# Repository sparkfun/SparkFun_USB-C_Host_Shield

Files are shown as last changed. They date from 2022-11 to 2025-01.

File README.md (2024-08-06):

SparkFun USB-C Host Shield
========================================

<p align="center">
	<a href="https://github.com/sparkfun/SparkFun_USB-C_Host_Shield/issues" alt="Issues">
		</a>
	<a href="https://github.com/sparkfun/SparkFun_USB-C_Host_Shield/actions" alt="Actions">
		</a>
	<a href="https://github.com/sparkfun/SparkFun_USB-C_Host_Shield/blob/master/LICENSE.md" alt="License">
		</a>
	<a href="https://twitter.com/intent/follow?screen_name=sparkfun">
		</a>
</p>

SparkFun USB-C Host Shield (https://www.sparkfun.com/products/21247)

*[SparkFun USB-C Host Shield (DEV-21247)](https://www.sparkfun.com/products/21247)*

This new version of the [USB Host Shield](https://github.com/sparkfun/USB_Host_Shield) updates the USB Type-A connector to a USB-C connector and provides users with the option to power the shield from the `5V` or `VIN` pins. The USB-C female connector also supplies 5V as any normal USB *(downward facing)* port would.

The SparkFun USB Host Shield contains all of the digital logic and analog circuitry necessary to implement a USB peripheral/host controller with your Arduino. This means you could use your Arduino to interface with and control any USB 2.0 compatible device - thumbdrives, digital cameras, Bluetooth dongles, and much more!

A four-wire serial interface is used to communicate with the host controller chip, so the shield connects the Arduino's hardware SPI pins (D10-13) to the MAX3421E. All SPI signals are sent through a hex converter to step them down to 3.3V.

Repository Contents
-------------------

* **[/docs](/docs/)** - Online documentation files
	* [overrides](/docs/overrides/) - Customization files for the GitHub page's product documentation
	* [assets](/docs/assets/) - Folder containing all the file assets used for the product documentation
		* [board_files](/docs/assets/board_files/) - Files for the product design
			* [Eagle design files](/docs/assets/board_files/eagle_files.zip) (.zip)
			* [Schematic](/docs/assets/board_files/schematic.pdf) (.pdf)
			* [Dimensions](/docs/assets/board_files/dimensions.pdf) (.pdf)
		* [component_documentation](/docs/assets/component_documentation/) - Datasheets and manuals for hardware components
		* [img](/docs/assets/img/) - Images for the product documentation
	* [github](/docs/github/) - Files with instructions for filing GitHub issues/pull-requests
* **[/Firmware](/Firmware/)** - Example sketches demonstrating extra peripherals
* **[/Hardware](/Hardware/)** - Eagle design files (.brd, .sch)

Documentation
--------------
* **[Hookup Guide (mkdocs)](http://docs.sparkfun.com/SparkFun_USB-C_Host_Shield/)** - Hookup guide for the USB-C Host Shield hosted by GitHub pages.
   

*Need to download or print our hookup guide?*

* [Print *(Print to PDF)* from Single-Page View](http://docs.sparkfun.com/SparkFun_USB-C_Host_Shield/print_view)

Product Variants
----------------
* USB-C Host Shield (USB-C variant)
	* [DEV-21247](https://www.sparkfun.com/products/21247)- v1.0, Initial Release
* USB Host Shield
	* [DEV-09947](https://www.sparkfun.com/products/retired/9947)- v2.0, Fixes `GPX` and `RESET` pin connections
	* [DEV-09628](https://www.sparkfun.com/products/retired/9628)- v1.0, Initial Release

Version History
---------------
* [v01](https://github.com/sparkfun/SparkFun_USB-C_Host_Shield/releases/tag/v10) - Initial Release

License Information
-------------------

This product is _**open source**_! 

Please review the LICENSE.md file for license information.

If you have any questions or concerns about licensing, please contact technical support on our [SparkFun forums](https://forum.sparkfun.com/viewforum.php?f=152).

Distributed as-is; no warranty is given.

- Your friends at SparkFun.

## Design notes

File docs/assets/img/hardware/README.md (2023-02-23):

img/hardware directory
====================
This folder should contain the images for the hardware overview and assembly pages

## Hardware Overview
* `dimensions.jpg` - Board Dimensions
* `power_connections.jpg` - An annotated image of the potential power connections
* `LED_pwr.jpg` - An annotated image of the power LED
* `switches.jpg` - An annotated image of the power switches on the shield
* `usb_connector.jpg` - An annotated image of the USB connector
* `MAX3421E.jpg` - An annotated image of the MAX3421E USB peripheral/host controller
* `pins_spi.jpg` - An annotated image of the SPI pins
* `pins_io.jpg` - An annotated image of the shield's I/O pins
* `pins_gpio.jpg` - An annotated image of the MAX3421E's GPIO pins
* `button_reset.jpg` - An annotated image of the reset button
* `jumpers.jpg` - An annotated image of all the jumpers

## Hardware Assembly
* `assembly_usb.jpg` - Image of board w/ USB cable connected
* `assembly_headers.jpg` - Image of board w/ headers being soldered

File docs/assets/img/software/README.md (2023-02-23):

img/software directory
====================
This folder should contain the images for the software overview and Arduino example pages

## Software Overview
* `arduino_library.jpg` - Image of the Arduino library selection in the Arduino IDE
    * `arduino_library-legacy.jpg` - Image of the Arduino library selection in the Arduino IDE (Arduino IDE v1.x.x)
* `board_selection.jpg` - Image of the board definition selection in the Arduino IDE
    * `board_selection2.jpg` - Image of the board definition selection in the Arduino IDE (alternative method)
* `port.png` - Image of the COM port selection
    * `port2.png` - Image of the COM port selection (alternative method)

### Arduino Examples
* `example-<name>.png` - Image of the example codes being selected from the File drop-down menu
* `usb_controller.jpg` - Image of the example setup for a USB connection to the game controller
* `bt_controller.jpg` - Image of the example setup for a Bluetooth connection to the game controller

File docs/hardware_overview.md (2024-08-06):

## Board Dimensions
The board dimensions are illustrated in the drawing below; the listed measurements are in inches.

<figure markdown>
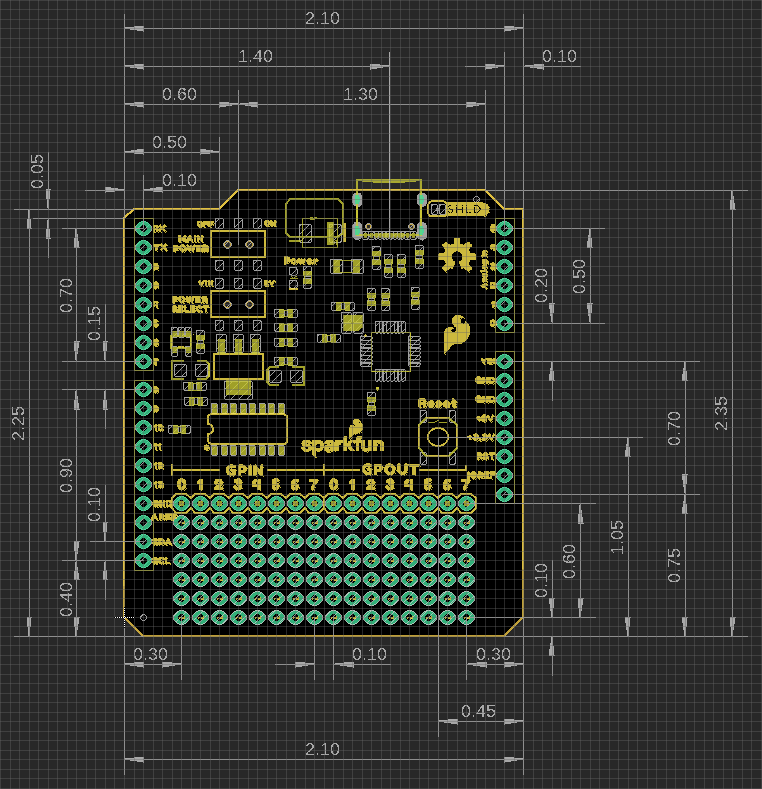
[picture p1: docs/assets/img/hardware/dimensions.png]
Board Dimensions Click to enlarge

<figcaption markdown>Board dimensions ([PDF](./assets/board_files/dimensions.pdf)) for the USB Host Shield, in inches.</figcaption>
</figure>

??? tip "Need more measurements?"
	For more information about the board's dimensions, users can download the [**Eagle files**](./assets/board_files/eagle_files.zip) for the board. These files can be opened in Eagle and additional measurements can be made with the dimensions tool.

	??? info ":octicons-download-16:{ .heart } Eagle - Free Download!"
		Eagle is a [CAD]("computer-aided design") program for electronics that is free to use for hobbyists and students. However, it does require an account registration to utilize the software.

		<center>
		[Download from<br>:autodesk-primary:{ .autodesk }](https://www.autodesk.com/products/eagle/free-download "Go to downloads page"){ .md-button .md-button--primary width="200px" }
		</center>

	??? info ":straight_ruler: Dimensions Tool"
		This video from Autodesk demonstrates how to utilize the dimensions tool in Eagle, to include additional measurements:

		<center>

		<div class="video">
		<iframe src="https://www.youtube.com/embed/dZLNd1FtNB8" title="EAGLE Dimension Tool" frameborder="0" allow="accelerometer; autoplay; clipboard-write; encrypted-media; gyroscope; picture-in-picture" allowfullscreen></iframe>

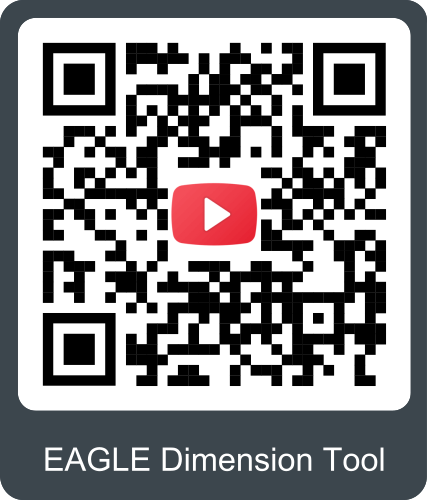
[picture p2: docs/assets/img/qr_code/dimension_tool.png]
QR code to instructional video
		
		</div>

		</center>

## Power
The MAX3421E USB controller only requires **3.3V** to operate; however, the shield *(and USB-C connector)* is powered entirely through either the `5V` or `VIN` pins of the connected Arduino board.

<figure markdown>
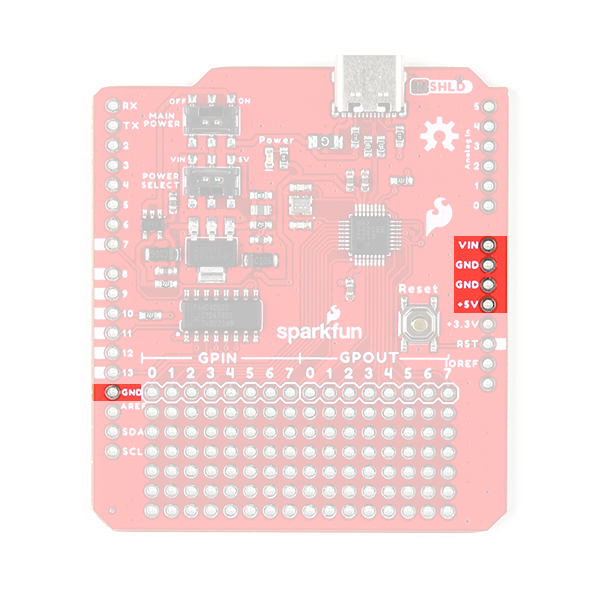
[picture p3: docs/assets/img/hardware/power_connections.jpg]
Power connections Click to enlarge

<figcaption markdown>USB Host Shield power connections.</figcaption>
</figure>

Below, is a general summary of the power circuitry on the board:

* **`VIN`** - Provides a regulated 3.3V and 5V for the shield
	* To utilize this pin, users will need to connect an external power source to the barrel jack of the Arduino board they are using.
* **`5V`** - Provides 5V and a regulated 3.3V for the shield
* **`GND`** - The common ground or the 0V reference for the voltage supplies.
* _**`VBUS`** - The voltage to the USB-C connector (**5V**)_
	* In reference to the `VBUS` net of the [schematic](./assets/board_files/schematic.pdf).
	* The available current is limited to what is supplied from the `VIN`/`5V` pin, up to the 750 mA threshold of the thermal fuse.

	!!! info
		When a PD device is connected and the voltage output drops below **4.75V**, the PD device will restrict its current draw to avoid potentially damaging the DFP *(downward-facing port)*.

*For more details, users can reference the [schematic](./assets/board_files/schematic.pdf) and the [datasheets of the individual components](../resources/#hardware-component-documentation) in the power circuitry.*

### Power LED
The red, power (`PWR`) LED will light up once **5V** is supplied to the shield. For most users, it will light up when power is supplied to the connected Arduino board.

<figure markdown>
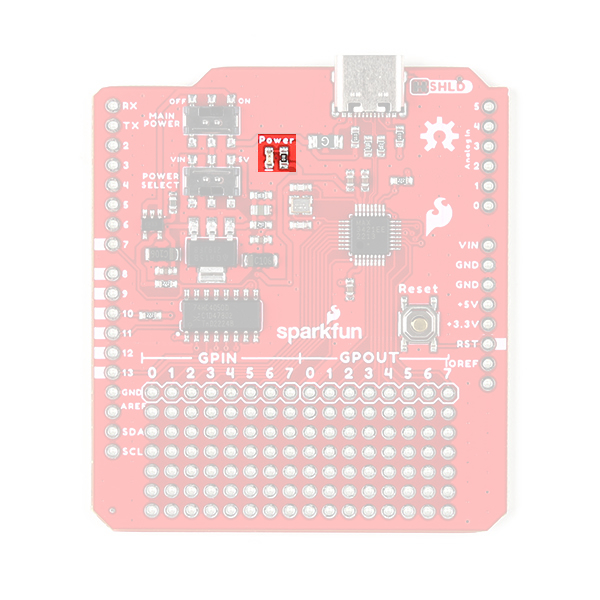
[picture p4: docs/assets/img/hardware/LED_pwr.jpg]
Power LED Click to enlarge

<figcaption markdown>USB Host Shield `PWR` status LED indicator.</figcaption>
</figure>

### Power Switches
There are two switches on the USB Host Shield. One provides a selectable power input for the shield *(`VIN` or `5V`)* and the other provides power control *(on/off)* to the shield and USB connector.

<figure markdown>
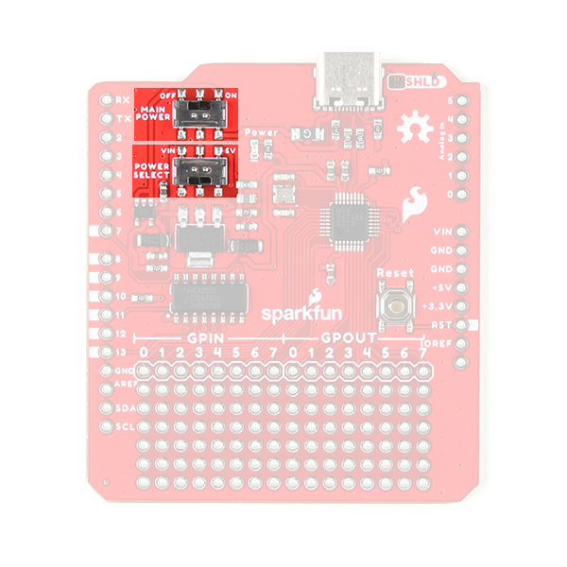
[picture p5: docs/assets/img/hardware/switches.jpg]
Switches Click to enlarge

<figcaption markdown>Power switches on the USB Host Shield.</figcaption>
</figure>

* Power Select<br>
	The power select switch allows users to easily choose the power supply for the shield. This switch mostly controls how the regulated 5V output for the USB-C connector is sourced. However, both options additionally supply the regulated 3.3V for the MAX3421E USB controller.
	* **VIN** - Draws power through the Arduino board's `VIN` pin
		* Provides a regulated 5V output to the USB-C connector from the `VIN` pin, which is separate/isolated from the `5V` pin of the Arduino board
		* Provides a regulated 3.3V output for the MAX3421E USB controller from the regulated 5V output of the `VIN` pin
	* **5V** - Draws power through the Arduino board's `5V` pin
		* Provides a 5V output to the USB-C connector from the `5V` pin of the Arduino board
		* Provides a regulated 3.3V output for the MAX3421E USB controller from the `5V` pin
* Main Power<br>
	The main power switch controls the power input to the shield. This switch turns the shield **on** or **off**; when off, the power output to the USB-C connector is also disabled.

### USB-C Connector
??? info "Charging PD Devices"
	When a PD device is connected and the voltage output drops below **4.75V**, the PD device will restrict its current draw to avoid potentially damaging the DFP *(downward-facing port)*.

The USB-C port supports limited power output at **5V**. The available current is limited to what is supplied to the shield from either the `VIN` or `5V` pin, up to the **750 mA** threshold of the thermal fuse.

<figure markdown>
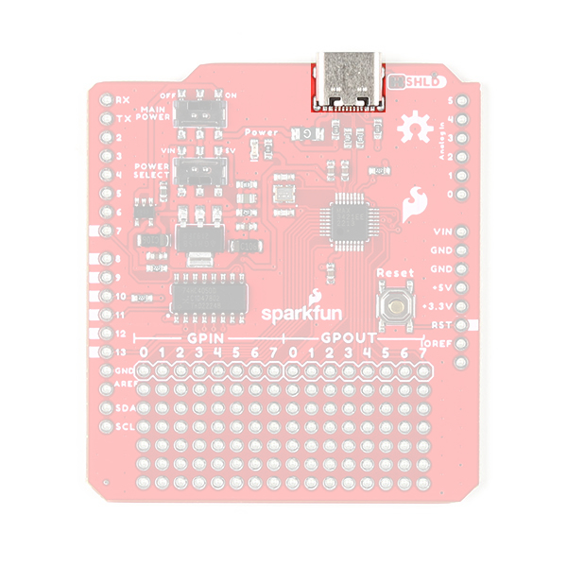
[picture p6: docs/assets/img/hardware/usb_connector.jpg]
USB power Click to enlarge

<figcaption markdown>USB-C connector on the USB Host Shield.</figcaption>
</figure>

## USB Controller
The [MAX3421E](./assets/component_documentation/MAX3421E.pdf) from [Maxim Integrated *(now part of Analog Devices)*](https://www.maximintegrated.com/), is a USB peripheral/host controller that can be implemented as a full-speed USB peripheral or a full-/low-speed host compliant *(USB specification rev 2.0)*. This allows for a vast collection of USB peripherals to be interfaced with an embedded system. The MAX3421E also includes eight general-purpose inputs and outputs so users can reclaim the I/O pins used for the SPI interface and gain additional ones.

<center>
<table>
	<tr>
		<td>
			<H3>Features</H3>
			<hr>
			<ul>
				<li>Provides USB Host and Peripheral Functionality
					<ul>
						<li>USB 2.0 Specification: 12 Mbps <i>(full-speed)</i></li>
						<li>16MB of Embedded SPI Flash Storage</li>
					</ul>
				</li>
				<li>Operating Voltage: 3.0 - 3.6 V</li>
				<li>Supply Current:
					<ul>
						<li>45 mA <i>(max)</i></li>
						<li>8.7 mA <i>(idle)</i></li>
						<li>30 - 60 &micro;A <i>(suspend)</i></li>
					</ul>
				</li>
				<li>SPI Clock Speed: 0 - 26 MHz</li>
				<li>Operating Temperature: -40 - +85 °C</li>
			</ul>
		</td>
		<td align="center">
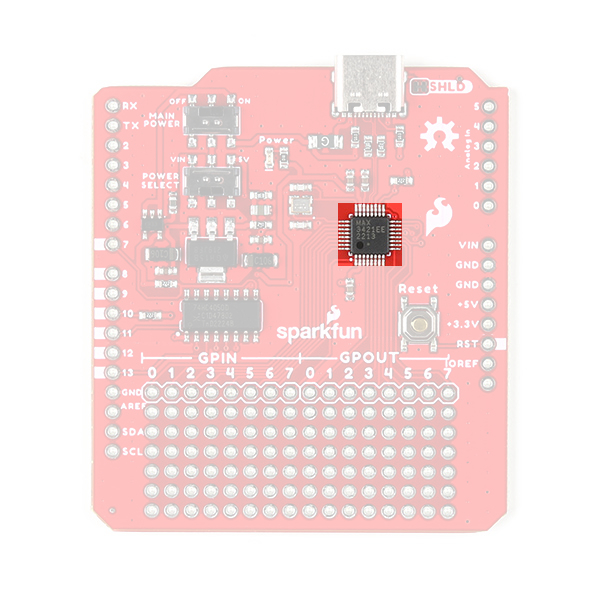
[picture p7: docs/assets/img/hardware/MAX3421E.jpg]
MAX3421E chip Click to enlarge
			<br>
			<i>MAX3421E chip on the USB-C Host Shield.</i>
		</td>
	<tr>
</table>
</center>

### I/O Pins
The MAX3421E is controlled with seven pins on the USB-C Host Shield. Additionally, the MAX3421E provides eight general-purpose inputs and outputs for users to reclaim their I/O pins and gain additional ones.

<div class="grid cards" markdown>

-	<figure markdown>
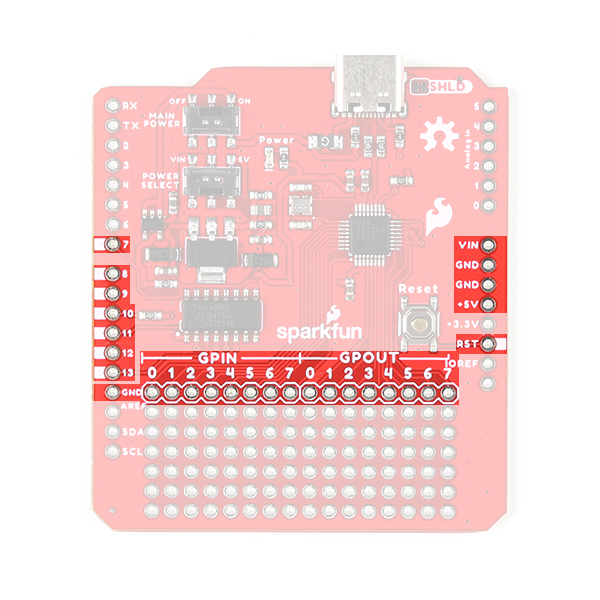
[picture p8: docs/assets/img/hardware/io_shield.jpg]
	
	<figcaption markdown>I/O pins used by the USB Host Shield.</figcaption>
	</figure>

-	=== "SPI Pins"

		* SCK: `D13`
		* POCI: `D12`
		* PICO: `D11`
		* CS: `D10`

	===	"I/O Pins"

		* INT: `D9`
		* GPX: `D8`
		* RST: `D7`

	=== "Power Pins"

		* `VIN`
		* `5V`
		* `GND`

		??? info
			For more information about the power pins, please refer to the [power section](#power) *(above)*.

</div>

??? tip "New Feature"
	New on this shield, we have added a silkscreen indicator to mark the I/O pins used by the shield. This should help users who are stacking other shields to avoid pin conflicts without referencing the documentation. 

	<figure markdown>
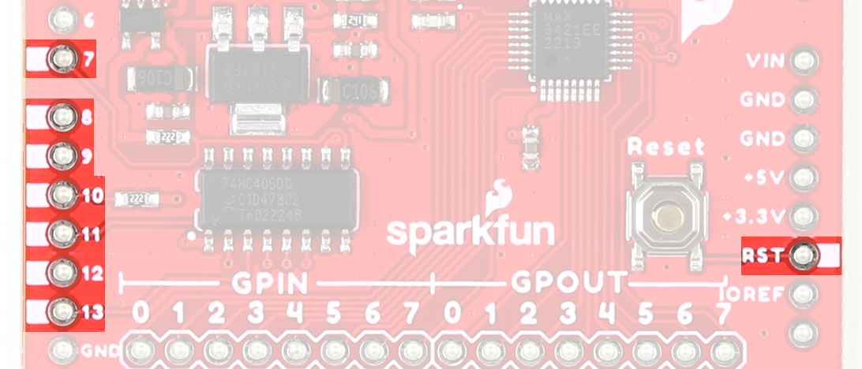
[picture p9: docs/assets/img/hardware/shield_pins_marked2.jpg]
	
	<figcaption markdown>I/O pins that are marked on the USB Host Shield.</figcaption>
	</figure>

#### SPI Pins
??? info "[OSHW](https://www.oshwa.org/) Compliance"
	To comply with the latest [OSHW](https://www.oshwa.org/) design practices, we have [adopted the new SPI signal nomenclature](https://www.sparkfun.com/spi_signal_names) (**SDO**/**SDI** and **PICO**/**POCI**). The terms Master and Slave are now referred to as Controller and Peripheral. The `MOSI` signal on a controller has been replaced with `SDO` or `PICO`. Please refer to this [announcement on the decision to deprecate the **MOSI**/**MISO** terminology and transition to the **SDO**/**SDI** naming convention](https://www.oshwa.org/a-resolution-to-redefine-spi-signal-names).

The MAX3421E operates using a register set, accessed by an SPI interface at speeds up to 26MHz. Any SPI controller can add USB peripheral or host functionality using the simple 3- or 4- wire SPI interface The USB-timed operations are performed inside the MAX3421E with interrupts provided at completion, so any SPI controller does not need timers to meet USB timing requirements. Additionally, the firmware to operate the MAX3421E can also be simplified to only support a specific target device.

<center>
	<table>
		<tr>
			<td style="vertical-align:middle;">
				<table>
					<tr>
						<th style="text-align:center">SCK</th>
						<td style="text-align:center"><code>D13</code> (<code>SCK</code>)</td>
					</tr>
					<tr>
						<th style="text-align:center">SDI or POCI</th>
						<td style="text-align:center"><code>D12</code> (<code>MISO</code>)</td>
					</tr>
					<tr>
						<th style="text-align:center">SDO or PICO</th>
						<td style="text-align:center"><code>D11</code> (<code>MOSI</code>)</td>
					</tr>
					<tr>
						<th style="text-align:center">CS</th>
						<td style="text-align:center"><code>D10</code> (<code>SS</code>)</td>
					</tr>
				</table>
			</td>
			<td align="center">
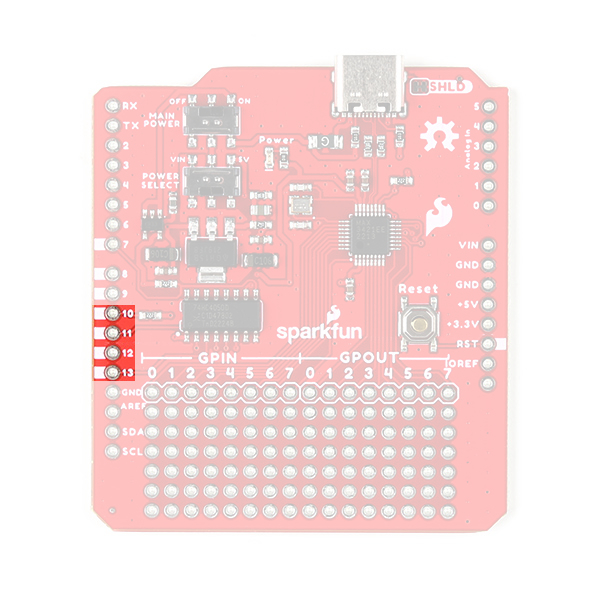
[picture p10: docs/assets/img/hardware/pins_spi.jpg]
Annotated image of SPI pins Click to enlarge
				
				<br>
				<i>Default SPI bus connections on the USB Host Shield.</i>
			</td>
		</tr>
	</table>
</center>

??? tip
	To learn more about the serial peripheral interface (SPI) protocol, check out this great <a href="https://learn.sparkfun.com/tutorials/serial-peripheral-interface-spi">tutorial</a>.
	<p align="center">
		<a href="https://learn.sparkfun.com/tutorials/16">Serial Peripheral Interface (SPI)<br>
		</a>
	</p>

#### I/O Pins
In addition to the SPI pins, there are three I/O pins for the MAX3421E.

<center>
	<table>
		<tr>
			<td style="vertical-align:middle;">
					<table>
						<tr>
							<th style="text-align:center">INT</th>
							<td style="text-align:center"><code>D9</code> <code>(Output)</code></td>
						</tr>
						<tr>
							<th style="text-align:center">GPX</th>
							<td style="text-align:center"><code>D8</code> <code>(Output)</code></td>
						</tr>
						<tr>
							<th style="text-align:center">RES</th>
							<td style="text-align:center"><code>D7</code> <code>(Input)</code></td>
						</tr>
					</table>
			</td>
			<td align="center">
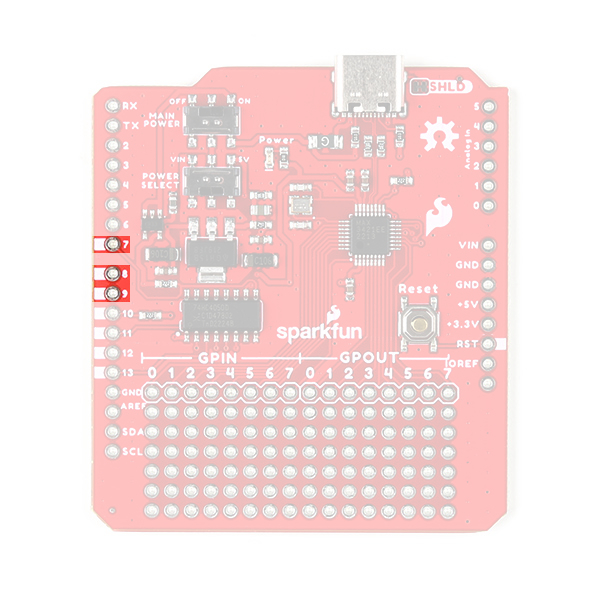
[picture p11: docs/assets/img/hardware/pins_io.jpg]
Annotated image of IO pins Click to enlarge
				
				<br>
				<i>I/O pins on the USB Host Shield.</i>
			</td>
		</tr>
	</table>
</center>

* `INT` - Interrupt (Output)

	The MAX3421E `INT` pin outputs a signal when a USB event occurs, which requires the attention of the SPI controller. In level mode, the `INT` pin is open-drain and active low. In edge mode, the pin can be operated as push-pull output with programmable polarity. Users can enable the interrupt by setting the IE bit in the CPUCTL (R16) register. The `INT` pin can also be configured to be triggered from the general-purpose inputs (`GPIN0`–`GPIN7`).

* `GPX` - General-Purpose Multiplexed (Output)
	
	The MAX3421E `GPX` pin indicates one of five internal signals:

	* `OPERATE` - The signal is high when the MAX3421E is able to operate after a power-up or `RES` reset.
	* `VBUS_DET` - Provides the `VBCOMP` comparator output.
	* `BUSACT` - The signal is active (high), whenever there is traffic on the USB bus.
	* `INIRQ` -  In this mode, `GPIN` interrupts appear only on the `GPX` pin, and do not appear on the `INT` output pin.
		* When the SEPIRQ bit of the MODE (R27) register is set high, the `BUSACT` signal is removed 
	* `SOF` - A square wave is produced, with a positive edge that indicates the USB start-of-frame.

	The internal MAX3421E signal that appears on `GPX` is programmable by writing to the `GPXB` and `GPXA` bits of the PINCTL (R17) register and the `SEPIRQ` bit of the MODE (R27) register. 

	<center>

	| GPXB | GPXA | GPX PIN OUTPUT |
	|:-:|:-:|:-:|
	| 0 | 0 | OPERATE (Default State) |
	| 0 | 1 | VBUS_DET |
	| 1 | 0 | BUSACT/INIRQ |
	| 1 | 1 | SOF |
	
	</center>

* `RES` - Device Reset (Input)

	Driving the `RES` pin low causes a chip reset on the MAX3421E. In a chip reset, all registers are reset to their default states, except for PINCTL (R17), USBCTL (R15), and SPI logic. To bring the MAX3421E out of chip reset, `RES` must be driven high.

	!!! note
		The MAX3421E is internally reset if either V<sub>CC</sub> or V<sub>L</sub> is not present. The register file is not accessible under these conditions.

#### MAX3421E I/O Pins
The MAX3421E also includes eight general-purpose inputs (8) and outputs (8), that can be used to reclaim the I/O pins used for the SPI interface and gain additional ones.

* `GPOUT#` - General-Purpose Push-Pull Outputs.
* `GPIN#` - General-Purpose Inputs.
	* `GPIN7`–`GPIN0` are connected to V<sub>L</sub> with internal pullup resistors.

<figure markdown>
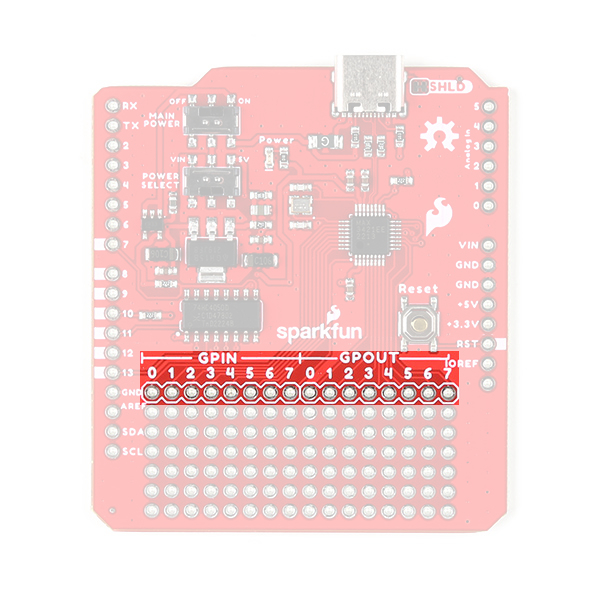
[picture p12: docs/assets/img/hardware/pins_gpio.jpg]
Annotated image of GPIO pins Click to enlarge

<figcaption markdown>GPIO pins on the USB Host Shield.</figcaption>
</figure>

### USB-C Connector
??? info "Charging PD Devices"
	When a PD device is connected and the voltage output drops below **4.75V**, the PD device will restrict its current draw to avoid potentially damaging the DFP *(downward-facing port)*.

The USB-C connector is used to provide provided an interface to the MAX3421 USB controller, which can function as either a USB peripheral or host. It also supports limited power output at **5V**. The available current is limited to what is supplied to the shield from either the `VIN` or `5V` pin, up to the **750 mA** threshold of the thermal fuse.

<figure markdown>
USB-C Connector Click to enlarge
<figcaption markdown>USB-C connector on the USB Host Shield.</figcaption>
</figure>

## Reset Button
Sometimes, an Arduino shield covers the ++"Reset"++ button of a user's Arduino board; therefore, a ++"Reset"++ button is provided on the USB-C Host shield. This allows users to easily reset their Arduino board without having to squeeze in between the Arduino board and shield to hit the button.

<figure markdown>
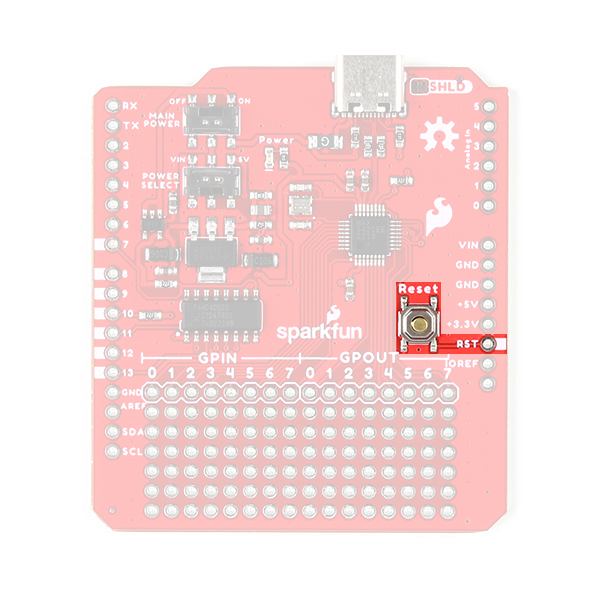
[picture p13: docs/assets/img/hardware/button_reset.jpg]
Reset Button Click to enlarge

<figcaption markdown>++"Reset"++ button and `RST` pin on the USB Host Shield.</figcaption>
</figure>

!!! note
	The reset button (`RST` pin) is different from the `RES` (reset) pin for the MAX3421E.
	
	* The button, `RST` pin on the shield, resets the microcontroller of the attached development board.
	* The `RES` pin, connected to pin `7` on the shield, is a chip reset for the MAX3421E.

## Jumper
There is a **SHLD** jumper on the top of the board that can be used to easily disconnect the shroud of the USB-C connector from `GND`.

??? tip "New to jumper pads?"
	Check out our [Jumper Pads and PCB Traces Tutorial](https://learn.sparkfun.com/tutorials/664) for a quick introduction!

	<div class="grid cards col-4" markdown align="center">

	-   <a href="https://learn.sparkfun.com/tutorials/664">
		<figure markdown>
		Tutorial thumbnail
		</figure>

		---
		
		**How to Work with Jumper Pads and PCB Traces**</a>

	</div>

<figure markdown>
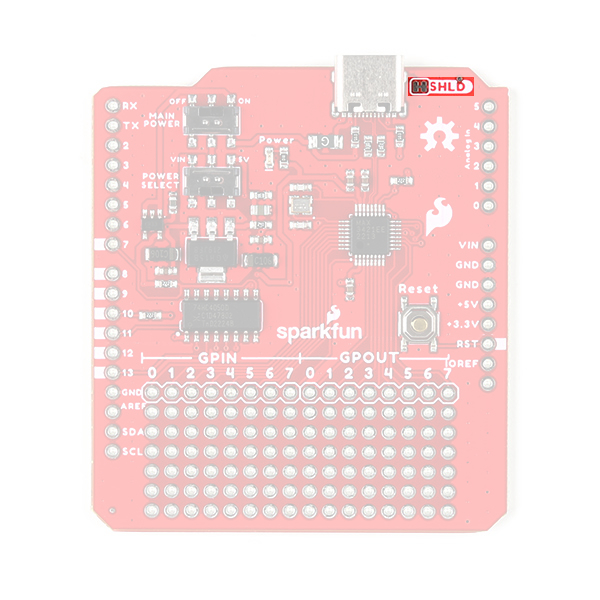
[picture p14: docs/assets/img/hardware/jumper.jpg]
Jumpers Click to enlarge

<figcaption markdown>The `SHLD` jumper on the top of the USB Host Shield.</figcaption>
</figure>

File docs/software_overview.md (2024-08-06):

## Arduino IDE
!!! tip
	For first-time users, who have never programmed before and are looking to use the Arduino IDE, we recommend beginning with the <a href="https://www.sparkfun.com/products/15631">SparkFun Inventor's Kit (SIK)</a>, which includes a simple board like the <a href="https://www.sparkfun.com/products/11224">Arduino Uno</a> or <a href="https://www.sparkfun.com/products/15123">SparkFun RedBoard</a> and is designed to help users get started programming with the Arduino IDE.

Most users may already be familiar with the Arduino IDE and its use. However, for those of you who have never heard the name *Arduino* before, feel free to check out the [Arduino website](https://www.arduino.cc/en/Guide/HomePage). To get started with using the Arduino IDE, check out our tutorials below:

<div class="grid cards" markdown align="center">

-   <a href="https://learn.sparkfun.com/tutorials/50">**What is an Arduino?**

	---

	<figure markdown>
	What is an Arduino?
	</figure></a>

-   <a href="https://learn.sparkfun.com/tutorials/61">**Installing the Arduino IDE**

	---
	
	<figure markdown>
	Installing the Arduino IDE
	</figure></a>

-   <a href="https://learn.sparkfun.com/tutorials/15">**Installing an Arduino Library**

	---
	
	<figure markdown>
	Installing an Arduino Library
	</figure></a>

-   <a href="https://learn.sparkfun.com/tutorials/1265">**Installing Board Definitions in the Arduino IDE**

	---
	
	<figure markdown>
	Installing Board Definitions in the Arduino IDE
	</figure></a>
</div>

??? tip "Need help setting up the RedBoard Plus?"
	### RedBoard Plus
	The following instructions should help users get started with the RedBoard Plus. For more information about the board, please check out our hookup guide below:

	<figure markdown>
	RedBoard Plus Hookup Guide (https://learn.sparkfun.com/tutorials/1758)
	<figcaption markdown>[**RedBoard Plus Hookup Guide**](https://learn.sparkfun.com/tutorials/1758)</figcaption>
	</figure>

	#### CH340 Driver
	Users will need to install the appropriate driver for their computer to recognize the serial-to-UART chip on their board/adapter. Most of the latest operating systems will recognize the CH340C chip on the board and automatically install the required driver.

	*To manually install the CH340 driver on their computer, users can download it from the [WCH website](http://www.wch-ic.com/products/CH340.html?). For more information, check out our [How to Install CH340 Drivers Tutorial](https://www.sparkfun.com/ch340).*

	<figure markdown>
	How to Install CH340 Drivers (https://learn.sparkfun.com/tutorials/908)
	<figcaption markdown>[**How to Install CH340 Drivers**](https://learn.sparkfun.com/tutorials/908)</figcaption>
	</figure>

	#### Arduino IDE
	When selecting a board to program in the Arduino IDE, users should select the **Arduino Uno** from the **Tools** drop-down menu _(_i.e. **Tools** > **Board** > **Arduino AVR Boards** > **Arduino Uno**)_.

	<figure markdown>
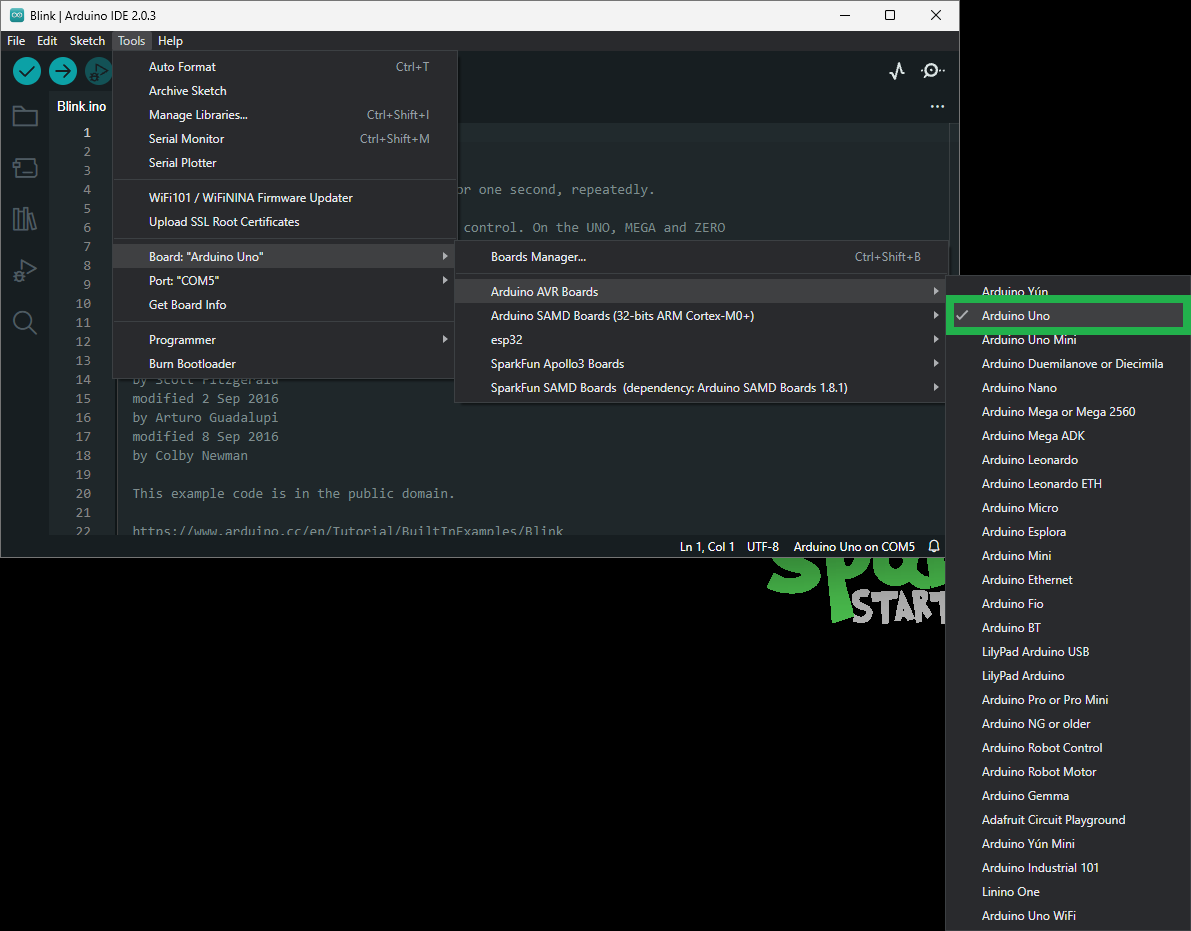
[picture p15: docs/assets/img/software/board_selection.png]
	
	<figcaption markdown>Select the **Arduino Uno** from the Tools drop-down menu in the Arduino IDE.</figcaption>
	</figure>

	??? info "Arduino IDE 2.x.x - *Alternative Method*"
		In the newest version of the Arduino IDE 2.`x`.`x`, users can also select their board (*green*) and port (*blue*) from the `Select Board & Port` dropdown menu (*yellow*).

		<figure markdown>
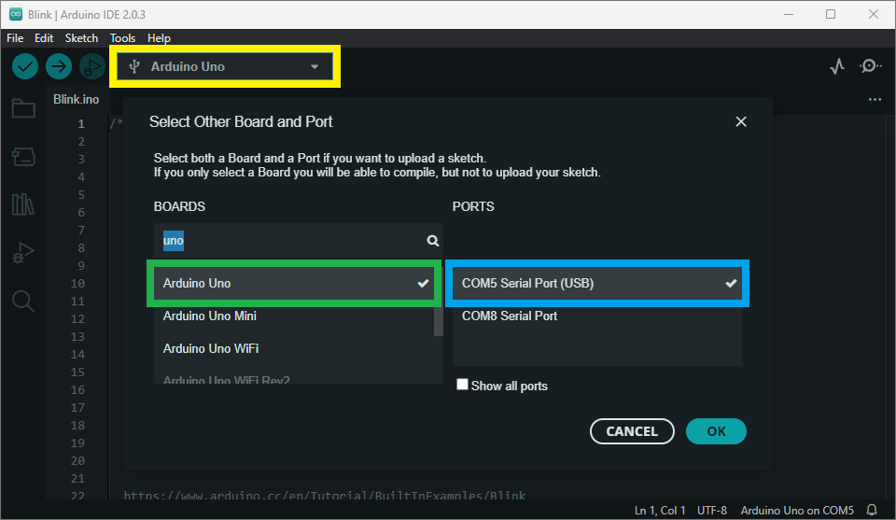
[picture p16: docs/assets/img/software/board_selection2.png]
		
		<figcaption markdown>Selecting the **Arduino Uno** and **COM5** port from the **Select Board & Port** drop-down menu in the Arduino IDE (v2.0.3).</figcaption>
		</figure>

### USB Host Library
The [USB Host Library Rev. 2.0](https://github.com/felis/USB_Host_Shield_2.0) can be installed from the library manager in the Arduino IDE.

<figure markdown>
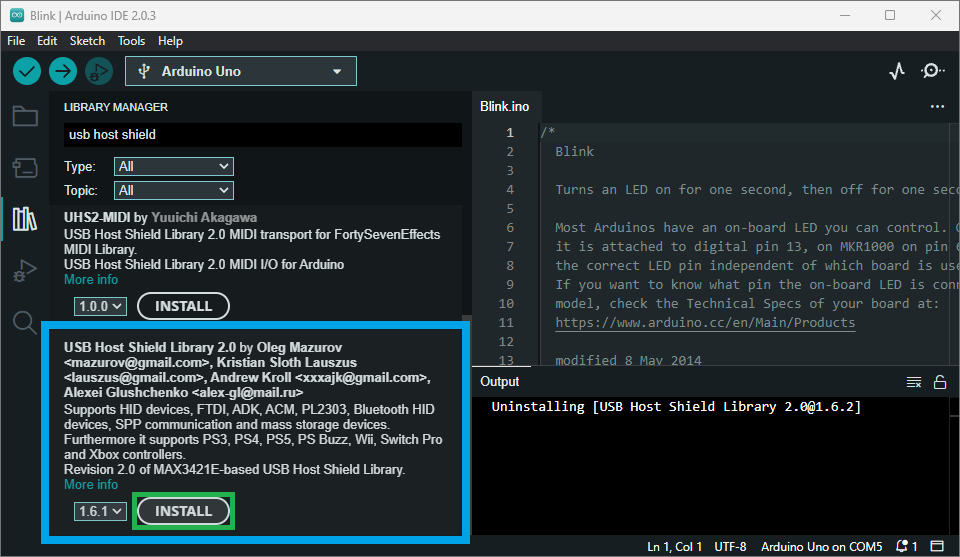
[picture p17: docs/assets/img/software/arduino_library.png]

<figcaption markdown>USB Host Library in the library manager of the Arduino IDE.</figcaption>
</figure>

!!! info
	For more details about the library, check out the [online documentation](https://felis.github.io/USB_Host_Shield_2.0/).

??? tip "Arduino IDE *(v1.x.x)*"
	In the Arduino IDE v1.x.x, the library manager will have the following appearance for the USB Host Shield library:

	<figure markdown>
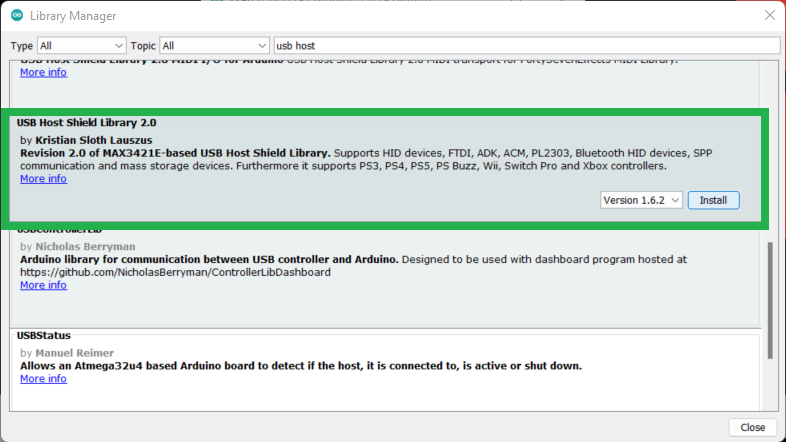
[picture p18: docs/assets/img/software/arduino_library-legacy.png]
	
	<figcaption markdown>USB Host Library in the library manager of the Arduino IDE (v1.x.x).</figcaption>
	</figure>

??? note "Alternative Libraries"
	Users are welcome to try other libraries for the MAX3421E, such as the ones listed below. However, our technical support team will only provide assistance with the [USB Host Library Rev. 2.0](https://github.com/felis/USB_Host_Shield_2.0) recommended in this hookup guide.

	* [Arduino-Bluetooth](https://github.com/felis/Arduino-Bluetooth)
	* [Lightweight USB Host](https://github.com/felis/lightweight-usb-host)
	* [MAX3421E project for STM32](https://github.com/jakakordez/max3421e-stm32)

#### Supported Boards
For a detailed and up-to-date list of boards supported by this library, check out the [`README.md` of the GitHub repository](https://github.com/felis/USB_Host_Shield_2.0#boards):

* All official Arduino AVR boards (Uno, Duemilanove, Mega, Mega 2560, Mega ADK, Leonardo etc.)
* Arduino Due
* Teensy (Teensy++ 1.0, Teensy 2.0, Teensy++ 2.0, Teensy 3.x, Teensy LC and Teensy 4.x)
	* For the Teensy 3.x, install this [SPI library](https://github.com/xxxajk/spi4teensy3) and add ```#include <spi4teensy3.h>``` to the `*.ino` sketch file.
* STM32F4
	* Take a look at the following [example code](https://github.com/Lauszus/Nucleo_F446RE_USBHost).
* ESP8266 is supported using the [ESP8266 Arduino core](https://github.com/esp8266/Arduino)
	* Uses pins `15` and `5` for `CS` and `INT`, respectively.
	  * `GPIO6` - `GPIO11` and `GPIO16` are **NOT** usable.
* ESP32 is supported using the [arduino-esp32](https://github.com/espressif/arduino-esp32/)
	* `GPIO5` : `CS`
	* `GPIO17` : `INT`
	* `GPIO18` : `SCK`
	* `GPIO19` : `POCI`
	* `GPIO23` : `PICO`

#### I/O Pin Modifications
The SPI pins used by this library are dictated by [SPI library](https://www.arduino.cc/reference/en/language/functions/communication/spi/) for the Arduino core being utilized and cannot be changed easily. It is recommended that the default pins of the SPI library be utilized.

However, the USB Host Library also declares its `CS` and `INT` pins. These pins can be reconfigured in the library by modifying the [UsbCore.h](https://github.com/felis/USB_Host_Shield_2.0/blob/master/UsbCore.h#L36-L58) file:

```C++
typedef MAX3421e< "CS Pin", "INT Pin" > MAX3421E;
```

For instance, if a user wanted to reconfigure the `CS` pin to `D7` and the `INT` pin to `D2` of the RedBoard Plus *(or any other Arduino Uno/ATmega328P based board)*, [line 58](https://github.com/felis/USB_Host_Shield_2.0/blob/master/UsbCore.h#L58) should read:

```C++
typedef MAX3421e<P7, P2> MAX3421E;
```

!!! tip
	The information above is an example of a pin modification. However, it is not required for the general use of the shield and the examples in this guide. For more information, please refer to the [instructions](https://github.com/felis/USB_Host_Shield_2.0#interface-modifications) in the [`README.md` of the GitHub repository](https://github.com/felis/USB_Host_Shield_2.0#readme).

	??? info "Other Boards"
		For other boards, users will need to modify the lines based on the microcontroller type. For example, with the [SparkFun IoT RedBoard](https://www.sparkfun.com/products/19177) users would need to modify [line 52](https://github.com/felis/USB_Host_Shield_2.0/blob/master/UsbCore.h#L52).

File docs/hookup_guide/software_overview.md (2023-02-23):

## Arduino IDE
!!! tip
	For first-time users, who have never programmed before and are looking to use the Arduino IDE, we recommend beginning with the <a href="https://www.sparkfun.com/products/15631">SparkFun Inventor's Kit (SIK)</a>, which includes a simple board like the <a href="https://www.sparkfun.com/products/11224">Arduino Uno</a> or <a href="https://www.sparkfun.com/products/15123">SparkFun RedBoard</a> and is designed to help users get started programming with the Arduino IDE.

Most users may already be familiar with the Arduino IDE and its use. However, for those of you who have never heard the name *Arduino* before, feel free to check out the [Arduino website](https://www.arduino.cc/en/Guide/HomePage). To get started with using the Arduino IDE, check out our tutorials below:

<table class="pdf" style="border-style:none" align="center">
	<tr>
		<td align="center">
			<a class="thumb" href="https://learn.sparkfun.com/tutorials/50">
				What is an Arduino?
				<h3 class="title">What is an Arduino?</h3>
			</a>
		</td>
		<td align="center">
			<a class="thumb" href="https://learn.sparkfun.com/tutorials/61">
				Installing Arduino IDE
				<h3 class="title">Installing Arduino IDE</h3>
			</a>
		</td>
		<td align="center">
			<a class="thumb" href="https://learn.sparkfun.com/tutorials/15">
				Installing an Arduino Library
				<h3 class="title">Installing an Arduino Library</h3>
			</a>
		</td>
		<td align="center">
			<a class="thumb" href="https://learn.sparkfun.com/tutorials/1265">
				Installing Board Definitions in the Arduino IDE
				<h3 class="title">Installing Board Definitions in the Arduino IDE</h3>
			</a>
		</td>
	</tr>
</table>

<div class="grid cards" markdown align="center">

-   <a href="https://learn.sparkfun.com/tutorials/50">**What is an Arduino?**

	---

	<figure markdown>
	What is an Arduino?
	</figure></a>

-   <a href="https://learn.sparkfun.com/tutorials/61">**Installing the Arduino IDE**

	---
	
	<figure markdown>
	Installing the Arduino IDE
	</figure></a>

-   <a href="https://learn.sparkfun.com/tutorials/15">**Installing an Arduino Library**

	---
	
	<figure markdown>
	Installing an Arduino Library
	</figure></a>

-   <a href="https://learn.sparkfun.com/tutorials/1265">**Installing Board Definitions in the Arduino IDE**

	---
	
	<figure markdown>
	Installing Board Definitions in the Arduino IDE
	</figure></a>
</div>

??? tip "Need help setting up the RedBoard Plus?"
	### RedBoard Plus
	The following instructions should help users get started with the RedBoard Plus. For more information about the board, please check out our hookup guide below:

	<figure markdown>
	RedBoard Plus Hookup Guide (https://learn.sparkfun.com/tutorials/1758)
	<figcaption markdown>[**RedBoard Plus Hookup Guide**](https://learn.sparkfun.com/tutorials/1758)</figcaption>
	</figure>

	#### CH340 Driver
	Users will need to install the appropriate driver for their computer to recognize the serial-to-UART chip on their board/adapter. Most of the latest operating systems will recognize the CH340C chip on the board and automatically install the required driver.

	*To manually install the CH340 driver on their computer, users can download it from the [WCH website](http://www.wch-ic.com/products/CH340.html?). For more information, check out our [How to Install CH340 Drivers Tutorial](https://www.sparkfun.com/ch340).*

	<figure markdown>
	How to Install CH340 Drivers (https://learn.sparkfun.com/tutorials/908)
	<figcaption markdown>[**How to Install CH340 Drivers**](https://learn.sparkfun.com/tutorials/908)</figcaption>
	</figure>

	#### Arduino IDE
	When selecting a board to program in the Arduino IDE, users should select the **Arduino Uno** from the **Tools** drop-down menu _(_i.e. **Tools** > **Board** > **Arduino AVR Boards** > **Arduino Uno**)_.

	<figure markdown>
	Click to enlarge
	<figcaption markdown>Select the **Arduino Uno** from the Tools drop-down menu in the Arduino IDE.</figcaption>
	</figure>

	??? info "Arduino IDE 2.x.x - *Alternative Method*"
		In the newest version of the Arduino IDE 2.`x`.`x`, users can also select their board (*green*) and port (*blue*) from the `Select Board & Port` dropdown menu (*yellow*).

		<figure markdown>
		Click to enlarge
		<figcaption markdown>Selecting the **Arduino Uno** and **COM5** port from the **Select Board & Port** drop-down menu in the Arduino IDE (v2.0.3).</figcaption>
		</figure>

### USB Host Library
The [USB Host Library Rev. 2.0](https://github.com/felis/USB_Host_Shield_2.0) can be installed from the library manager in the Arduino IDE.

<figure markdown>
Click to enlarge
<figcaption markdown>USB Host Library in the library manager of the Arduino IDE.</figcaption>
</figure>

!!! info
	For more details about the library, check out the [online documentation](https://felis.github.io/USB_Host_Shield_2.0/).

??? tip "Arduino IDE *(v1.x.x)*"
	In the Arduino IDE v1.x.x, the library manager will have the following appearance for the USB Host Shield library:

	<figure markdown>
	Click to enlarge
	<figcaption markdown>USB Host Library in the library manager of the Arduino IDE (v1.x.x).</figcaption>
	</figure>

??? note "Alternative Libraries"
	Users are welcome to try other libraries for the MAX3421E, such as the ones listed below. However, our technical support team will only provide assistance with the [USB Host Library Rev. 2.0](https://github.com/felis/USB_Host_Shield_2.0) recommended in this hookup guide.

	* [Arduino-Bluetooth](https://github.com/felis/Arduino-Bluetooth)
	* [Lightweight USB Host](https://github.com/felis/lightweight-usb-host)
	* [MAX3421E project for STM32](https://github.com/jakakordez/max3421e-stm32)

#### Supported Boards
For a detailed and up-to-date list of boards supported by this library, check out the [`README.md` of the GitHub repository](https://github.com/felis/USB_Host_Shield_2.0#boards):

* All official Arduino AVR boards (Uno, Duemilanove, Mega, Mega 2560, Mega ADK, Leonardo etc.)
* Arduino Due
* Teensy (Teensy++ 1.0, Teensy 2.0, Teensy++ 2.0, Teensy 3.x, Teensy LC and Teensy 4.x)
	* For the Teensy 3.x, install this [SPI library](https://github.com/xxxajk/spi4teensy3) and add ```#include <spi4teensy3.h>``` to the `*.ino` sketch file.
* STM32F4
	* Take a look at the following [example code](https://github.com/Lauszus/Nucleo_F446RE_USBHost).
* ESP8266 is supported using the [ESP8266 Arduino core](https://github.com/esp8266/Arduino)
	* Uses pins `15` and `5` for `CS` and `INT`, respectively.
	  * `GPIO6` - `GPIO11` and `GPIO16` are **NOT** usable.
* ESP32 is supported using the [arduino-esp32](https://github.com/espressif/arduino-esp32/)
	* `GPIO5` : `CS`
	* `GPIO17` : `INT`
	* `GPIO18` : `SCK`
	* `GPIO19` : `POCI`
	* `GPIO23` : `PICO`

#### I/O Pin Modifications
The SPI pins used by this library are dictated by [SPI library](https://www.arduino.cc/reference/en/language/functions/communication/spi/) for the Arduino core being utilized and cannot be changed easily. It is recommended that the default pins of the SPI library be utilized.

However, the USB Host Library also declares its `CS` and `INT` pins. These pins can be reconfigured in the library by modifying the [UsbCore.h](https://github.com/felis/USB_Host_Shield_2.0/blob/master/UsbCore.h#L36-L58) file:

```C++
typedef MAX3421e< "CS Pin", "INT Pin" > MAX3421E;
```

For instance, if a user wanted to reconfigure the `CS` pin to `D7` and the `INT` pin to `D2` of the RedBoard Plus *(or any other Arduino Uno/ATmega328P based board)*, [line 58](https://github.com/felis/USB_Host_Shield_2.0/blob/master/UsbCore.h#L58) should read:

```C++
typedef MAX3421e<P7, P2> MAX3421E;
```

!!! tip
	The information above is an example of a pin modification. However, it is not required for the general use of the shield and the examples in this guide. For more information, please refer to the [instructions](https://github.com/felis/USB_Host_Shield_2.0#interface-modifications) in the [`README.md` of the GitHub repository](https://github.com/felis/USB_Host_Shield_2.0#readme).

	??? info "Other Boards"
		For other boards, users will need to modify the lines based on the microcontroller type. For example, with the [SparkFun IoT RedBoard](https://www.sparkfun.com/products/19177) users would need to modify [line 52](https://github.com/felis/USB_Host_Shield_2.0/blob/master/UsbCore.h#L52).

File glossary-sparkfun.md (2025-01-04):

*[µSD]: micro SD

*[ADC]: Analog-to-Digital Converter
*[ASK]: Amplitude-Shift Keying
*[AREF]: Analog Reference Voltage
*[BDS]: 北斗卫星导航系统 (Chinese - BeiDou Navigation Satellite System)
*[BPSK]: Binary Phase-Shift Keying
*[BSP]: Board Software/Support Package
*[BLE]: Bluetooth Low-Energy
*[CAN]: Controller Area Network
*[CORS]: Continuously Operating Reference Station
*[CPU]: Central Processing Unit
*[CRC]: Cyclic Redundancy Check
*[CS]: Chip Select
*[CTS]: Clear-to-Send
*[DAC]: Digital-to-Analog Converter
*[DFU]: Device Firmware Update
*[DGPS]: Differential Global Positioning System
*[ECC]: Error Correction Code
*[exFAT]: Extensible File Allocation Table
*[FAT]: File Allocation Table
<!-- *[FAT16]: File Allocation Table-16 -->
<!-- *[FAT32]: File Allocation Table-32 -->
*[FSK]: Frequency-Shift Keying
<!-- *[GEO]: Geostationary Orbit or Geosynchronous Equatorial Orbit (see glossary-alt.md) -->
*[GFSK]: Gaussian Frequency Shift Keying
*[GLONASS]: Глобальная Навигационная Спутниковая Система (Russian - Global Navigation Satellite System)
*[GND]: Ground
*[GNSS]: Global Navigation Satellite System
*[GPIO]: General Purpose Input and Output
*[GPS]: Global Positioning System
*[GSO]: Geosynchronous Orbit
*[HAL]: Hardware Abstraction Layer
<!-- *[I2C] or [I<sup>2</sup>C]: Inter-Integrated Circuit (see glossary-alt.md) -->
*[ITM]: Instrumentation Trace Macrocell
*[IoT]: Internet of Things
*[JST]: Japan Solderless Terminal (Manufacturing)
*[JTAG]: Joint Test Action Group
*[LDO]: Low Dropout (Regulator)
*[LED]: Light Emitting Diode
*[LEO]:  Low Earth Orbit
<!-- *[LiPo]: Lithium-Ion Polymer or Lithium-Polymer (see glossary-alt.md) -->
*[LoRa]: Long Range
*[LoRaWAN]: Long Range Wide Area Network
*[MCU]: Microcontroller Unit
*[MEO]:  Medium Earth Orbit
*[MISO]: Master In Slave Out
*[MOSI]: Master Out Slave In
<!-- *[MPU]: Memory Protection Unit or Microprocessing Unit (see glossary-alt.md) -->
*[NavIC]: Navigation with Indian Constellation
*[NMEA]: National Marine Electronics Association
*[NiCd]: Nickel-Cadmium
*[NiMH]: Nickel-Metal Hydride
*[NTFS]: New Technology File System
*[NTRIP]: Networked Transport of RTCM via Internet Protocol
*[PCB]: Printed Circuit Board
*[PICO]: Peripheral In; Ccontroller Out
*[POCI]: Peripheral Out; Controller In
*[PSK]: Phase-Shift Keying
*[PSRAM]: Pseudo-Static RAM 
*[PWM]: Pulse Width Modulation
*[QSPI]: Quad-SPI
*[QPSK]: Quadrature Phase-Shift Keying
*[QZSS]: Quasi-Zenith Satellite System
*[RAM]: Random-Access Memory
*[RGB]: Red, Green, Blue
*[RINEX]: Receiver Independent Exchange (Format)
*[RST]: Reset
*[RTC]: Realtime Clock
*[RTCM]: Radio Technical Commission for Maritime (Services)
*[RTK]: Real-Time Kinematic (Positioning)
*[RTS]: Ready-to-Send
*[RX]: Receive
*[SBAS]: Satellite-Based Augmentation System
*[SCK]: Serial Clock
*[SCL]: Serial Clock
*[SD]: Secure Digital
*[SDA]: Serial Data
*[SDHC]: Secure Digital High Capacity
*[SDI]: Serial Data In
*[SDIO]: Serial Data In/Out
*[SDO]: Serial Data Out
*[SDUC]: Secure Digital Ultra Capacity
*[SDXC]: Secure Digital Extended Capacity
*[SPI]: Serial Peripheral Interface
*[SRAM]: Static Random-Access Memory
*[SS]: Slave Select
*[SWCLK]: Serial Wire Clock
*[SWD]: Serial Wire Debug
*[SWDIO]: Serial Wire Data Input/Output
*[SWO]: Serial Wire Output
*[SWV]: Serial Wire Viewer
*[TCK]: Test Clock
*[TDI]: Test Data In
*[TDO]: Test Data Out
*[TMS]: Test Mode Select
*[TRST]: Test Reset
*[TX]: Transmit
*[UART]: Universal Asynchronous Receiver-Transmitter
*[USB]: Universal Serial Bus
*[WDT]: Watchdog Timer

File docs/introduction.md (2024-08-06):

<!-- # Introduction -->

!!! attention
	This guide is specific to the [USB-C Host Shield](https://www.sparkfun.com/products/21247) board variant. For the variants with the USB (Type-A) connector, please refer to the [hookup guide, linked here](https://hardwarefun.com/tutorials/using-usb-host-shield-with-arduino).

<div class="grid cards desc" markdown>

<!-- **SparkFun USB-C Host Shield** (DEV-21247)  -->
-   <a href="https://www.sparkfun.com/products/21247">
	**USB-C Host Shield**<br>
	**SKU:** DEV-21247

	---

	<figure markdown>
	Product image
	</figure></a>

-	The [SparkFun USB-C Host Shield](https://www.sparkfun.com/products/21247) has similar features to our previous [USB Host Shield (v2)](https://www.sparkfun.com/products/retired/9947), but we upgraded the USB Type-A connector to a USB-C connector. Additionally, the board provides users with the option to select either the `5V` or  `VIN` pin to power the shield and USB port.

	The SparkFun USB Host Shield contains all of the digital logic and analog circuitry necessary to implement a USB peripheral/host controller with your Arduino board. This means you could use your Arduino microcontroller to interface with and control any USB 2.0 compatible device - flash drives, digital cameras, Bluetooth dongles, and much more!

	A four-wire serial interface is used to communicate with the host controller chip, so the shield connects the Arduino's hardware SPI pins (D10-13) to the MAX3421E. While the logic-level for the shield is 3.3V, all the SPI signals are sent through a hex converter to keep the shield compatible with any 5V Arduino boards.

	<center>
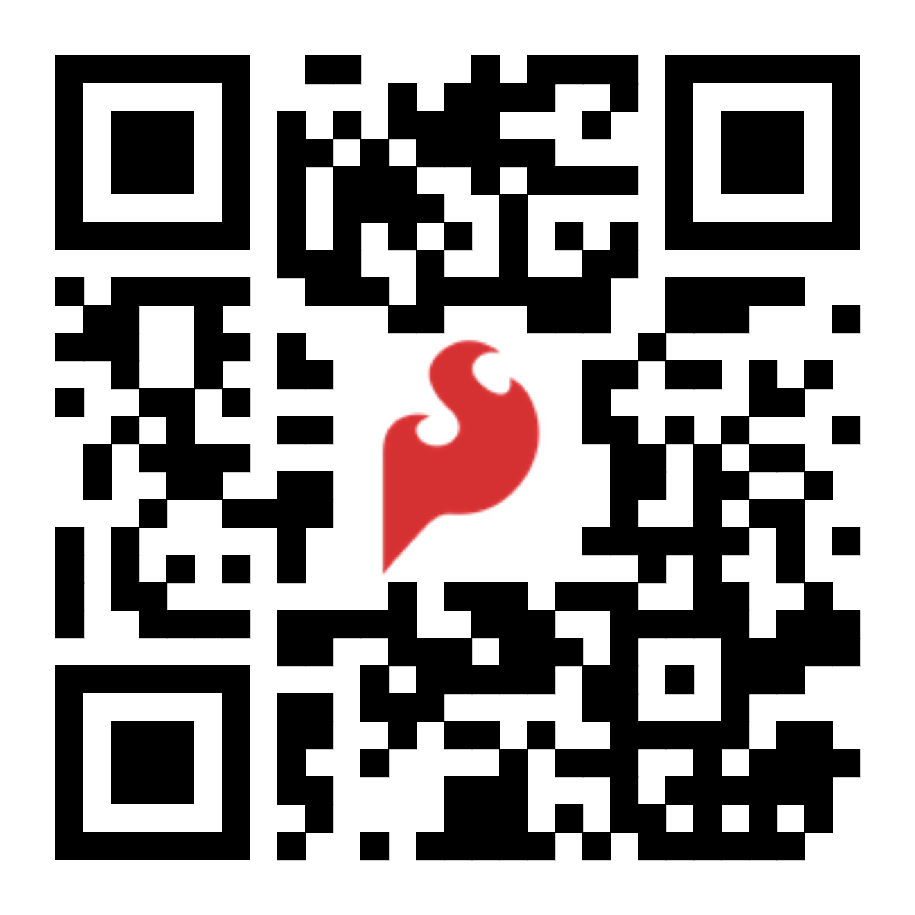
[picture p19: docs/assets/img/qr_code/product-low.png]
QR code to product page
	[&nbsp;&nbsp;&nbsp;Purchase from SparkFun :fontawesome-solid-cart-plus:{ .heart }&nbsp;&nbsp;&nbsp;](https://www.sparkfun.com/products/21247){ .md-button .md-button--primary }
	</center>

</div>

## Required Materials
To get started with the USB-C Host Shield, users will need a few additional items. Users may already have some of these items, feel free to modify your cart accordingly. For users just getting started with electronics, we have linked a few tutorials to establish a foundation of knowledge to follow along with this hookup guide.

* Computer with an operating system (OS) that is compatible with all the software installation requirements.
* A compatible microcontroller/Arduino board; we recommend the [SparkFun RedBoard Plus](https://www.sparkfun.com/products/18158).

	!!! warning
		The recommended Arduino library for the USB Host Shield is not compatible with all microcontrollers or boards. For a complete list of compatible microcontrollers and boards, please refer to the [`README.md` file](https://github.com/felis/USB_Host_Shield_2.0#boards) of USB Host Library Rev. 2.0.

* [USB 3.1 Cable A to C - 3 Foot](https://www.sparkfun.com/products/14743) - Used to interface with the RedBoard Plus (1)
{ .annotate }

	1.	If your computer doesn't have a USB-A slot or your microcontroller/Arduino board has a different USB connector, then choose an appropriate cable or adapter.

* [SparkFun USB-C Host Shield](https://www.sparkfun.com/products/21247)
* USB Peripheral Device *(i.e. [flash drive](https://www.sparkfun.com/products/14658), [game controller](https://www.sparkfun.com/products/17264), smartphone, etc.)* (1)
{ .annotate }

	1.	An [adapter](https://www.sparkfun.com/products/21870) or [cable](https://www.sparkfun.com/products/21271) may be necessary to interface with the peripheral device.

* Headers - Used to connect the shield to the Arduino board (1)
{ .annotate }

	1.	Check out some of the options for the [Arduino R3](https://www.sparkfun.com/products/11417)/Uno form factor boards below; otherwise, click here for a full selection of our available [headers](https://www.sparkfun.com/categories/381).

* Soldering Tools (1)
{ .annotate }

	1.	Check out the soldering kit below; otherwise, click here for a full selection of our available [soldering tools](https://www.sparkfun.com/categories/49).

<div class="grid cards" markdown>

-   <a href="https://www.sparkfun.com/products/14743">
	<figure markdown>
	USB 3.1 Cable A to C - 3 Foot
	</figure>

	---

	**USB 3.1 Cable A to C - 3 Foot**<br>
	CAB-14743</a>

-   <a href="https://www.sparkfun.com/products/18158">
	<figure markdown>
	SparkFun RedBoard Plus
	</figure>

	---

	**SparkFun RedBoard Plus**<br>
	DEV-18158</a>

-   <a href="https://www.sparkfun.com/products/21247">
	<figure markdown>
	SparkFun USB-C Host Shield
	</figure>

	---

	**SparkFun USB-C Host Shield**<br>
	DEV-21247</a>

-   <a href="https://www.sparkfun.com/products/116">
	<figure markdown>
	Product Thumbnail
	</figure>

	---

	**Break Away Headers - Straight**<br>
	PRT-00116</a>

-   <a href="https://www.sparkfun.com/products/11417">
	<figure markdown>
	Arduino Stackable Header Kit - R3
	</figure>

	---

	**Arduino Stackable Header Kit - R3**<br>
	PRT-11417</a>

</div>

!!! note "Headers"
	To attach the headers, users will need [soldering equipment](https://www.sparkfun.com/categories/49).

	??? tip "New to soldering?"
		Check out our [How to Solder: Through-Hole Soldering](https://learn.sparkfun.com/tutorials/5) tutorial for a quick introduction!

		<div class="grid cards col-4" markdown align="center">

		-   <a href="https://learn.sparkfun.com/tutorials/5">
			<figure markdown>
			Tutorial Thumbnail
			</figure>

			---
	
			**How to Solder: Through-Hole Soldering**</a>

		</div>

	<div class="grid cards col-4" markdown>

	-   <a href="https://www.sparkfun.com/products/9325">
		<figure markdown>
		Product Thumbnail
		</figure>		

		---

		**Solder Lead Free - 100-gram Spool**<br>
		TOL-09325</a>

	-   <a href="https://www.sparkfun.com/products/24063">
		<figure markdown>
		Product Thumbnail
		</figure>

		---
		
		**PINECIL Soldering Iron Kit**<br>
		KIT-24063</a>

	-   <a href="https://www.sparkfun.com/products/14579">
		<figure markdown>
		Product Thumbnail
		</figure>

		---

		**Chip Quik No-Clean Flux Pen - 10mL**<br>
		TOL-14579</a>

	</div>

??? note "Jumper Modification"
	To modify the [jumpers](../hardware_overview/#jumpers), users will need [soldering equipment](https://www.sparkfun.com/categories/49) and/or a [hobby knife](https://www.sparkfun.com/categories/379).

	!!! tip "New to jumper pads?"
		Check out our [Jumper Pads and PCB Traces Tutorial](https://learn.sparkfun.com/tutorials/664) for a quick introduction!

		<div class="grid cards col-4" markdown align="center">

		-   <a href="https://learn.sparkfun.com/tutorials/664">
			<figure markdown>
			Tutorial thumbnail
			</figure>

			---
			
			**How to Work with Jumper Pads and PCB Traces**</a>

		</div>

	<div class="grid cards col-4" markdown>

	-   <a href="https://www.sparkfun.com/products/22265">
		<figure markdown>
		Product Thumbnail
		</figure>		

		---

		**SparkFun Beginner Tool Kit**<br>
		TOL-22265</a>

	-   <a href="https://www.sparkfun.com/products/9200">
		<figure markdown>
		Product Thumbnail
		</figure>

		---

		**Hobby Knife**<br>
		TOL-09200</a>

	-   <a href="https://www.sparkfun.com/products/14579">
		<figure markdown>
		Product Thumbnail
		</figure>

		---

		**Chip Quik No-Clean Flux Pen - 10mL**<br>
		TOL-14579</a>

	</div>

### Arduino Examples
The following products are used in the Arduino examples shown in this hookup guide. Users are welcome to choose other products; however, these have been tested and verified to work with the examples.

<div class="grid cards" markdown>

-   <a href="https://www.sparkfun.com/products/16905">
	<figure markdown>
	USB 2.0 Type-C Cable - 1 Meter
	</figure>

	---

	**USB 2.0 Type-C Cable - 1 Meter**<br>
	CAB-16905</a>

-   <a href="https://www.sparkfun.com/products/21870">
	<figure markdown>
	USB A (Female) to Type C (Male) Converter
	</figure>

	---

	**USB A (Female) to Type C (Male) Converter**<br>
	COM-21870</a>

-   <a href="https://www.sparkfun.com/products/14658">
	<figure markdown>
	SparkFun USB Thumb Drive (16GB)
	</figure>

	---

	**SparkFun USB Thumb Drive (16GB)**<br>
	SWG-14658
</a>

-   <a href="https://www.sparkfun.com/products/9434">
	<figure markdown>
	Bluetooth USB Module Mini
	</figure>

	---

	**Bluetooth USB Module Mini**<br>
	WRL-09434</a>

-   <a href="https://www.sparkfun.com/products/17264">
	<figure markdown>
	8BitDo SN30 Pro Bluetooth Gamepad
	</figure>

	---

	**8BitDo SN30 Pro Bluetooth Gamepad**<br>
	WIG-17264</a>

</div>

## Suggested Reading

As a more sophisticated product, we will skip over the more fundamental tutorials (i.e. [**Ohm's Law**](https://learn.sparkfun.com/tutorials/voltage-current-resistance-and-ohms-law) and [**What is Electricity?**](https://learn.sparkfun.com/tutorials/what-is-electricity)). However, below are a few tutorials that may help users familiarize themselves with various aspects of the board.

<div class="grid cards" markdown align="center">

-   <a href="https://learn.sparkfun.com/tutorials/1167">**Arduino Shields v2**

	---

	<figure markdown>
	Arduino Shields v2
	</figure></a>

-   <a href="https://learn.sparkfun.com/tutorials/61">**Installing the Arduino IDE**

	---
	
	<figure markdown>
	Installing the Arduino IDE
	</figure></a>

-   <a href="https://learn.sparkfun.com/tutorials/15">**Installing an Arduino Library**

	---
	
	<figure markdown>
	Installing an Arduino Library
	</figure></a>

-   <a href="https://learn.sparkfun.com/tutorials/5">**How to Solder: Through-Hole Soldering**

	---
	
	<figure markdown>
	How to Solder: Through-Hole Soldering
	</figure></a>

-   <a href="https://learn.sparkfun.com/tutorials/664">**How to Work with Jumper Pads and PCB Traces**

	---
	
	<figure markdown>
	How to Work with Jumper Pads and PCB Traces
	</figure></a>

-   <a href="https://learn.sparkfun.com/tutorials/62">**Logic Levels**

	---
	
	<figure markdown>
	Logic Levels
	</figure></a>

-   <a href="https://learn.sparkfun.com/tutorials/16">**Serial Peripheral Interface (SPI)**

	---
	
	<figure markdown>
	Serial Peripheral Interface (SPI)
	</figure></a>
</div>

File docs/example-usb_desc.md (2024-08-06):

---
icon: simple/arduino
---

## USB Description
For our first example, we will be utilizing the [USB_dec](https://github.com/felis/USB_Host_Shield_2.0/tree/master/examples/USB_desc) example from the [USB_Host_Shield_2.0 Arduino library](https://github.com/felis/USB_Host_Shield_2.0). This example can be found in the **File** dropdown menu _(i.e. (1) **File** > **Examples** > **USB Host Shield Library 2.0** > **USB_Desc**)_. Once the example has been opened, users should see two files `USB_desc.ino` and `pgmstrings.h`.
{ .annotate }

1. <figure markdown>
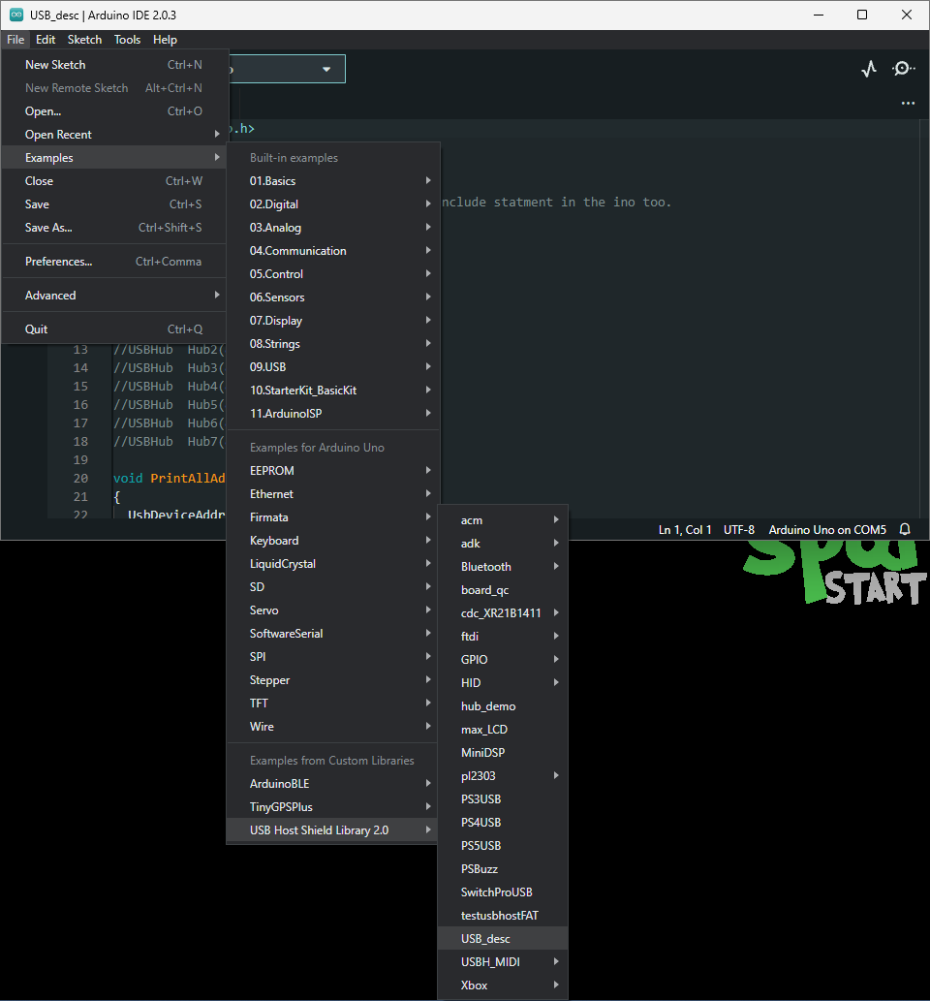
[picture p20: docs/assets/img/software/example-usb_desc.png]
    
    <figcaption markdown>Select the `USB_Desc` example sketch from the `File` drop-down menu.</figcaption>
    </figure>

??? code "Example Files"
    === "USB_desc.ino"

        ``` c++ linenums="1"
        --8<-- "https://raw.githubusercontent.com/felis/USB_Host_Shield_2.0/master/examples/USB_desc/USB_desc.ino"
        ```

    === "pgmstrings.h"
    
        ``` c++ linenums="1"
        --8<-- "https://raw.githubusercontent.com/felis/USB_Host_Shield_2.0/master/examples/USB_desc/pgmstrings.h"
        ```

Users will need to connect a peripheral USB device to the USB-C connector, before running the example. After the example begins, users should see an output in the [Serial Monitor](https://learn.sparkfun.com/tutorials/112) with a description of the connected USB device.

<figure markdown>
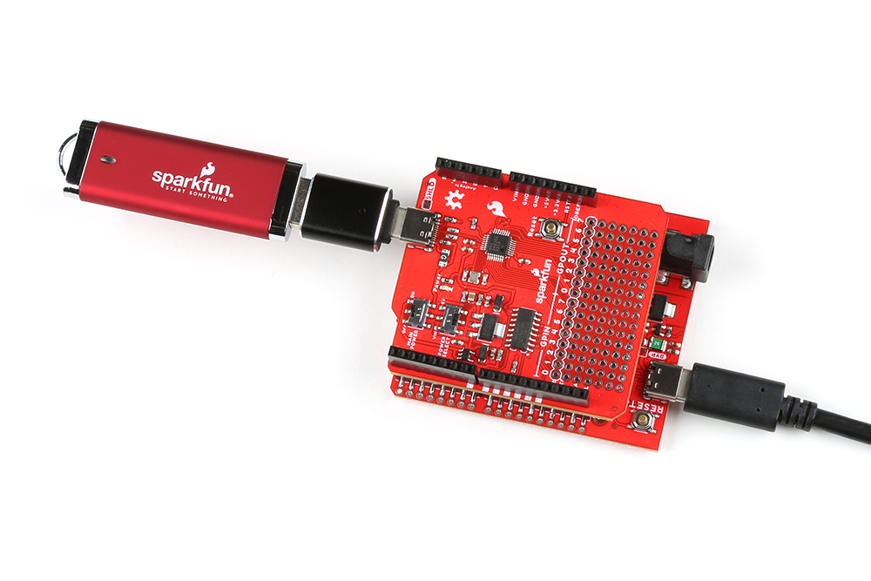
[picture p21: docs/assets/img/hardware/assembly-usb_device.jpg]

<figcaption markdown>The USB Host Shield with a [USB-C adapter](https://www.sparkfun.com/products/21870) and [flash drive](https://www.sparkfun.com/products/14658) attached.</figcaption>
</figure>

??? tip "USB Hubs"
    If users connect [USB hubs](https://en.wikipedia.org/wiki/USB_hub) or USB cables with a hub to the USB host shield, utilize the [hub_demo](https://github.com/felis/USB_Host_Shield_2.0/tree/master/examples/hub_demo) example from the [USB_Host_Shield_2.0 Arduino library](https://github.com/felis/USB_Host_Shield_2.0) instead. This example can be found in the **File** dropdown menu _(i.e. **File** > **Examples** > **USB Host Shield Library 2.0** > **hub_demo**)_ and will list the USB description for the hub(s) and all the peripheral devices connected to the hub(s).

    ??? info "Only interested in the USB hub description?"
        To see just the USB description for the hub(s) connected to the USB host shield, follow the information in the [library's FAQ](https://github.com/felis/USB_Host_Shield_2.0#faq). Utilizing the [USB_dec](https://github.com/felis/USB_Host_Shield_2.0/tree/master/examples/USB_desc) example, uncomment [lines 12-18](https://github.com/felis/USB_Host_Shield_2.0/blob/master/examples/USB_desc/USB_desc.ino#L12-L18)(1).
        { .annotate }

        1. Each instance of `#!c++ USBHub  Hub<number>(&Usb);` enables a USB hub, but the library is limited up to **seven** USB hubs. 

        ``` c++ linenums="11" hl_lines="2-8" title="USB_desc.ino"
        --8<-- "https://raw.githubusercontent.com/felis/USB_Host_Shield_2.0/master/examples/USB_desc/USB_desc.ino:11:19"
        ```

    <div class="grid cards" markdown>

    -   <a href="https://www.sparkfun.com/products/18014">**Qwiic USB Hub - USB2514B**<br>
        SPX-18014

        ---

        <figure markdown>
        Qwiic USB Hub - USB2514B
        </figure></a>

    -   <a href="https://www.sparkfun.com/products/21271">**SparkFun 4-in-1 Multi-USB Cable - USB-C Host**<br>
        CAB-21271

        ---
        
        <figure markdown>
        SparkFun 4-in-1 Multi-USB Cable - USB-C Host
        </figure></a>

    -   <a href="https://www.sparkfun.com/products/21272">**SparkFun 4-in-1 Multi-USB Cable - USB-A Host**<br>
        CAB-21272

        ---

        <figure markdown>
        SparkFun 4-in-1 Multi-USB Cable - USB-A Host
        </figure></a>

    </div>

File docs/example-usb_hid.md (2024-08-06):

---
icon: simple/arduino
---

## HID Keyboard and Mouse
In this example, we will be utilizing the [USBHIDBootKbdAndMouse](https://github.com/felis/USB_Host_Shield_2.0/tree/master/examples/HID/USBHIDBootKbdAndMouse) example from the [USB_Host_Shield_2.0 Arduino library](https://github.com/felis/USB_Host_Shield_2.0). This example can be found in the **File** dropdown menu _(i.e. (1) **File** > **Examples** > **USB Host Shield Library 2.0** > **HID** > **USBHIDBootKbdAndMouse**)_. Once the example has been opened, users should see the `USBHIDBootKbdAndMouse.ino` example sketch.
{ .annotate }

1. <figure markdown>
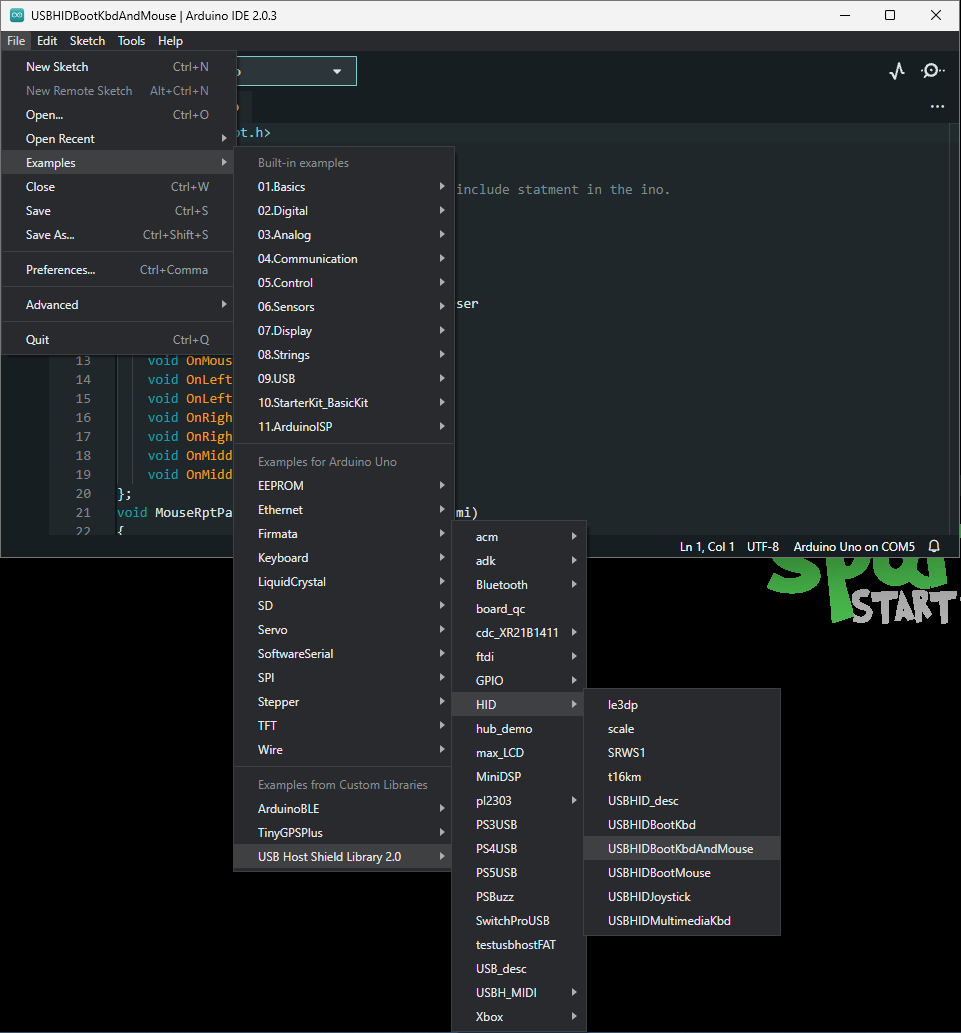
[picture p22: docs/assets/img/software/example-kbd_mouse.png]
Click to enlarge
    
    <figcaption markdown>Select the `USBHIDBootKbdAndMouse` example sketch from the `File` drop-down menu.</figcaption>
    </figure>

??? code "USBHIDBootKbdAndMouse.ino"
    ``` c++ linenums="1"
    --8<-- "https://raw.githubusercontent.com/felis/USB_Host_Shield_2.0/master/examples/HID/USBHIDBootKbdAndMouse/USBHIDBootKbdAndMouse.ino"
    ```

Users will need to connect an HID device *(keyboard and/or mouse)* to the USB-C host shield with a USB cable, before running the example. After the example begins, users should see an output in the [Serial Monitor](https://learn.sparkfun.com/tutorials/112) with print out based on the user's interaction with their HID device.

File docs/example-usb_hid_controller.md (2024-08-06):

---
icon: simple/arduino
---

## HID Game Controller

In these examples, we will be connecting the [8BitDo SN30 Pro](https://www.sparkfun.com/products/17264) to the USB-C host shield. Users will need the following items for the examples below:

<ul class="pdf" markdown>
  <li markdown>
  [8BitDo SN30 Pro Bluetooth Gamepad](https://www.sparkfun.com/products/17264)<br>
  For instructions on how to use the 8BitDo SN30 Pro, please refer to their [user manual](https://download.8bitdo.com/Manual/Controller/SN30pro+SF30pro/SN30pro_Manual.pdf).
  </li>
  <li markdown>[USB 2.0 Type-C Cable - 1 Meter](https://www.sparkfun.com/products/16905)</li>
  <li markdown>[USB A (Female) to Type C (Male) Converter](https://www.sparkfun.com/products/21870)</li>
  <li markdown>[Bluetooth USB Module Mini](https://www.sparkfun.com/products/9434)</li>
</ul>

<div class="grid cards" markdown>

-   <a href="https://www.sparkfun.com/products/17264">**8BitDo SN30 Pro Bluetooth Gamepad**<br>
	WIG-17264

	---

	<figure markdown>
	8BitDo SN30 Pro Bluetooth Gamepad
	</figure></a>

	??? info "8BitDo SN30 Pro Manual"
		For instructions on how to use the 8BitDo SN30 Pro, please refer to their [user manual](https://download.8bitdo.com/Manual/Controller/SN30pro+SF30pro/SN30pro_Manual.pdf).

-   <a href="https://www.sparkfun.com/products/16905">**USB 2.0 Type-C Cable - 1 Meter**<br>
	CAB-16905

	---

	<figure markdown>
	USB 2.0 Type-C Cable - 1 Meter
	</figure>
	<figcaption>(Coming Soon)</figcaption>
	</a>

-   <a href="https://www.sparkfun.com/products/21870">**USB A (Female) to Type C (Male) Converter**<br>
	COM-21870

	---

	<figure markdown>
	USB A (Female) to Type C (Male) Converter
	</figure>
	</a>

-   <a href="https://www.sparkfun.com/products/9434">**Bluetooth USB Module Mini**<br>
	WRL-09434

	---

	<figure markdown>
	Bluetooth USB Module Mini
	</figure>
	</a>

</div>

### USB Connection

In this example, we will be utilizing the [XBOXUSB](https://github.com/felis/USB_Host_Shield_2.0/tree/master/examples/Xbox/XBOXUSB) example from the [USB_Host_Shield_2.0 Arduino library](https://github.com/felis/USB_Host_Shield_2.0). This example can be found in the **File** dropdown menu _(i.e. (1) **File** > **Examples** > **USB Host Shield Library 2.0** > **Xbox** > **XBOXUSB**)_. Once the example has been opened, users should see the `XBOXUSB.ino` example sketch.
{ .annotate }

1. <figure markdown>
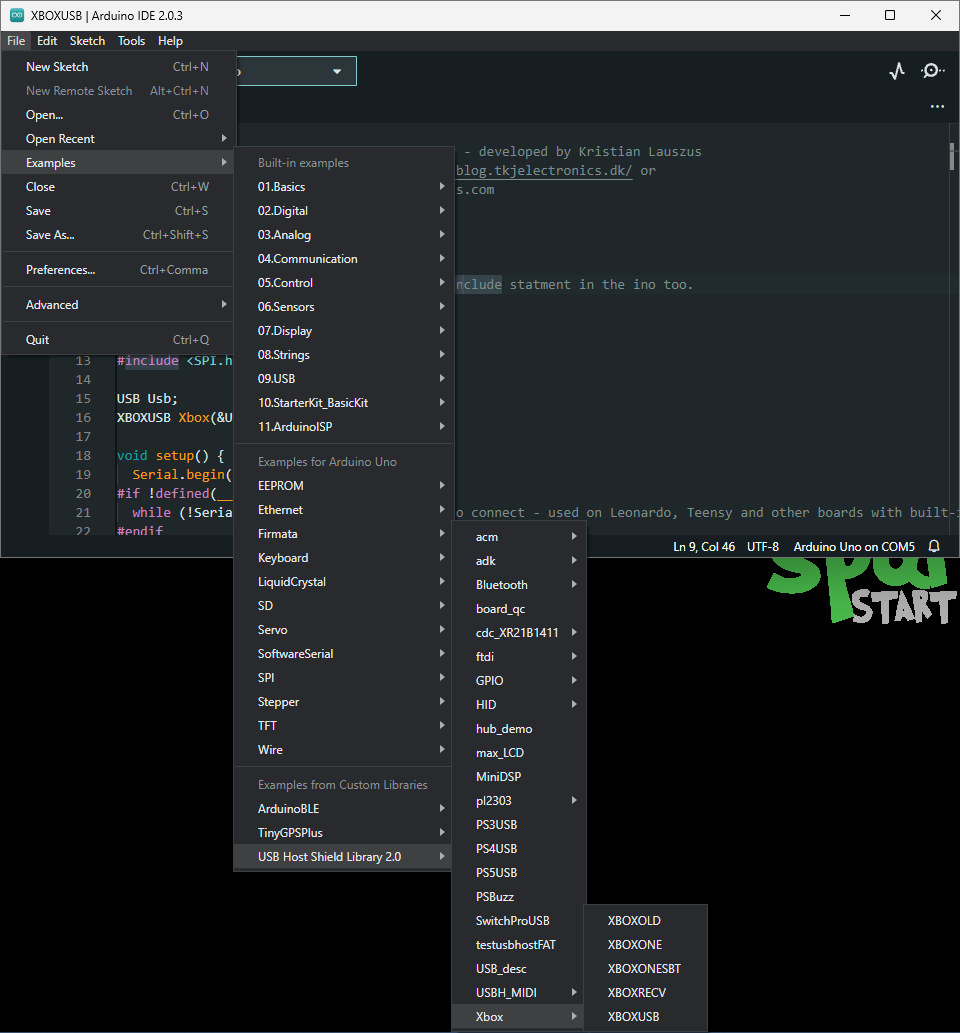
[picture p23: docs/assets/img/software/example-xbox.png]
    
    <figcaption markdown>Select the `XBOXUSB` example sketch from the `File` drop-down menu.</figcaption>
    </figure>

??? code "XBOXONE.ino"
	```  c++ linenums="1"
	--8<-- "https://raw.githubusercontent.com/felis/USB_Host_Shield_2.0/master/examples/Xbox/XBOXUSB/XBOXUSB.ino"
	```

Users will need to turn on and connect the controller to the USB-C host shield with a USB cable, before running the example.

<figure markdown>
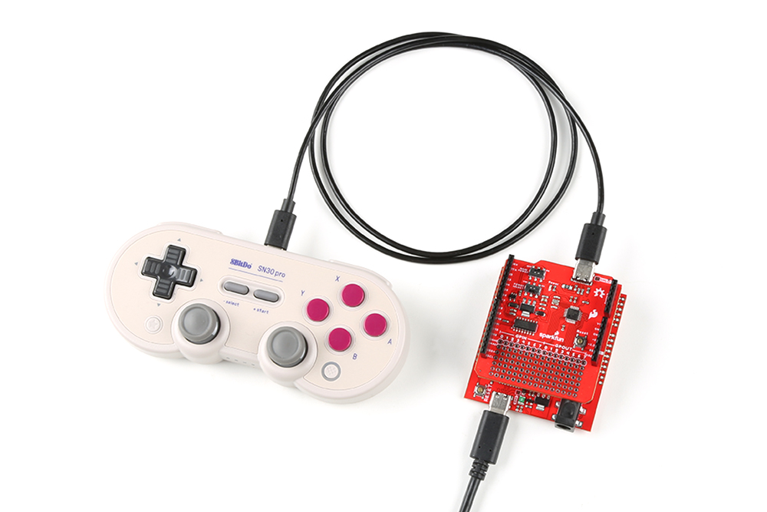
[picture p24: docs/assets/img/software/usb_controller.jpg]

<figcaption markdown>8BitDo controller connected to the USB-C Host Shield with a USB-C cable.</figcaption>
</figure>

!!! note
	To turn on the controller, press the ++"Start"+"X"++ buttons. Users should see two status LEDs blinking at the bottom of the controller.

After the example begins, users should see an output in the [Serial Monitor](https://learn.sparkfun.com/tutorials/112) with print out based on the user's interaction with their controller.

### Bluetooth Connection

In this example, we will be utilizing the [XBOXONESBT](https://github.com/felis/USB_Host_Shield_2.0/tree/master/examples/Xbox/XBOXONESBT) example from the [USB_Host_Shield_2.0 Arduino library](https://github.com/felis/USB_Host_Shield_2.0). This example can be found in the **File** dropdown menu _(i.e. (1) **File** > **Examples** > **USB Host Shield Library 2.0** > **Xbox** > **XBOXONESBT**)_. Once the example has been opened, users should see the `XBOXONESBT.ino` example sketch.
{ .annotate }

1. <figure markdown>
    Click to enlarge
    <figcaption markdown>Select the `XBOXONESBT` example sketch from the `File` drop-down menu.</figcaption>
    </figure>

??? code "XBOXONESBT.ino"
	``` c++ linenums="1"
	--8<-- "https://raw.githubusercontent.com/felis/USB_Host_Shield_2.0/master/examples/Xbox/XBOXONESBT/XBOXONESBT.ino"
	```

Users will need to connect the Bluetooth USB module to the USB-C host shield with the USB adapter before running the example. After the example begins, users should see an output in the [Serial Monitor](https://learn.sparkfun.com/tutorials/112) with print out based on the user's interaction with their controller.

<figure markdown>
Click to enlarge
<figcaption markdown>Bluetooth module connected to the USB-C Host Shield; and paired with an 8BitDo controller.</figcaption>
</figure>

!! note
	Make sure to wait until after the board restarts and executes the example, before pairing the 8BitDo controller with the Bluetooth module.

#### Bluetooth Pairing the Controller

To turn on the controller, press the ++"Start"+"X"++ buttons. Users should see two status LEDs blinking at the bottom of the controller. To pair the controller, press and hold the pair button at the top of the controller, next to the USB-C connector, for 3 seconds. Once paired, the controller should vibrate.

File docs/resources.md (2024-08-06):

## Product Resources
* [Product Page](https://www.sparkfun.com/products/21247)
* [Schematic](./assets/board_files/schematic.pdf) (PDF)
* [Eagle Files](./assets/board_files/eagle_files.zip) (ZIP)
* [Board Dimensions](./assets/board_files/dimensions.pdf) (PDF)
* Arduino Library: [USB Host Rev. 2.0](https://github.com/felis/USB_Host_Shield_2.0)
* [GitHub Hardware Repo](https://github.com/sparkfun/SparkFun_USB-C_Host_Shield)

### Additional Resources
* [Arduino Shields Tutorial (v2)](https://learn.sparkfun.com/tutorials/arduino-shields-v2)
* [Arduino Shields Product Category](https://www.sparkfun.com/categories/240)
* [SparkFun Technical Assistance](https://www.sparkfun.com/technical_assistance)

## Hardware Component Documentation
* USB Peripheral/Host Controller: [MAX3421E](./assets/component_documentation/MAX3421E.pdf) (PDF)
	* [Errata_MAX3421E](./assets/component_documentation/Errata_MAX3421E.pdf) (PDF)
	* [Programming Guide](./assets/component_documentation/AN3785.pdf) (PDF)
	* Technical Articles
		* [Article - Turn any video game controller into a USB mouse](https://pdfserv.maximintegrated.com/en/an/TUT5884.pdf) (PDF)
	* Application Notes
		* [The Maxim USB Laboratory](https://www.analog.com/media/en/technical-documentation/app-notes/the-maxim-usb-laboratory.pdf) (PDF)
		* [Setting Up the Maxim USB Laboratory](https://www.analog.com/media/en/technical-documentation/app-notes/setting-up-the-maxim-usb-laboratory.pdf) (PDF)
* Power Regulation:
	* [MIC5205](./assets/component_documentation/MIC5205.pdf) (PDF)
	* [LM1117](./assets/component_documentation/LM1117.pdf) (PDF)
* Logic-Level Converter:
	* [74HC4050](./assets/component_documentation/74HC4050.pdf) (PDF)

## Manufacturer's Resources
Maxim Integrated *(now part of Analog Devices)* also provides great resources for the MAX3421E USB Peripheral/Host Controller: 

* [MAX3421E Product Page](https://www.maximintegrated.com/en/products/interface/controllers-expanders/MAX3421E.html)
    * [Technical Documentation](https://www.maximintegrated.com/en/products/interface/controllers-expanders/MAX3421E.html#tech-docs)
* [Tutorial - Turn any video game controller into a USB mouse](https://www.maximintegrated.com/en/design/technical-documents/tutorials/5/5884.html)
* [Technical Support Page](https://maximsupport.microsoftcrmportals.com/en-US/tech-support/)
* [Knowledge Base Page](https://maximsupport.microsoftcrmportals.com/en-US/knowledgebase/)

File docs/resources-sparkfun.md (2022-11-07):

* [Product Page](https://www.sparkfun.com/products/21247)
* [SFE Product Showcase](https://youtu.be/g2MgO2fjqsw)
* [Arduino Shields Tutorial (v2)](https://learn.sparkfun.com/tutorials/arduino-shields-v2)
* [Arduino Shields Product Category](https://www.sparkfun.com/categories/240)
* [SparkFun Technical Assistance](https://www.sparkfun.com/technical_assistance)

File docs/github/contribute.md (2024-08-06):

# Contribute: Make an Augmentation!
Spot an improvement opportunity? Feel free to contribute to our open-source design and documentation. 

## :material-file-document-multiple:&nbsp;Improve our Documentation
All of this documentation can be modified by you! Please help us make it better.

* These pages are contained in the [`docs` folder](https://github.com/sparkfun/SparkFun_USB-C_Host_Shield/tree/main/docs) of the [SparkFun RA6M5 Thing Plus repository](https://github.com/sparkfun/SparkFun_USB-C_Host_Shield).

<!-- ### :material-source-pull:&nbsp;Submit a Correction -->
### Submit a Correction

1. With a GitHub account, [fork this repository](https://github.com/sparkfun/SparkFun_USB-C_Host_Shield/fork).
2. Add your corrections or improvements to the markdown file.
3. File a pull request with your changes, and enjoy making the ~~words~~ ~~worlds~~ world a better place.
	* Once received, the documentation specialist will automatically be notified.
	* We will review your suggested improvements to make sure they are correct and fit within our documentation standards.

## :material-cog:&nbsp;Improve our Hardware Design
All of our designs are open-source! Please help us make it better.

* Our board design files are contained in the [`Hardware` folder](https://github.com/sparkfun/SparkFun_USB-C_Host_Shield/tree/main/Hardware) of the [SparkFun RA6M5 Thing Plus repository](https://github.com/sparkfun/SparkFun_USB-C_Host_Shield).

<!-- ### :material-source-pull:&nbsp;Submit a Design Enhancement -->
### Submit a Design Enhancement

1. With a GitHub account, [fork this repository](https://github.com/sparkfun/SparkFun_USB-C_Host_Shield/fork).
2. Add your design augmentation(s)
3. File a pull request with your changes, and enjoy making the ~~words~~ ~~worlds~~ world a better place.
	1. Once received, the engineer in charge of the original design will automatically be notified.
	2. We will review your suggested improvement(s) to verify that they are within our board design standards and meet our product design requirements.
	3. If approved, we will flag these changes for our next board revision. Congrats! 🍻

		!!! info
			Even if your suggestion is accepted, these changes may not be immediately available for purchase. We may have to cycle through our current product inventory first.

## Contributors&nbsp;:clap:
Let's provide some recognition to the contributors for this project!

GitHub Contributors Image
<br>


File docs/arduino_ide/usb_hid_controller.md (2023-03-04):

---
icon: simple/arduino
---

## HID Game Controller

In these examples, we will be connecting the [8BitDo SN30 Pro](https://www.sparkfun.com/products/17264) to the USB-C host shield. Users will need the following items for the examples below:

<ul class="pdf" markdown>
  <li markdown>
  [8BitDo SN30 Pro Bluetooth Gamepad](https://www.sparkfun.com/products/17264)<br>
  For instructions on how to use the 8BitDo SN30 Pro, please refer to their [user manual](https://download.8bitdo.com/Manual/Controller/SN30pro+SF30pro/SN30pro_Manual.pdf).
  </li>
  <li markdown>[USB 2.0 Type-C Cable - 1 Meter](https://www.sparkfun.com/products/16905)</li>
  <li markdown>[USB A (Female) to Type C (Male) Converter](https://www.sparkfun.com/products/21870)</li>
  <li markdown>[Bluetooth USB Module Mini](https://www.sparkfun.com/products/9434)</li>
</ul>

<div class="grid cards" markdown>

-   <a href="https://www.sparkfun.com/products/17264">**8BitDo SN30 Pro Bluetooth Gamepad**<br>
	WIG-17264

	---

	<figure markdown>
	8BitDo SN30 Pro Bluetooth Gamepad
	</figure></a>

	??? info "8BitDo SN30 Pro Manual"
		For instructions on how to use the 8BitDo SN30 Pro, please refer to their [user manual](https://download.8bitdo.com/Manual/Controller/SN30pro+SF30pro/SN30pro_Manual.pdf).

-   <a href="https://www.sparkfun.com/products/16905">**USB 2.0 Type-C Cable - 1 Meter**<br>
	CAB-16905

	---

	<figure markdown>
	USB 2.0 Type-C Cable - 1 Meter
	</figure>
	<figcaption>(Coming Soon)</figcaption>
	</a>

-   <a href="https://www.sparkfun.com/products/21870">**USB A (Female) to Type C (Male) Converter**<br>
	COM-21870

	---

	<figure markdown>
	USB A (Female) to Type C (Male) Converter
	</figure>
	</a>

-   <a href="https://www.sparkfun.com/products/9434">**Bluetooth USB Module Mini**<br>
	WRL-09434

	---

	<figure markdown>
	Bluetooth USB Module Mini
	</figure>
	</a>

</div>

### USB Connection

In this example, we will be utilizing the [XBOXUSB](https://github.com/felis/USB_Host_Shield_2.0/tree/master/examples/Xbox/XBOXUSB) example from the [USB_Host_Shield_2.0 Arduino library](https://github.com/felis/USB_Host_Shield_2.0). This example can be found in the **File** dropdown menu _(i.e. (1) **File** > **Examples** > **USB Host Shield Library 2.0** > **Xbox** > **XBOXUSB**)_. Once the example has been opened, users should see the `XBOXUSB.ino` example sketch.
{ .annotate }

1. <figure markdown>
    Click to enlarge
    <figcaption markdown>Select the `XBOXUSB` example sketch from the `File` drop-down menu.</figcaption>
    </figure>

??? code "XBOXONE.ino"
	```  c++ linenums="1"
	--8<-- "https://raw.githubusercontent.com/felis/USB_Host_Shield_2.0/master/examples/Xbox/XBOXUSB/XBOXUSB.ino"
	```

Users will need to turn on and connect the controller to the USB-C host shield with a USB cable, before running the example.

<figure markdown>
Click to enlarge
<figcaption markdown>8BitDo controller connected to the USB-C Host Shield with a USB-C cable.</figcaption>
</figure>

!!! note
	To turn on the controller, press the ++"Start"+"X"++ buttons. Users should see two status LEDs blinking at the bottom of the controller.

After the example begins, users should see an output in the [Serial Monitor](https://learn.sparkfun.com/tutorials/112) with print out based on the user's interaction with their controller.

### Bluetooth Connection

In this example, we will be utilizing the [XBOXONESBT](https://github.com/felis/USB_Host_Shield_2.0/tree/master/examples/Xbox/XBOXONESBT) example from the [USB_Host_Shield_2.0 Arduino library](https://github.com/felis/USB_Host_Shield_2.0). This example can be found in the **File** dropdown menu _(i.e. (1) **File** > **Examples** > **USB Host Shield Library 2.0** > **Xbox** > **XBOXONESBT**)_. Once the example has been opened, users should see the `XBOXONESBT.ino` example sketch.
{ .annotate }

1. <figure markdown>
    Click to enlarge
    <figcaption markdown>Select the `XBOXONESBT` example sketch from the `File` drop-down menu.</figcaption>
    </figure>

??? code "XBOXONESBT.ino"
	``` c++ linenums="1"
	--8<-- "https://raw.githubusercontent.com/felis/USB_Host_Shield_2.0/master/examples/Xbox/XBOXONESBT/XBOXONESBT.ino"
	```

Users will need to connect the Bluetooth USB module to the USB-C host shield with the USB adapter before running the example. After the example begins, users should see an output in the [Serial Monitor](https://learn.sparkfun.com/tutorials/112) with print out based on the user's interaction with their controller.

<figure markdown>
Click to enlarge
<figcaption markdown>Bluetooth module connected to the USB-C Host Shield; and paired with an 8BitDo controller.</figcaption>
</figure>

!! note
	Make sure to wait until after the board restarts and executes the example, before pairing the 8BitDo controller with the Bluetooth module.

#### Bluetooth Pairing the Controller

To turn on the controller, press the ++"Start"+"X"++ buttons. Users should see two status LEDs blinking at the bottom of the controller. To pair the controller, press and hold the pair button at the top of the controller, next to the USB-C connector, for 3 seconds. Once paired, the controller should vibrate.

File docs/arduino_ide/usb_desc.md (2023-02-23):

---
icon: simple/arduino
---

## USB Description
For our first example, we will be utilizing the [USB_dec](https://github.com/felis/USB_Host_Shield_2.0/tree/master/examples/USB_desc) example from the [USB_Host_Shield_2.0 Arduino library](https://github.com/felis/USB_Host_Shield_2.0). This example can be found in the **File** dropdown menu _(i.e. (1) **File** > **Examples** > **USB Host Shield Library 2.0** > **USB_Desc**)_. Once the example has been opened, users should see two files `USB_desc.ino` and `pgmstrings.h`.
{ .annotate }

1. <figure markdown>
    Click to enlarge
    <figcaption markdown>Select the `USB_Desc` example sketch from the `File` drop-down menu.</figcaption>
    </figure>

??? code "Example Files"
    === "USB_desc.ino"

        ``` c++ linenums="1"
        --8<-- "https://raw.githubusercontent.com/felis/USB_Host_Shield_2.0/master/examples/USB_desc/USB_desc.ino"
        ```

    === "pgmstrings.h"
    
        ``` c++ linenums="1"
        --8<-- "https://raw.githubusercontent.com/felis/USB_Host_Shield_2.0/master/examples/USB_desc/pgmstrings.h"
        ```

Users will need to connect a peripheral USB device to the USB-C connector, before running the example. After the example begins, users should see an output in the [Serial Monitor](https://learn.sparkfun.com/tutorials/112) with a description of the connected USB device.

<figure markdown>
Click to enlarge
<figcaption markdown>The USB Host Shield with a [USB-C adapter](https://www.sparkfun.com/products/21870) and [flash drive](https://www.sparkfun.com/products/14658) attached.</figcaption>
</figure>

??? tip "USB Hubs"
    If users connect [USB hubs](https://en.wikipedia.org/wiki/USB_hub) or USB cables with a hub to the USB host shield, utilize the [hub_demo](https://github.com/felis/USB_Host_Shield_2.0/tree/master/examples/hub_demo) example from the [USB_Host_Shield_2.0 Arduino library](https://github.com/felis/USB_Host_Shield_2.0) instead. This example can be found in the **File** dropdown menu _(i.e. **File** > **Examples** > **USB Host Shield Library 2.0** > **hub_demo**)_ and will list the USB description for the hub(s) and all the peripheral devices connected to the hub(s).

    ??? info "Only interested in the USB hub description?"
        To see just the USB description for the hub(s) connected to the USB host shield, follow the information in the [library's FAQ](https://github.com/felis/USB_Host_Shield_2.0#faq). Utilizing the [USB_dec](https://github.com/felis/USB_Host_Shield_2.0/tree/master/examples/USB_desc) example, uncomment [lines 12-18](https://github.com/felis/USB_Host_Shield_2.0/blob/master/examples/USB_desc/USB_desc.ino#L12-L18)(1).
        { .annotate }

        1. Each instance of `#!c++ USBHub  Hub<number>(&Usb);` enables a USB hub, but the library is limited up to **seven** USB hubs. 

        ``` c++ linenums="11" hl_lines="2-8" title="USB_desc.ino"
        --8<-- "https://raw.githubusercontent.com/felis/USB_Host_Shield_2.0/master/examples/USB_desc/USB_desc.ino:11:19"
        ```

    <table class="pdf" style="border-style:none">
        <tr>
            <td>
                <a href="https://www.sparkfun.com/products/18014">
                    <center>Qwiic USB Hub - USB2514B</center>
                    <h3 class="title">Qwiic USB Hub - USB2514B</h3>
                </a>
                SPX-18014
            </td>
            <td>
                <a href="https://www.sparkfun.com/products/21271">
                    <center>SparkFun 4-in-1 Multi-USB Cable - USB-C Host
                    </center>
                    <h3 class="title">SparkFun 4-in-1 Multi-USB Cable - USB-C Host</h3>
                </a>
                CAB-21271
            </td>
            <td>
                <a href="https://www.sparkfun.com/products/21272">
                    <center>SparkFun 4-in-1 Multi-USB Cable - USB-A Host
                    </center>
                    <h3 class="title">SparkFun 4-in-1 Multi-USB Cable - USB-A Host</h3>
                </a>
                CAB-21272
            </td>
        </tr>
    </table>

    <div class="grid cards" markdown>

    -   <a href="https://www.sparkfun.com/products/18014">**Qwiic USB Hub - USB2514B**<br>
        SPX-18014

        ---

        <figure markdown>
        Qwiic USB Hub - USB2514B
        </figure></a>

    -   <a href="https://www.sparkfun.com/products/21271">**SparkFun 4-in-1 Multi-USB Cable - USB-C Host**<br>
        CAB-21271

        ---
        
        <figure markdown>
        SparkFun 4-in-1 Multi-USB Cable - USB-C Host
        </figure></a>

    -   <a href="https://www.sparkfun.com/products/21272">**SparkFun 4-in-1 Multi-USB Cable - USB-A Host**<br>
        CAB-21272

        ---

        <figure markdown>
        SparkFun 4-in-1 Multi-USB Cable - USB-A Host
        </figure></a>

    </div>

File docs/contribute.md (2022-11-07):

# Contribute: Help Fix our Mistake!
Spot something wrong? Feel free to contribute our open-source design and documentation. 

## Improve our Documentation
All of this documentation can be modified by you! Please help us make it better.

* These pages are contained in the [`docs` folder](https://github.com/sparkfun/SparkFun_USB-C_Host_Shield/tree/main/docs) of the [SparkFun USB-C Host Shield](https://github.com/sparkfun/SparkFun_USB-C_Host_Shield) repository.

### Submit a Correction
1. Fork this repo
2. Add your corrections or improvements to the markdown file
3. File a pull request with your changes, and enjoy making the ~~words~~ ~~worlds~~ world a better place.
    * Once received, the documentation specialist will automatically be notified.
    * We will review your suggested improvements to make sure they are correct and fit within our documentation standards.

## Improve our Hardware Design
All of our designs are open-source! Please help us make it better.

* Our board design files are contained in the [`Hardware` folder](https://github.com/sparkfun/SparkFun_USB-C_Host_Shield/tree/main/Hardware) of the [SparkFun USB-C Host Shield](https://github.com/sparkfun/SparkFun_USB-C_Host_Shield) repository. 

### Sumbit a Design Improvement
1. Fork this repo
2. Add your design improvements
3. File a pull request with your changes, and enjoy making the ~~words~~ ~~worlds~~ world a better place.
    * Once received, the engineer in charge of the original design will automatically be notified.
    * We will review your suggested improvements, if they are within our board design standards and meet our product design requirements, we will flag these changes for our next board revision. *(Please note, that even if your suggestion is accepted, these changes may not be immediate. We may have to cycle through our current product inventory first.)*

## Contributors
Let's provided some recognition to the contributors for this project!

GitHub Contributors Image
<br>


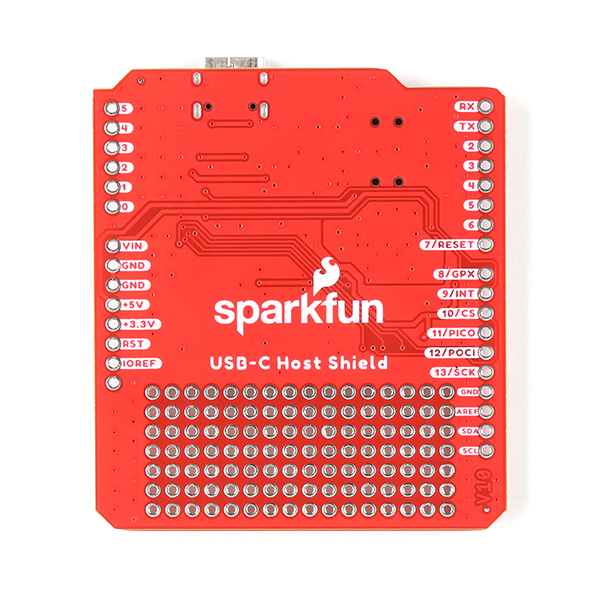
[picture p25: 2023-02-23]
docs/assets/img/hardware/bottom.jpg

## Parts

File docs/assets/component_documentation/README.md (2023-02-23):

component_documentation directory
====================

A copy of the datasheets, user manuals, programming guides, etc. of the major electrical components on the board.

* USB Peripheral/Host Controller: [MAX3421E](MAX3421E.pdf) (PDF)
	* [Errata_MAX3421E](Errata_MAX3421E.pdf) (PDF)
	* [Programming Guide](AN3785.pdf) (PDF)
	* Technical Articles
		* [Article - Turn any video game controller into a USB mouse](TUT5884.pdf) (PDF)
	* Application Notes
		* [The Maxim USB Laboratory](AN3936.pdf) (PDF)
		* [Setting Up the Maxim USB Laboratory](AN3937.pdf) (PDF)
		* [MAX3421E-Revisions 1 and 2 Host OUT Transfers](AN4000.pdf)
* Power Regulation:
	* [MIC5205](MIC5205.pdf) (PDF)
	* [LM1117](LM1117.pdf) (PDF)
* Logic-Level Converter:
	* [74HC4050](74HC4050.pdf) (PDF)

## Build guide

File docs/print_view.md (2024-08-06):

---
hide:
  - navigation
  - toc
icon: fontawesome/solid/scroll
---

# Introduction
--8<-- "./docs/introduction.md"

# Hardware Overview
--8<-- "./docs/hardware_overview.md"

# Hardware Assembly
--8<-- "./docs/hardware_assembly.md"

# Software Overview
--8<-- "./docs/software_overview.md"

# Arduino Examples
--8<-- "./docs/example-usb_desc.md:5"

--8<-- "./docs/example-usb_hid.md:5"

--8<-- "./docs/example-usb_hid_controller.md:5"

# Troubleshooting Tips
--8<-- "./docs/troubleshooting_tips.md"

# Resources:
--8<-- "./docs/resources.md"

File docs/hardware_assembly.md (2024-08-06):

!!! tip
	Users unfamiliar with using Arduino shields should refer to the [Arduino Shields (v2)](https://learn.sparkfun.com/tutorials/arduino-shields-v2) tutorial first.

	<div class="grid cards col-4" markdown align="center">

	-   <a href="https://learn.sparkfun.com/tutorials/1167">
		<figure markdown>
		Tutorial thumbnail
		</figure>

		---
		
		**Arduino Shields v2**</a>

	</div>

## Headers
The pins for the USB Host Shield are broken out to 0.1"-spaced pins on the outer edges of the board. When selecting headers, be sure you are aware of the functionality you need.

<figure markdown>
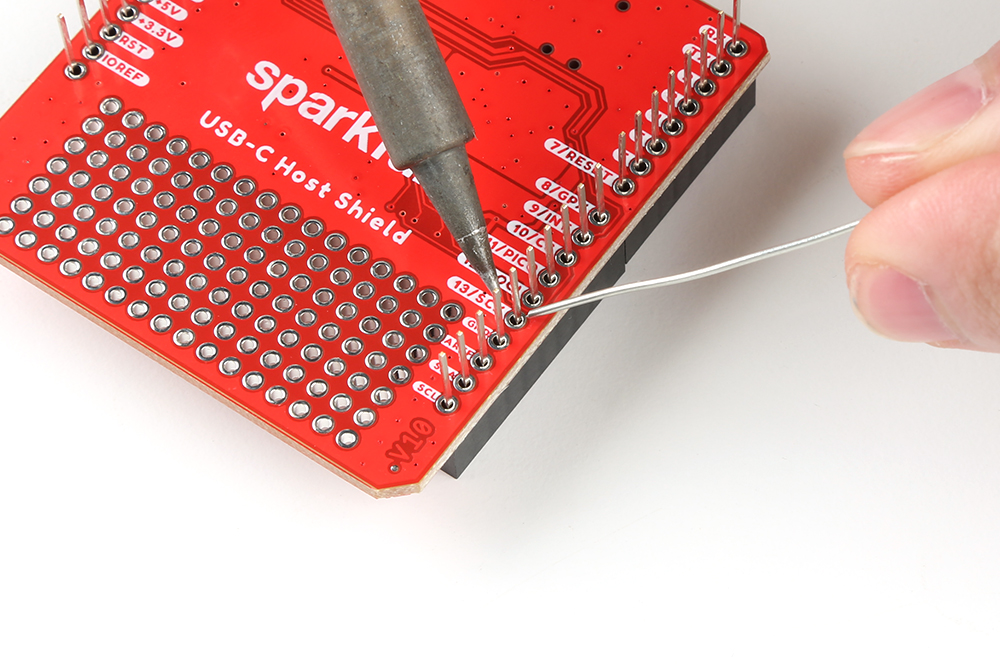
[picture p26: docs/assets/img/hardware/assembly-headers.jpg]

<figcaption markdown>Soldering headers to the USB Host Shield.</figcaption>
</figure>

!!! tip "New to soldering?"
	Check out our [How to Solder: Through-Hole Soldering](https://learn.sparkfun.com/tutorials/5) tutorial for a quick introduction!

	<div class="grid cards col-4" markdown align="center">

	-   <a href="https://learn.sparkfun.com/tutorials/5">
		<figure markdown>
		Tutorial Thumbnail
		</figure>

		---

		**How to Solder: Through-Hole Soldering**</a>

	</div>

The [Arduino Stackable Header Kit - R3](https://www.sparkfun.com/products/11417) is a great option as it allows users to stack shields (*w/ Uno/R3 footprint*); with the pins still accessible through the female headers.

<figure markdown>
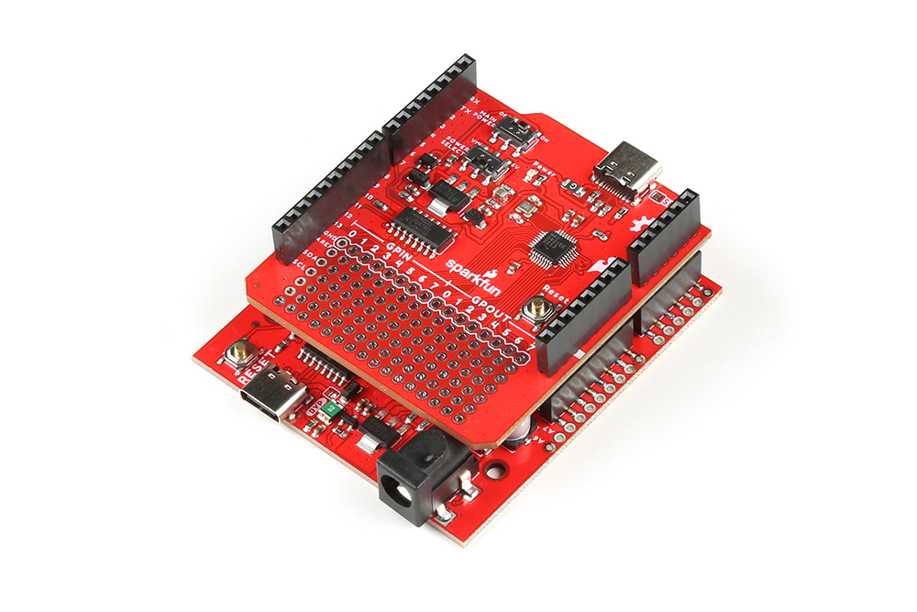
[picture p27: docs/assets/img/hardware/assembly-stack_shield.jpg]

<figcaption markdown>Stacking the USB Host Shield on the [SparkFun RedBoard Plus](https://www.sparkfun.com/products/18158).</figcaption>
</figure>

## USB Device
The USB port is utilized for the host/peripheral interface. Users only need to connect a USB device to the USB host shield or connect the shield to a computer with a USB-C cable.

<figure markdown>
Click to enlarge
<figcaption markdown>The USB Host Shield with a [USB-C adapter](https://www.sparkfun.com/products/21870) and [flash drive](https://www.sparkfun.com/products/14658) attached. The shield sits on top of a RedBoard Plus connected to a computer.</figcaption>
</figure>

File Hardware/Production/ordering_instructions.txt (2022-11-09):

panel size, 121x294mm
PCB thickness, 1.6mm
number of layers, 2
soldermask color, Red
silkscreen color, White
oz copper, 1oz
finish, HASL lead free
stencils, top
pcs per panel, 8
min trace width, 0.1270mm / 0.0050in
min drill size, 0.3500mm / 0.0138in

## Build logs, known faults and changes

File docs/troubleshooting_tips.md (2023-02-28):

!!! warning "Need Help?"
    If you need technical assistance or more information on a product that is not working as you expected, we recommend heading on over to the [SparkFun Technical Assistance](https://www.sparkfun.com/technical_assistance) page for some initial troubleshooting.

    <center>
    [SparkFun Technical Assistance Page](https://www.sparkfun.com/technical_assistance){ .md-button .md-button--primary }
    </center>
    
    If you can't find what you need there, the [SparkFun Forums](https://forum.sparkfun.com/index.php) is a great place to search for additional information and to ask questions.
    
    !!! info "Account Registration Required"
        If this is your first visit to our forum, you'll need to [register an account](https://forum.sparkfun.com/ucp.php?mode=register) to post questions.

## Initialization Failure
The following error message, in the serial terminal, indicates that there was a problem communicating with the MAX3421E chip.

>   ```
    OSC did not start
    ```

This error occurs here in the example code:

>   ```c++
    if (Usb.Init() == -1)
        Serial.println("OSC did not start.");
    ```

Here are a few steps users can perform to diagnose the issue:

* Double-check the hardware connections; including, but not limited to the solder joints, header pins (male and female), etc.
    * Disconnect power from the board and try a continuity test with a multimeter.
* Make sure the switches are in the correct position to provide power to the shield.
    * The shield requires a minimum 5V input voltage.
    * The red, power LED should be lit when the shield is powered.
* Double-check the library for any [I/O pin modifications](../software_overview/#io-pin-modifications).

## USB Hub
If users connect [USB hubs](https://en.wikipedia.org/wiki/USB_hub) or USB cables with a hub to the USB host shield, refer to the [hub_demo](https://github.com/felis/USB_Host_Shield_2.0/tree/master/examples/hub_demo) example from the [USB_Host_Shield_2.0 Arduino library](https://github.com/felis/USB_Host_Shield_2.0). This example can be found in the **File** dropdown menu _(i.e. **File** > **Examples** > **USB Host Shield Library 2.0** > **hub_demo**)_ and will list the USB description for the hub(s) and all the peripheral devices connected to the hub(s).

!!! info "Only interested in the USB hub description?"
    To see just the USB description for the hub(s) connected to the USB host shield, follow the information in the [library's FAQ](https://github.com/felis/USB_Host_Shield_2.0#faq). Utilizing the [USB_dec](https://github.com/felis/USB_Host_Shield_2.0/tree/master/examples/USB_desc) example, uncomment [lines 12-18](https://github.com/felis/USB_Host_Shield_2.0/blob/master/examples/USB_desc/USB_desc.ino#L12-L18)(1).
    { .annotate }

    1. Each instance of `#!c++ USBHub  Hub<number>(&Usb);` enables a USB hub, but the library is limited up to **seven** USB hubs. 

    ``` c++ linenums="11" hl_lines="2-8" title="USB_desc.ino"
    --8<-- "https://raw.githubusercontent.com/felis/USB_Host_Shield_2.0/master/examples/USB_desc/USB_desc.ino:11:19"
    ```

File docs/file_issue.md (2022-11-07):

# Did we make a mistake?

Spot something wrong? Please let us know. 

!!! attention
    This is not where customers should seek assistance on a product. If you require technical assistance or have questions about a product that is not working as expected, please head over to the [SparkFun Technical Assistance](https://www.sparkfun.com/technical_assistance) page for some initial troubleshooting.
    <center>
    [SparkFun Technical Assistance Page](https://www.sparkfun.com/technical_assistance){ .md-button .md-button--primary }
    </center>
    
    If you can't find what you need there, you'll need a [Forum Account](https://forum.sparkfun.com/ucp.php?mode=register) to search product forums and post questions.

## Discrepancies in the Documentation

All of this documentation can be modified by you! Please help us make it better.

* The documentation files for these pages are contained in the [`docs` folder](https://github.com/sparkfun/SparkFun_USB-C_Host_Shield/tree/main/docs) of the [SparkFun USB-C Host Shield](https://github.com/sparkfun/SparkFun_USB-C_Host_Shield) repository.

### Spot something wrong?
If a section of the documentation is incorrect, please [open an issue](https://github.com/sparkfun/SparkFun_USB-C_Host_Shield/issues) and let us know.

### Do you have a suggested correction?
1. With a GitHub account, fork this repo
2. Add your correction(s) or improvement(s) to the markdown file(s)
3. File a pull request with your changes, and enjoy making the ~~words~~ ~~worlds~~ world a better place.
    * Once received, the documentation specialist will automatically be notified.
    * We will review your suggested improvement(s) to make sure they are correct and fit within our documentation standards.

## Problems in the Hardware Design

All of our designs are open-source! Please help us make it better.

* Our board design files are contained in the [`Hardware` folder](https://github.com/sparkfun/SparkFun_USB-C_Host_Shield/tree/main/Hardware) of the [SparkFun USB-C Host Shield](https://github.com/sparkfun/SparkFun_USB-C_Host_Shield) repository. 

### Does something not make sense?
If part of the design is confusing, please [open an issue](https://github.com/sparkfun/SparkFun_USB-C_Host_Shield/issues) and let us know.

### Did we forget to include an important function of the board?
* Please keep in mind that we may intentionally exclude certain functions of the board to meet our product design requirements. *(For example, our Qwiic Micro boards are intended to fit on a small board layout and only use I<sup>2</sup>C communication; therefore, we may not have the SPI and interrupt pins available for users.)*
* If part of the board's functionality is missing, please [open an issue](https://github.com/sparkfun/SparkFun_USB-C_Host_Shield/issues) and file a feature request.

### Do you wish to contribute directly to improving the board design?
1. With a GitHub account, Fork this repo
2. Add your design improvement(s)
3. File a pull request with your changes, and enjoy making the ~~words~~ ~~worlds~~ world a better place.
    * Once received, the engineer in charge of the original design will automatically be notified.
    * We will review your suggested improvement(s), if they are within our board design standards and meet our product design requirements, we will flag these changes for our next board revision. *(Please note, that even if your suggestion is accepted, these changes may not be immediate. We may have to cycle through our current product inventory first.)*

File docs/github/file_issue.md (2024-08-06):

# Did we make a mistake?

Spot something wrong? Please let us know. 

<!-- Technical Assistance Box -->
!!! warning "Need Help?"
	If you need technical assistance or more information on a product that is not working as you expected, we recommend heading on over to the [SparkFun Technical Assistance](https://www.sparkfun.com/technical_assistanc) page for some initial troubleshooting. This **Submit Issues** page is not where users should seek assistance.

	<center>
	[SparkFun Technical Assistance Page](https://www.sparkfun.com/technical_assistance){ .md-button .md-button--primary }
	</center>

	If you can't find what you need there, the [SparkFun Forums](https://forum.sparkfun.com/index.php) is a great place to search the product forums and ask questions.

	!!! info "Account Registration Required"
		For your first visit to our forum, you'll need to create a [Forum Account](https://forum.sparkfun.com/ucp.php?mode=register) to post questions.

## Discrepancies in the Documentation

All of our documentation can be modified by you! Please help us make it better.

* The documentation files for these pages are contained in the [`docs` folder](https://github.com/sparkfun/SparkFun_USB-C_Host_Shield/tree/main/docs) of the [SparkFun RA6M5 Thing Plus repository](https://github.com/sparkfun/SparkFun_USB-C_Host_Shield).

### 🔍 Spot something wrong?

If a section of the documentation is incorrect, please [open an issue](https://github.com/sparkfun/SparkFun_USB-C_Host_Shield/issues) and let us know.

### Do you have a suggested correction?

1. With a GitHub account, [fork this repository](https://github.com/sparkfun/SparkFun_USB-C_Host_Shield/fork).
2. Add your correction(s) or improvement(s) to the markdown file(s)
3. File a pull request with your changes, and enjoy making the ~~words~~ ~~worlds~~ world a better place.
	* Once received, the documentation specialist will automatically be notified.
	* We will review your suggested improvement(s) to make sure they are correct and fit within our documentation standards.

## Problems in the Hardware Design

All of our designs are open-source! Please help us make it better.

* Our board design files are contained in the [`Hardware` folder](https://github.com/sparkfun/SparkFun_USB-C_Host_Shield/tree/main/Hardware) of the [SparkFun RA6M5 Thing Plus repository](https://github.com/sparkfun/SparkFun_USB-C_Host_Shield).

### Does something not make sense? 🤔

If part of the design is confusing, please [open an issue](https://github.com/sparkfun/SparkFun_USB-C_Host_Shield/issues) and let us know.

### Did we forget to include an important function of the board? 🤦

If part of the board's functionality is missing, please [open an issue](https://github.com/sparkfun/SparkFun_USB-C_Host_Shield/issues) and file a feature request.

!!! tip "Design Considerations"
	Please keep in mind that we may intentionally exclude certain functions of the board to meet our product design requirements.

	* *For example, our Qwiic Micro boards are intended to fit on a small board layout and only use I^2^C communication; therefore, we may not have the SPI and interrupt pins available for users.*

### Do you wish to contribute directly to improving the board design?

1. With a GitHub account, [fork this repository](https://github.com/sparkfun/SparkFun_USB-C_Host_Shield/fork).
2. Add your design augmentation(s)
3. File a pull request with your changes, and enjoy making the ~~words~~ ~~worlds~~ world a better place.
	1. Once received, the engineer in charge of the original design will automatically be notified.
	2. We will review your suggested improvement(s) to verify that they are within our board design standards and meet our product design requirements.
	3. If approved, we will flag these changes for our next board revision. Congrats! 🍻

		!!! info
			Even if your suggestion is accepted, these changes may not be immediately available for purchase. We may have to cycle through our current product inventory first.

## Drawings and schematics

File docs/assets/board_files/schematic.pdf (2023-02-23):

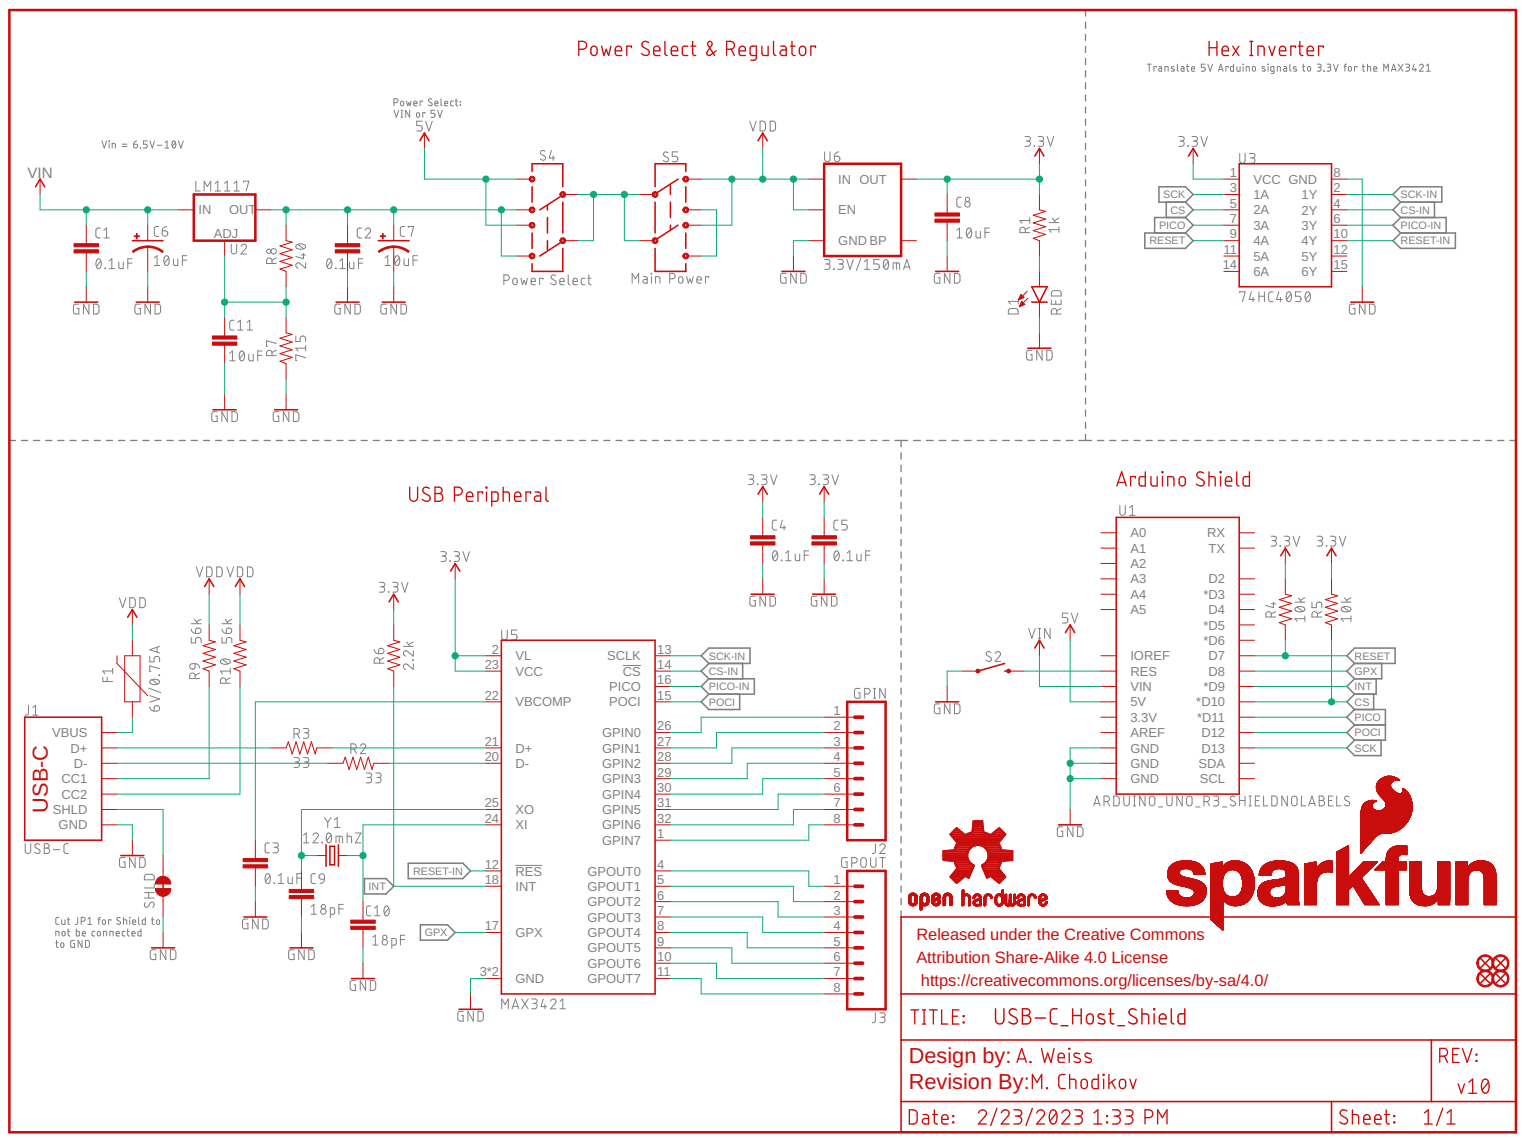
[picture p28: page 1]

Attribution Share-Alike 4.0 License
https://creativecommons.org/licenses/by-sa/4.0/

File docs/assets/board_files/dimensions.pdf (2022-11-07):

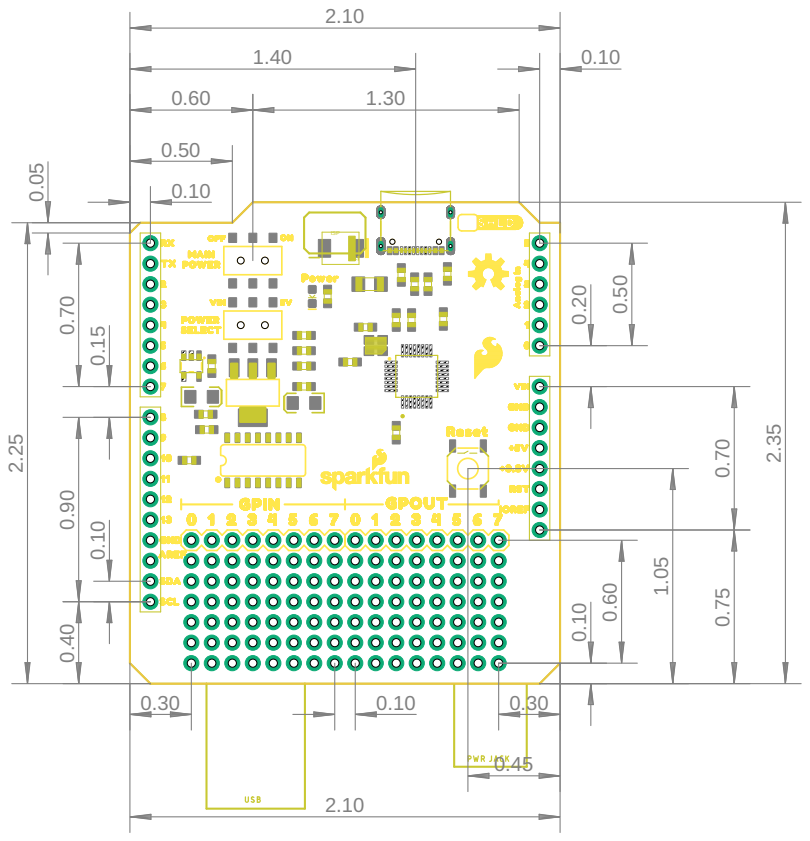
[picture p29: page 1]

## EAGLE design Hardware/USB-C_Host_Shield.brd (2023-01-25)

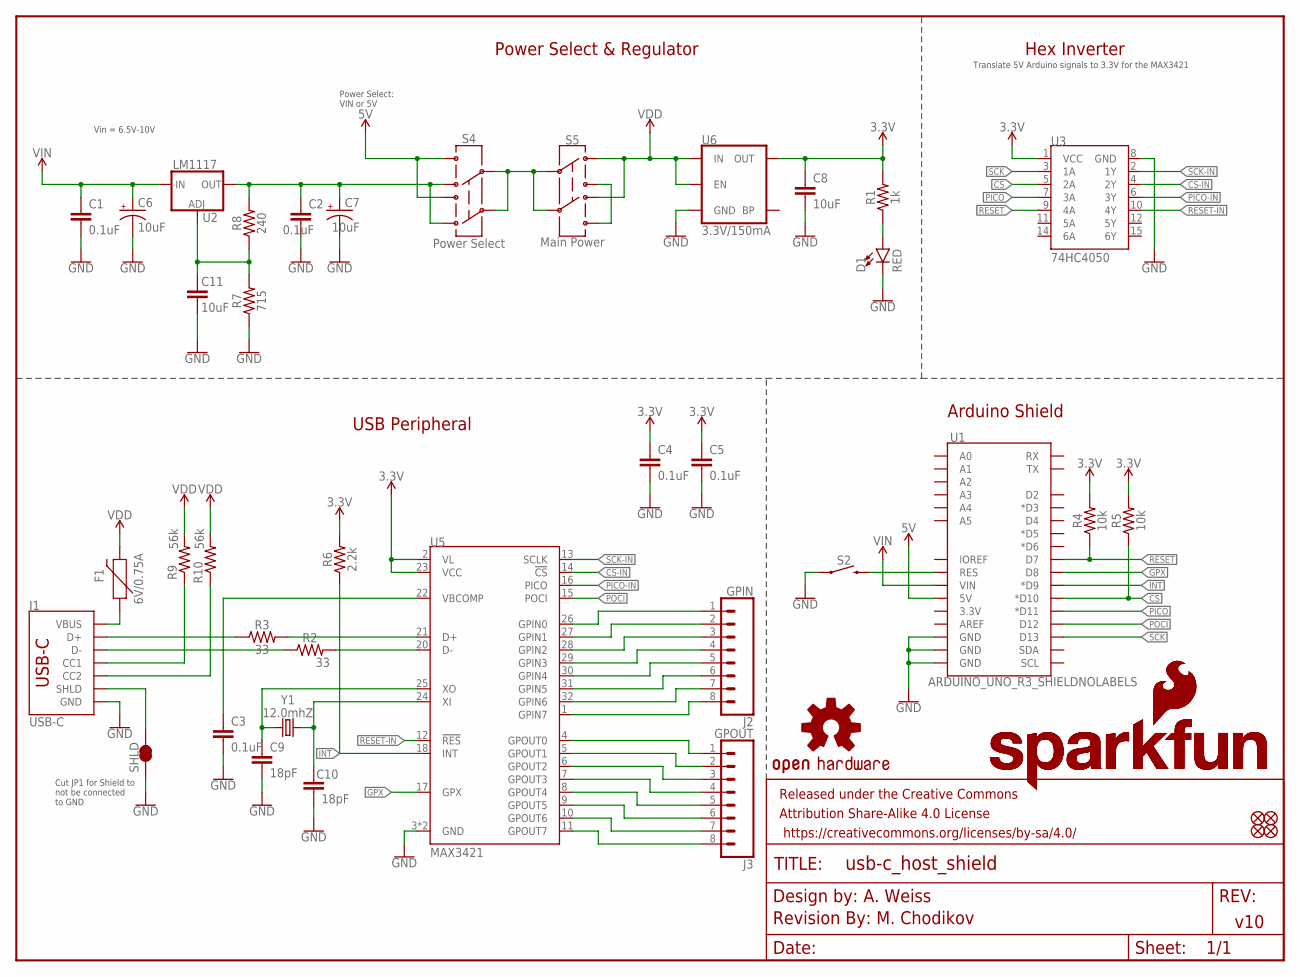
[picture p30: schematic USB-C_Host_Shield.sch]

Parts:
C1, C2, C3, C4, C5: 0.1uF; 0603
C6, C7: 10uF; EIA3216
C8: 10uF; 0603
C9, C10: 18pF; 0603
C11: 10uF; 0805
D1: RED; LED-0603
F1: 6V/0.75A; 1206
FD1, FD2, FD3, FD4: FIDUCIALUFIDUCIAL; FIDUCIAL-MICRO
FRAME1: FRAME-LETTER; CREATIVE_COMMONS
J1: USB-C; USB-C-16P-2LAYER-PADS
J2: GPIN; 1X08
J3: GPOUT; 1X08
LOGO1: OSHW-LOGOM; OSHW-LOGO-M
LOGO2: SFE_LOGO_NAME_FLAME.1_INCH; SFE_LOGO_NAME_FLAME_.1
LOGO3: SFE_LOGO_NAME_FLAME.2_INCH; SFE_LOGO_NAME_FLAME_.2
LOGO7: REVISION
R1: 1k; 0603
R2, R3: 33; 0603
R4, R5: 10k; 0603
R6: 2.2k; 0603
R7: 715; 0603
R8: 240; 0603
R9, R10: 56k; 0603
S2: MOMENTARY-SWITCH-SPST-SMD-5.2MM-TALL; TACTILE_SWITCH_SMD_5.2MM
S4: Power Select; SWITCH_DPDT_SMD_AYZ0202
S5: Main Power; SWITCH_DPDT_SMD_AYZ0202
SHLD: JUMPER-SMT_2_NC_TRACE_SILK; SMT-JUMPER_2_NC_TRACE_SILK
U1: ARDUINO_UNO_R3_SHIELDNOLABELS; UNO_R3_SHIELD_NOLABELS
U2: LM1117; SOT223
U3: 74HC4050; SO16
U5: MAX3421; TQFP32
U6: 3.3V/150mA; SOT23-5
Y1: 12.0mhZ; CRYSTAL-SMD-2X2.5MM

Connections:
3.3V: C4.1, C5.1, C8.1, R1.2, R4.2, R5.2, R6.2, U3.1 (VCC), U5.2 (VL), U5.23 (VCC), U6.5 (OUT)
5V: S4.1, S4.4, U1.5V
CC1: J1.A5 (CC1), R9.1
CC2: J1.B5 (CC2), R10.1
CS: R5.1, U1.D10 (*D10), U3.5 (2A)
CS-IN: U3.4 (2Y), U5.14 (!CS)
D_N: J1.A7 (D-), J1.B7 (D-), R2.1
D_P: J1.A6 (D+), J1.B6 (D+), R3.1
GND: C1.2, C2.2, C3.2, C4.2, C5.2, C6.-, C7.-, C8.2, C9.2, C10.2, C11.2, D1.C, J1.GND, J1.GND2 (GND), R7.1, S2.1, SHLD.1, U1.GND@0 (GND), U1.GND@1 (GND), U1.GND@2 (GND), U3.8 (GND), U5.3 (GND), U5.19 (GND), U6.2 (GND)
GPIN0: J2.1, U5.26 (GPIN0)
GPIN1: J2.2, U5.27 (GPIN1)
GPIN2: J2.3, U5.28 (GPIN2)
GPIN3: J2.4, U5.29 (GPIN3)
GPIN4: J2.5, U5.30 (GPIN4)
GPIN5: J2.6, U5.31 (GPIN5)
GPIN6: J2.7, U5.32 (GPIN6)
GPIN7: J2.8, U5.1 (GPIN7)
GPOUT0: J3.1, U5.4 (GPOUT0)
GPOUT1: J3.2, U5.5 (GPOUT1)
GPOUT2: J3.3, U5.6 (GPOUT2)
GPOUT3: J3.4, U5.7 (GPOUT3)
GPOUT4: J3.5, U5.8 (GPOUT4)
GPOUT5: J3.6, U5.9 (GPOUT5)
GPOUT6: J3.7, U5.10 (GPOUT6)
GPOUT7: J3.8, U5.11 (GPOUT7)
GPX: U1.D8, U5.17 (GPX)
INT: R6.1, U1.D9 (*D9), U5.18 (INT)
MAX_D_N: R2.2, U5.20 (D-)
MAX_D_P: R3.2, U5.21 (D+)
unnamed: S2.3 (2), U1.RES
unnamed: S4.2, S4.5, S5.2, S5.5
unnamed: C11.1, R7.2, R8.1, U2.1 (ADJ)
unnamed: S5.1, S5.4
unnamed: C2.1, C7.+, R8.2, S4.3, S4.6, U2.2 (OUT), U2.4 (OUT)
unnamed: D1.A, R1.1
unnamed: J1.SHLD1 (SHLD), J1.SHLD2 (SHLD), J1.SHLD3 (SHLD), J1.SHLD4 (SHLD), SHLD.2
PICO: U1.D11 (*D11), U3.7 (3A)
PICO-IN: U3.6 (3Y), U5.16 (PICO)
POCI: U1.D12, U5.15 (POCI)
RESET: R4.1, U1.D7, U3.9 (4A)
RESET-IN: U3.10 (4Y), U5.12 (!RES)
SCK: U1.D13, U3.3 (1A)
SCK-IN: U3.2 (1Y), U5.13 (SCLK)
VBCOMP: C3.1, U5.22 (VBCOMP)
VBUS: F1.1, J1.VBUS1 (VBUS), J1.VBUS2 (VBUS)
VDD: F1.2, R9.2, R10.2, S5.3, S5.6, U6.1 (IN), U6.3 (EN)
VIN: C1.1, C6.+, U1.VIN, U2.3 (IN)
XI: C10.1, U5.24 (XI), Y1.P3 (2)
XO: C9.1, U5.25 (XO), Y1.P1 (1)

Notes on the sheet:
M. Chodikov
v10
Power Select & Regulator
Arduino Shield
USB Peripheral
Hex Inverter
Translate 5V Arduino signals to 3.3V for the MAX3421
Vin = 6.5V-10V
Cut JP1 for Shield to not be connected to GND
A. Weiss
Power Select: VIN or 5V

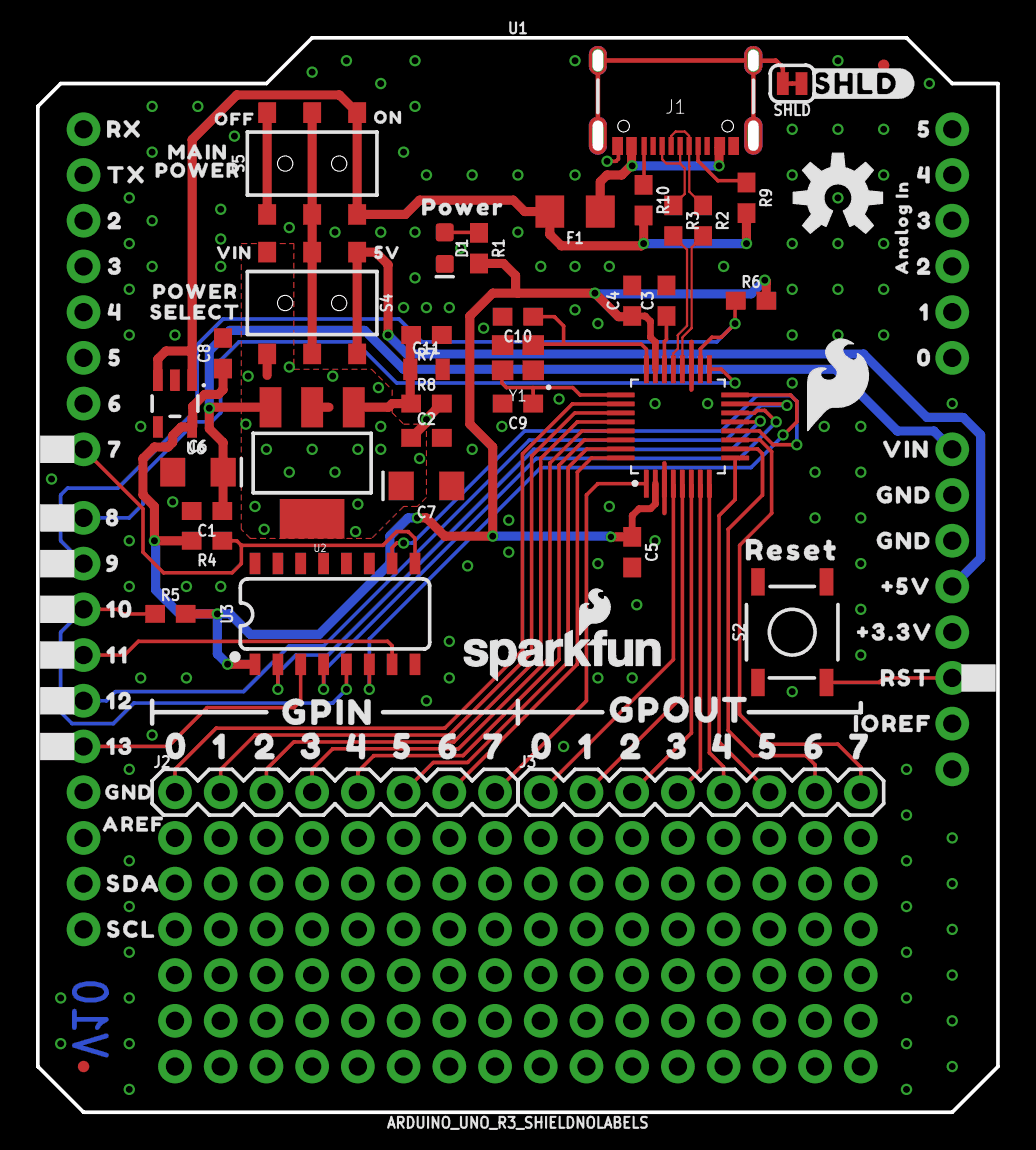
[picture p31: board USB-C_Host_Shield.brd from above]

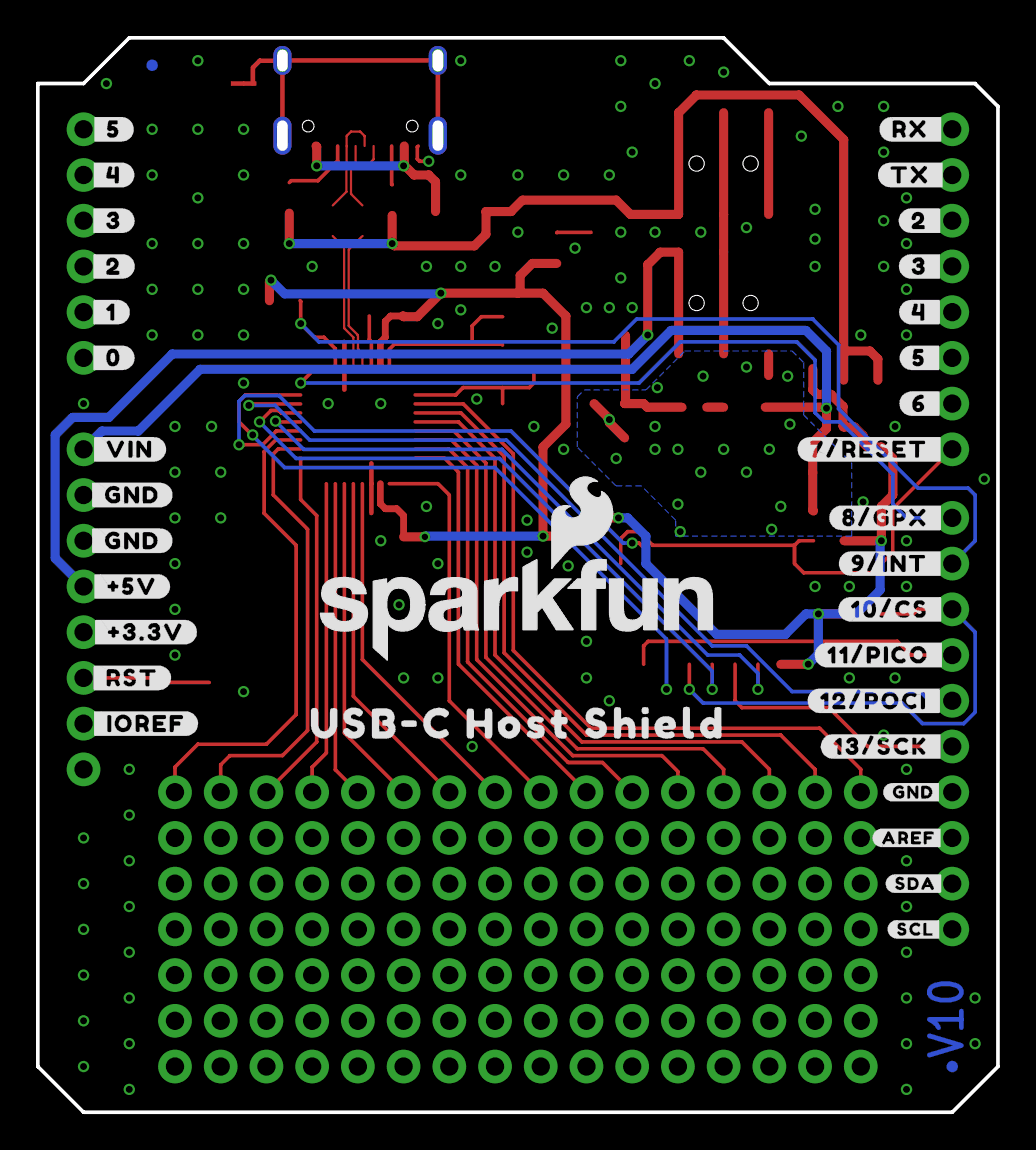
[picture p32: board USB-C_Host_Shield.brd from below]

Board: 2 copper layers, 53.3 x 59.7 mm, 139 parts (35 on the bottom side), 49 nets.

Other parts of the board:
U$1: 5V6
U$2: POWER23
U$3: GPIN42
U$4: SFE_LOGO_FLAME_.2
U$5: ON26
U$6: RESET25
U$7: OFF27
U$8: ANALOG_IN28
U$9: USB#C_HOST_SHIELD32
U$10: POWER11
U$11: SHLD#33
U$12: VIN7
U$13: SELECT12
U$14: POWER38
U$15: MAIN40
U$16: GPOUT44
U$17, U$29: 045
U$18, U$30: 146
U$19, U$31: 2147
U$20, U$32: 32148
U$21, U$22: 4332150
U$23, U$25: 54332151
U$24, U$26: 654332152
U$27, U$28: 7654332153
U$33: #5V4
U$34: VIN6
U$35, U$51: GND131211109817654321131211211109876543260
U$36: SDA131211109817654321131211211109876543261
U$37: GND131211211109876543229
U$38, U$55: 21131211211109876543246
U$39, U$56: 321131211211109876543247
U$40, U$57: 4321131211211109876543248
U$41, U$58: 54321131211211109876543249
U$42: 654321131211211109876543250
U$43: 7654321131211211109876543251
U$44: 17654321131211211109876543252
U$45: 017654321131211211109876543253
U$46: 9817654321131211211109876543255
U$47: 109817654321131211211109876543256
U$48: 11109817654321131211211109876543257
U$49: 1211109817654321131211211109876543258
U$50: 131211109817654321131211211109876543259
U$52: AREF131211211109876543230
U$53: SCL131211109817654321131211211109876543262
U$54: IOREF131211109817654321131211211109876543264
U$59: 817654321131211211109876543254
U$60: RST131211109817654321131211211109876543265
U$61: #_4#6
U$62: #3#3V4
U$63: #_5#6
U$64: RX13
U$65: TX1131211211109876543245
U$66: #_3#6
U$67: #_2#6
U$68: #_1#6
U$69: #_0#6
U$70: #_VIN#6
U$71, U$72: #_GND#7
U$73: #_#5V#8
U$74: #_#3#3V#8
U$75: #_RST#8
U$76: #_IOREF#9
U$77: #RX_#10
U$78: #TX_#11
U$79: #2_#12
U$80: #3_#12
U$81: #4_#12
U$82: #5_#12
U$83: #6_#12
U$84: #7#RESET_#12
U$85: #8#GPX_#12
U$86: #9#INT_#12
U$87: #10#CS_#12
U$88: #11#PICO_#12
U$89: #12#POCI_#12
U$90: #13#SCK_#13
U$92: #GND#21
U$93: #SDA#18
U$94: #SCL#19
U$95: #AREF#20

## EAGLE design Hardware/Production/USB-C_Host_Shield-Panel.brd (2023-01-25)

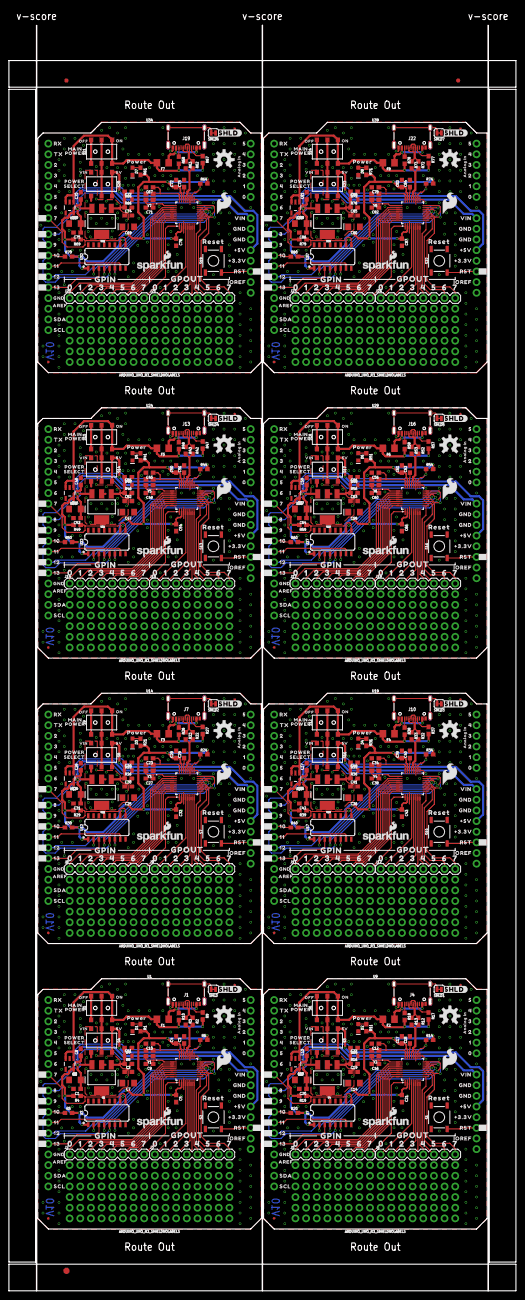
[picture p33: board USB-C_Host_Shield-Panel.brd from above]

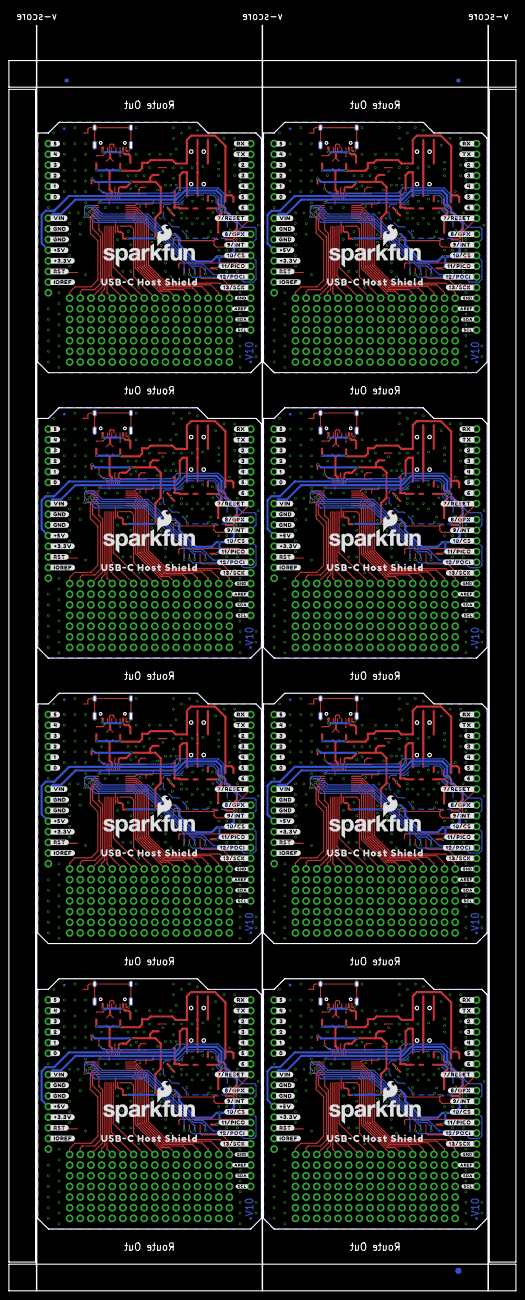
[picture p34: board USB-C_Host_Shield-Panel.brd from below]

Board: 2 copper layers, 120.9 x 301.8 mm, 1118 parts (283 on the bottom side), 392 nets.

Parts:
C1, C2, C3, C4, C5, C17, C18, C19, C20, C21, C28, C29, C30, C31, C32, C39, C40, C41, C42, C43, C50, C51, C52, C53, C54, C61, C62, C63, C64, C65, C72, C73, C74, C75, C76, C83, C84, C85, C86, C87: 0.1uF; 0603
C6, C7, C13, C14, C24, C25, C35, C36, C46, C47, C57, C58, C68, C69, C79, C80: 10uF; EIA3216
C8, C15, C26, C37, C48, C59, C70, C81: 10uF; 0603
C9, C10, C12, C16, C23, C27, C34, C38, C45, C49, C56, C60, C67, C71, C78, C82: 18pF; 0603
C11, C22, C33, C44, C55, C66, C77, C88: 10uF; 0805
D1, D2, D3, D4, D5, D6, D7, D8: RED; LED-0603
E$1, E$2, E$3, E$4: FIDUCIAL-1X2
E$5, E$6: FIDUCIAL-1.5X3
F1, F2, F3, F4, F5, F6, F7, F8: 6V/0.75A; 1206
FD1, FD2, FD3, FD4, FD5, FD6, FD7, FD8, FD9, FD10, FD11, FD12, FD13, FD14, FD15, FD16, FD17, FD18, FD19, FD20, FD21, FD22, FD23, FD24, FD25, FD26, FD27, FD28, FD29, FD30, FD31, FD32: FIDUCIALUFIDUCIAL; FIDUCIAL-MICRO
FRAME1, FRAME2, FRAME3, FRAME4, FRAME5, FRAME6, FRAME7, FRAME8: FRAME-LETTER; CREATIVE_COMMONS
J1, J4, J7, J10, J13, J16, J19, J22: USB-C; USB-C-16P-2LAYER-PADS
J2, J5, J8, J11, J14, J17, J20, J23: GPIN; 1X08
J3, J6, J9, J12, J15, J18, J21, J24: GPOUT; 1X08
LOGO1, LOGO4, LOGO9, LOGO13, LOGO17, LOGO21, LOGO25, LOGO29: OSHW-LOGOM; OSHW-LOGO-M
LOGO2, LOGO5, LOGO10, LOGO14, LOGO18, LOGO22, LOGO26, LOGO30: SFE_LOGO_NAME_FLAME.1_INCH; SFE_LOGO_NAME_FLAME_.1
LOGO3, LOGO6, LOGO11, LOGO15, LOGO19, LOGO23, LOGO27, LOGO31: SFE_LOGO_NAME_FLAME.2_INCH; SFE_LOGO_NAME_FLAME_.2
LOGO7, LOGO8, LOGO12, LOGO16, LOGO20, LOGO24, LOGO28, LOGO32: REVISION
R1, R11, R21, R31, R41, R51, R61, R71: 1k; 0603
R2, R3, R12, R13, R22, R23, R32, R33, R42, R43, R52, R53, R62, R63, R72, R73: 33; 0603
R4, R5, R19, R20, R29, R30, R39, R40, R49, R50, R59, R60, R69, R70, R79, R80: 10k; 0603
R6, R14, R24, R34, R44, R54, R64, R74: 2.2k; 0603
R7, R15, R25, R35, R45, R55, R65, R75: 715; 0603
R8, R16, R26, R36, R46, R56, R66, R76: 240; 0603
R9, R10, R17, R18, R27, R28, R37, R38, R47, R48, R57, R58, R67, R68, R77, R78: 56k; 0603
S1, S2, S7, S10, S13, S16, S19, S22: MOMENTARY-SWITCH-SPST-SMD-5.2MM-TALL; TACTILE_SWITCH_SMD_5.2MM
S3, S4, S8, S11, S14, S17, S20, S23: Power Select; SWITCH_DPDT_SMD_AYZ0202
S5, S6, S9, S12, S15, S18, S21, S24: Main Power; SWITCH_DPDT_SMD_AYZ0202
SHLD, SHLD1, SHLD2, SHLD3, SHLD4, SHLD5, SHLD6, SHLD7: JUMPER-SMT_2_NC_TRACE_SILK; SMT-JUMPER_2_NC_TRACE_SILK
U1, U9, U14, U19, U24, U29, U34, U39: ARDUINO_UNO_R3_SHIELDNOLABELS; UNO_R3_SHIELD_NOLABELS
U2, U4, U11, U16, U21, U26, U31, U36: LM1117; SOT223
U3, U7, U12, U17, U22, U27, U32, U37: 74HC4050; SO16
U5, U10, U15, U20, U25, U30, U35, U40: MAX3421; TQFP32
U6, U8, U13, U18, U23, U28, U33, U38: 3.3V/150mA; SOT23-5
U$1, U$123, U$217, U$311, U$405, U$499, U$593, U$687: 5V6
U$2, U$91, U$189, U$283, U$377, U$471, U$565, U$659: POWER23
U$3, U$105, U$199, U$293, U$387, U$481, U$575, U$669: GPIN42
U$4, U$96, U$190, U$284, U$378, U$472, U$566, U$660: SFE_LOGO_FLAME_.2
U$5, U$98, U$192, U$286, U$380, U$474, U$568, U$662: ON26
U$6, U$97, U$191, U$285, U$379, U$473, U$567, U$661: RESET25
U$7, U$99, U$193, U$287, U$381, U$475, U$569, U$663: OFF27
U$8, U$100, U$194, U$288, U$382, U$476, U$570, U$664: ANALOG_IN28
U$9, U$101, U$195, U$289, U$383, U$477, U$571, U$665: USB#C_HOST_SHIELD32
U$10, U$125, U$219, U$313, U$407, U$501, U$595, U$689: POWER11
U$11, U$102, U$196, U$290, U$384, U$478, U$572, U$666: SHLD#33
U$12, U$124, U$218, U$312, U$406, U$500, U$594, U$688: VIN7
U$13, U$126, U$220, U$314, U$408, U$502, U$596, U$690: SELECT12
U$14, U$104, U$198, U$292, U$386, U$480, U$574, U$668: POWER38
U$15, U$103, U$197, U$291, U$385, U$479, U$573, U$667: MAIN40
U$16, U$106, U$200, U$294, U$388, U$482, U$576, U$670: GPOUT44
U$17, U$29, U$107, U$119, U$201, U$213, U$295, U$307, U$389, U$401, U$483, U$495, U$577, U$589, U$671, U$683: 045
U$18, U$30, U$108, U$120, U$202, U$214, U$296, U$308, U$390, U$402, U$484, U$496, U$578, U$590, U$672, U$684: 146
U$19, U$31, U$109, U$121, U$203, U$215, U$297, U$309, U$391, U$403, U$485, U$497, U$579, U$591, U$673, U$685: 2147
U$20, U$32, U$110, U$122, U$204, U$216, U$298, U$310, U$392, U$404, U$486, U$498, U$580, U$592, U$674, U$686: 32148
U$21, U$22, U$111, U$112, U$205, U$206, U$299, U$300, U$393, U$394, U$487, U$488, U$581, U$582, U$675, U$676: 4332150
U$23, U$25, U$113, U$114, U$207, U$208, U$301, U$302, U$395, U$396, U$489, U$490, U$583, U$584, U$677, U$678: 54332151
U$24, U$26, U$115, U$116, U$209, U$210, U$303, U$304, U$397, U$398, U$491, U$492, U$585, U$586, U$679, U$680: 654332152
U$27, U$28, U$117, U$118, U$211, U$212, U$305, U$306, U$399, U$400, U$493, U$494, U$587, U$588, U$681, U$682: 7654332153
U$33, U$156, U$250, U$344, U$438, U$532, U$626, U$720: #5V4
U$34, U$157, U$251, U$345, U$439, U$533, U$627, U$721: VIN6
U$35, U$51, U$149, U$150, U$243, U$244, U$337, U$338, U$431, U$432, U$525, U$526, U$619, U$620, U$713, U$714: GND131211109817654321131211211109876543260
U$36, U$151, U$245, U$339, U$433, U$527, U$621, U$715: SDA131211109817654321131211211109876543261
U$37, U$127, U$221, U$315, U$409, U$503, U$597, U$691: GND131211211109876543229
U$38, U$55, U$131, U$139, U$225, U$233, U$319, U$327, U$413, U$421, U$507, U$515, U$601, U$609, U$695, U$703: 21131211211109876543246
U$39, U$56, U$132, U$140, U$226, U$234, U$320, U$328, U$414, U$422, U$508, U$516, U$602, U$610, U$696, U$704: 321131211211109876543247
U$40, U$57, U$133, U$141, U$227, U$235, U$321, U$329, U$415, U$423, U$509, U$517, U$603, U$611, U$697, U$705: 4321131211211109876543248
U$41, U$58, U$134, U$142, U$228, U$236, U$322, U$330, U$416, U$424, U$510, U$518, U$604, U$612, U$698, U$706: 54321131211211109876543249
U$42, U$135, U$229, U$323, U$417, U$511, U$605, U$699: 654321131211211109876543250
U$43, U$136, U$230, U$324, U$418, U$512, U$606, U$700: 7654321131211211109876543251
U$44, U$137, U$231, U$325, U$419, U$513, U$607, U$701: 17654321131211211109876543252
U$45, U$138, U$232, U$326, U$420, U$514, U$608, U$702: 017654321131211211109876543253
U$46, U$144, U$238, U$332, U$426, U$520, U$614, U$708: 9817654321131211211109876543255
U$47, U$145, U$239, U$333, U$427, U$521, U$615, U$709: 109817654321131211211109876543256
U$48, U$146, U$240, U$334, U$428, U$522, U$616, U$710: 11109817654321131211211109876543257
U$49, U$147, U$241, U$335, U$429, U$523, U$617, U$711: 1211109817654321131211211109876543258
U$50, U$148, U$242, U$336, U$430, U$524, U$618, U$712: 131211109817654321131211211109876543259
U$52, U$128, U$222, U$316, U$410, U$504, U$598, U$692: AREF131211211109876543230
U$53, U$152, U$246, U$340, U$434, U$528, U$622, U$716: SCL131211109817654321131211211109876543262
U$54, U$153, U$247, U$341, U$435, U$529, U$623, U$717: IOREF131211109817654321131211211109876543264
U$59, U$143, U$237, U$331, U$425, U$519, U$613, U$707: 817654321131211211109876543254
U$60, U$154, U$248, U$342, U$436, U$530, U$624, U$718: RST131211109817654321131211211109876543265
U$61, U$159, U$253, U$347, U$441, U$535, U$629, U$723: #_4#6
U$62, U$155, U$249, U$343, U$437, U$531, U$625, U$719: #3#3V4
U$63, U$158, U$252, U$346, U$440, U$534, U$628, U$722: #_5#6
U$64, U$129, U$223, U$317, U$411, U$505, U$599, U$693: RX13
U$65, U$130, U$224, U$318, U$412, U$506, U$600, U$694: TX1131211211109876543245
U$66, U$160, U$254, U$348, U$442, U$536, U$630, U$724: #_3#6
U$67, U$161, U$255, U$349, U$443, U$537, U$631, U$725: #_2#6
U$68, U$162, U$256, U$350, U$444, U$538, U$632, U$726: #_1#6
U$69, U$163, U$257, U$351, U$445, U$539, U$633, U$727: #_0#6
U$70, U$164, U$258, U$352, U$446, U$540, U$634, U$728: #_VIN#6
U$71, U$72, U$165, U$166, U$259, U$260, U$353, U$354, U$447, U$448, U$541, U$542, U$635, U$636, U$729, U$730: #_GND#7
U$73, U$167, U$261, U$355, U$449, U$543, U$637, U$731: #_#5V#8
U$74, U$168, U$262, U$356, U$450, U$544, U$638, U$732: #_#3#3V#8
U$75, U$169, U$263, U$357, U$451, U$545, U$639, U$733: #_RST#8
U$76, U$170, U$264, U$358, U$452, U$546, U$640, U$734: #_IOREF#9
U$77, U$171, U$265, U$359, U$453, U$547, U$641, U$735: #RX_#10
U$78, U$172, U$266, U$360, U$454, U$548, U$642, U$736: #TX_#11
U$79, U$173, U$267, U$361, U$455, U$549, U$643, U$737: #2_#12
U$80, U$174, U$268, U$362, U$456, U$550, U$644, U$738: #3_#12
U$81, U$175, U$269, U$363, U$457, U$551, U$645, U$739: #4_#12
U$82, U$176, U$270, U$364, U$458, U$552, U$646, U$740: #5_#12
U$83, U$177, U$271, U$365, U$459, U$553, U$647, U$741: #6_#12
U$84, U$178, U$272, U$366, U$460, U$554, U$648, U$742: #7#RESET_#12
U$85, U$179, U$273, U$367, U$461, U$555, U$649, U$743: #8#GPX_#12
U$86, U$180, U$274, U$368, U$462, U$556, U$650, U$744: #9#INT_#12
U$87, U$181, U$275, U$369, U$463, U$557, U$651, U$745: #10#CS_#12
U$88, U$182, U$276, U$370, U$464, U$558, U$652, U$746: #11#PICO_#12
U$89, U$183, U$277, U$371, U$465, U$559, U$653, U$747: #12#POCI_#12
U$90, U$184, U$278, U$372, U$466, U$560, U$654, U$748: #13#SCK_#13
U$92, U$188, U$282, U$376, U$470, U$564, U$658, U$752: #GND#21
U$93, U$185, U$279, U$373, U$467, U$561, U$655, U$749: #SDA#18
U$94, U$186, U$280, U$374, U$468, U$562, U$656, U$750: #SCL#19
U$95, U$187, U$281, U$375, U$469, U$563, U$657, U$751: #AREF#20
Y1, Y2, Y3, Y4, Y5, Y6, Y7, Y8: 12.0mhZ; CRYSTAL-SMD-2X2.5MM

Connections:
3.3V: C4.1, C5.1, C8.1, R1.2, R4.2, R5.2, R6.2, U3.1, U5.2, U5.23, U6.5
3.3V1: C15.1, C17.1, C21.1, R11.2, R14.2, R19.2, R20.2, U7.1, U8.5, U10.2, U10.23
3.3V2: C26.1, C28.1, C32.1, R21.2, R24.2, R29.2, R30.2, U12.1, U13.5, U15.2, U15.23
3.3V3: C37.1, C39.1, C43.1, R31.2, R34.2, R39.2, R40.2, U17.1, U18.5, U20.2, U20.23
3.3V4: C48.1, C50.1, C54.1, R41.2, R44.2, R49.2, R50.2, U22.1, U23.5, U25.2, U25.23
3.3V5: C59.1, C61.1, C65.1, R51.2, R54.2, R59.2, R60.2, U27.1, U28.5, U30.2, U30.23
3.3V6: C70.1, C72.1, C76.1, R61.2, R64.2, R69.2, R70.2, U32.1, U33.5, U35.2, U35.23
3.3V7: C81.1, C83.1, C87.1, R71.2, R74.2, R79.2, R80.2, U37.1, U38.5, U40.2, U40.23
5V: S4.1, S4.4, U1.5V
5V1: S3.1, S3.4, U9.5V
5V2: S8.1, S8.4, U14.5V
5V3: S11.1, S11.4, U19.5V
5V4: S14.1, S14.4, U24.5V
5V5: S17.1, S17.4, U29.5V
5V6: S20.1, S20.4, U34.5V
5V7: S23.1, S23.4, U39.5V
CC1: J1.A5, R9.1
CC2: J1.B5, R10.1
CC3: J4.A5, R17.1
CC4: J4.B5, R18.1
CC5: J7.A5, R27.1
CC6: J7.B5, R28.1
CC7: J10.A5, R37.1
CC8: J10.B5, R38.1
CC9: J13.A5, R47.1
CC10: J13.B5, R48.1
CC11: J16.A5, R57.1
CC12: J16.B5, R58.1
CC13: J19.A5, R67.1
CC14: J19.B5, R68.1
CC15: J22.A5, R77.1
CC16: J22.B5, R78.1
CS: R5.1, U1.D10, U3.5
CS1: R20.1, U7.5, U9.D10
CS2: R30.1, U12.5, U14.D10
CS3: R40.1, U17.5, U19.D10
CS4: R50.1, U22.5, U24.D10
CS5: R60.1, U27.5, U29.D10
CS6: R70.1, U32.5, U34.D10
CS7: R80.1, U37.5, U39.D10
CS-IN: U3.4, U5.14
CS-IN1: U7.4, U10.14
CS-IN2: U12.4, U15.14
CS-IN3: U17.4, U20.14
CS-IN4: U22.4, U25.14
CS-IN5: U27.4, U30.14
CS-IN6: U32.4, U35.14
CS-IN7: U37.4, U40.14
D_N: J1.A7, J1.B7, R2.1
D_N1: J4.A7, J4.B7, R12.1
D_N2: J7.A7, J7.B7, R22.1
D_N3: J10.A7, J10.B7, R32.1
D_N4: J13.A7, J13.B7, R42.1
D_N5: J16.A7, J16.B7, R52.1
D_N6: J19.A7, J19.B7, R62.1
D_N7: J22.A7, J22.B7, R72.1
D_P: J1.A6, J1.B6, R3.1
D_P1: J4.A6, J4.B6, R13.1
D_P2: J7.A6, J7.B6, R23.1
D_P3: J10.A6, J10.B6, R33.1
D_P4: J13.A6, J13.B6, R43.1
D_P5: J16.A6, J16.B6, R53.1
D_P6: J19.A6, J19.B6, R63.1
D_P7: J22.A6, J22.B6, R73.1
GND: C1.2, C2.2, C3.2, C4.2, C5.2, C6.-, C7.-, C8.2, C9.2, C10.2, C11.2, D1.C, J1.GND, J1.GND2, R7.1, S2.1, SHLD.1, U1.GND@0, U1.GND@1, U1.GND@2, U3.8, U5.3, U5.19, U6.2
GND1: C12.2, C13.-, C14.-, C15.2, C16.2, C17.2, C18.2, C19.2, C20.2, C21.2, C22.2, D2.C, J4.GND, J4.GND2, R15.1, S1.1, SHLD1.1, U7.8, U8.2, U9.GND@0, U9.GND@1, U9.GND@2, U10.3, U10.19
GND2: C23.2, C24.-, C25.-, C26.2, C27.2, C28.2, C29.2, C30.2, C31.2, C32.2, C33.2, D3.C, J7.GND, J7.GND2, R25.1, S7.1, SHLD2.1, U12.8, U13.2, U14.GND@0, U14.GND@1, U14.GND@2, U15.3, U15.19
GND3: C34.2, C35.-, C36.-, C37.2, C38.2, C39.2, C40.2, C41.2, C42.2, C43.2, C44.2, D4.C, J10.GND, J10.GND2, R35.1, S10.1, SHLD3.1, U17.8, U18.2, U19.GND@0, U19.GND@1, U19.GND@2, U20.3, U20.19
GND4: C45.2, C46.-, C47.-, C48.2, C49.2, C50.2, C51.2, C52.2, C53.2, C54.2, C55.2, D5.C, J13.GND, J13.GND2, R45.1, S13.1, SHLD4.1, U22.8, U23.2, U24.GND@0, U24.GND@1, U24.GND@2, U25.3, U25.19
GND5: C56.2, C57.-, C58.-, C59.2, C60.2, C61.2, C62.2, C63.2, C64.2, C65.2, C66.2, D6.C, J16.GND, J16.GND2, R55.1, S16.1, SHLD5.1, U27.8, U28.2, U29.GND@0, U29.GND@1, U29.GND@2, U30.3, U30.19
GND6: C67.2, C68.-, C69.-, C70.2, C71.2, C72.2, C73.2, C74.2, C75.2, C76.2, C77.2, D7.C, J19.GND, J19.GND2, R65.1, S19.1, SHLD6.1, U32.8, U33.2, U34.GND@0, U34.GND@1, U34.GND@2, U35.3, U35.19
GND7: C78.2, C79.-, C80.-, C81.2, C82.2, C83.2, C84.2, C85.2, C86.2, C87.2, C88.2, D8.C, J22.GND, J22.GND2, R75.1, S22.1, SHLD7.1, U37.8, U38.2, U39.GND@0, U39.GND@1, U39.GND@2, U40.3, U40.19
GPIN0: J2.1, U5.26
GPIN1: J2.2, U5.27
GPIN2: J2.3, U5.28
GPIN3: J2.4, U5.29
GPIN4: J2.5, U5.30
GPIN5: J2.6, U5.31
GPIN6: J2.7, U5.32
GPIN7: J2.8, U5.1
GPIN8: J5.8, U10.1
GPIN9: J5.7, U10.32
GPIN10: J5.6, U10.31
GPIN11: J5.5, U10.30
GPIN12: J5.4, U10.29
GPIN13: J5.3, U10.28
GPIN14: J5.2, U10.27
GPIN15: J5.1, U10.26
GPIN16: J8.8, U15.1
GPIN17: J8.7, U15.32
GPIN18: J8.6, U15.31
GPIN19: J8.5, U15.30
GPIN20: J8.4, U15.29
GPIN21: J8.3, U15.28
GPIN22: J8.2, U15.27
GPIN23: J8.1, U15.26
GPIN24: J11.8, U20.1
GPIN25: J11.7, U20.32
GPIN26: J11.6, U20.31
GPIN27: J11.5, U20.30
GPIN28: J11.4, U20.29
GPIN29: J11.3, U20.28
GPIN30: J11.2, U20.27
GPIN31: J11.1, U20.26
GPIN32: J14.8, U25.1
GPIN33: J14.7, U25.32
GPIN34: J14.6, U25.31
GPIN35: J14.5, U25.30
GPIN36: J14.4, U25.29
GPIN37: J14.3, U25.28
GPIN38: J14.2, U25.27
GPIN39: J14.1, U25.26
GPIN40: J17.8, U30.1
GPIN41: J17.7, U30.32
GPIN42: J17.6, U30.31
GPIN43: J17.5, U30.30
GPIN44: J17.4, U30.29
GPIN45: J17.3, U30.28
GPIN46: J17.2, U30.27
GPIN47: J17.1, U30.26
GPIN48: J20.8, U35.1
GPIN49: J20.7, U35.32
GPIN50: J20.6, U35.31
GPIN51: J20.5, U35.30
GPIN52: J20.4, U35.29
GPIN53: J20.3, U35.28
GPIN54: J20.2, U35.27
GPIN55: J20.1, U35.26
GPIN56: J23.8, U40.1
GPIN57: J23.7, U40.32
GPIN58: J23.6, U40.31
GPIN59: J23.5, U40.30
GPIN60: J23.4, U40.29
GPIN61: J23.3, U40.28
GPIN62: J23.2, U40.27
GPIN63: J23.1, U40.26
GPOUT0: J3.1, U5.4
GPOUT1: J3.2, U5.5
GPOUT2: J3.3, U5.6
GPOUT3: J3.4, U5.7
GPOUT4: J3.5, U5.8
GPOUT5: J3.6, U5.9
GPOUT6: J3.7, U5.10
GPOUT7: J3.8, U5.11
GPOUT8: J6.1, U10.4
GPOUT9: J6.2, U10.5
GPOUT10: J6.3, U10.6
GPOUT11: J6.4, U10.7
GPOUT12: J6.5, U10.8
GPOUT13: J6.6, U10.9
GPOUT14: J6.7, U10.10
GPOUT15: J6.8, U10.11
GPOUT16: J9.1, U15.4
GPOUT17: J9.2, U15.5
GPOUT18: J9.3, U15.6
GPOUT19: J9.4, U15.7
GPOUT20: J9.5, U15.8
GPOUT21: J9.6, U15.9
GPOUT22: J9.7, U15.10
GPOUT23: J9.8, U15.11
GPOUT24: J12.1, U20.4
GPOUT25: J12.2, U20.5
GPOUT26: J12.3, U20.6
GPOUT27: J12.4, U20.7
GPOUT28: J12.5, U20.8
GPOUT29: J12.6, U20.9
GPOUT30: J12.7, U20.10
GPOUT31: J12.8, U20.11
GPOUT32: J15.1, U25.4
GPOUT33: J15.2, U25.5
GPOUT34: J15.3, U25.6
GPOUT35: J15.4, U25.7
GPOUT36: J15.5, U25.8
GPOUT37: J15.6, U25.9
GPOUT38: J15.7, U25.10
GPOUT39: J15.8, U25.11
GPOUT40: J18.1, U30.4
GPOUT41: J18.2, U30.5
GPOUT42: J18.3, U30.6
GPOUT43: J18.4, U30.7
GPOUT44: J18.5, U30.8
GPOUT45: J18.6, U30.9
GPOUT46: J18.7, U30.10
GPOUT47: J18.8, U30.11
GPOUT48: J21.1, U35.4
GPOUT49: J21.2, U35.5
GPOUT50: J21.3, U35.6
GPOUT51: J21.4, U35.7
GPOUT52: J21.5, U35.8
GPOUT53: J21.6, U35.9
GPOUT54: J21.7, U35.10
GPOUT55: J21.8, U35.11
GPOUT56: J24.1, U40.4
GPOUT57: J24.2, U40.5
GPOUT58: J24.3, U40.6
GPOUT59: J24.4, U40.7
GPOUT60: J24.5, U40.8
GPOUT61: J24.6, U40.9
GPOUT62: J24.7, U40.10
GPOUT63: J24.8, U40.11
GPX: U1.D8, U5.17
GPX1: U9.D8, U10.17
GPX2: U14.D8, U15.17
GPX3: U19.D8, U20.17
GPX4: U24.D8, U25.17
GPX5: U29.D8, U30.17
GPX6: U34.D8, U35.17
GPX7: U39.D8, U40.17
INT: R6.1, U1.D9, U5.18
INT1: R14.1, U9.D9, U10.18
INT2: R24.1, U14.D9, U15.18
INT3: R34.1, U19.D9, U20.18
INT4: R44.1, U24.D9, U25.18
INT5: R54.1, U29.D9, U30.18
INT6: R64.1, U34.D9, U35.18
INT7: R74.1, U39.D9, U40.18
MAX_D_N: R2.2, U5.20
MAX_D_N1: R12.2, U10.20
MAX_D_N2: R22.2, U15.20
MAX_D_N3: R32.2, U20.20
MAX_D_N4: R42.2, U25.20
MAX_D_N5: R52.2, U30.20
MAX_D_N6: R62.2, U35.20
MAX_D_N7: R72.2, U40.20
MAX_D_P: R3.2, U5.21
MAX_D_P1: R13.2, U10.21
MAX_D_P2: R23.2, U15.21
MAX_D_P3: R33.2, U20.21
MAX_D_P4: R43.2, U25.21
MAX_D_P5: R53.2, U30.21
MAX_D_P6: R63.2, U35.21
MAX_D_P7: R73.2, U40.21
unnamed: S2.3, U1.RES
unnamed: S4.2, S4.5, S5.2, S5.5
unnamed: C11.1, R7.2, R8.1, U2.1
unnamed: S5.1, S5.4
unnamed: C2.1, C7.+, R8.2, S4.3, S4.6, U2.2, U2.4
unnamed: D1.A, R1.1
unnamed: J1.SHLD1, J1.SHLD2, J1.SHLD3, J1.SHLD4, SHLD.2
unnamed: D2.A, R11.1
unnamed: C22.1, R15.2, R16.1, U4.1
unnamed: S1.3, U9.RES
unnamed: C14.+, C19.1, R16.2, S3.3, S3.6, U4.2, U4.4
unnamed: J4.SHLD1, J4.SHLD2, J4.SHLD3, J4.SHLD4, SHLD1.2
unnamed: S3.2, S3.5, S6.2, S6.5
unnamed: S6.1, S6.4
unnamed: D3.A, R21.1
unnamed: C33.1, R25.2, R26.1, U11.1
unnamed: S7.3, U14.RES
unnamed: C25.+, C30.1, R26.2, S8.3, S8.6, U11.2, U11.4
unnamed: J7.SHLD1, J7.SHLD2, J7.SHLD3, J7.SHLD4, SHLD2.2
unnamed: S8.2, S8.5, S9.2, S9.5
unnamed: S9.1, S9.4
unnamed: D4.A, R31.1
unnamed: C44.1, R35.2, R36.1, U16.1
unnamed: S10.3, U19.RES
unnamed: C36.+, C41.1, R36.2, S11.3, S11.6, U16.2, U16.4
unnamed: J10.SHLD1, J10.SHLD2, J10.SHLD3, J10.SHLD4, SHLD3.2
unnamed: S11.2, S11.5, S12.2, S12.5
unnamed: S12.1, S12.4
unnamed: D5.A, R41.1
unnamed: C55.1, R45.2, R46.1, U21.1
unnamed: S13.3, U24.RES
unnamed: C47.+, C52.1, R46.2, S14.3, S14.6, U21.2, U21.4
unnamed: J13.SHLD1, J13.SHLD2, J13.SHLD3, J13.SHLD4, SHLD4.2
unnamed: S14.2, S14.5, S15.2, S15.5
unnamed: S15.1, S15.4
unnamed: D6.A, R51.1
unnamed: C66.1, R55.2, R56.1, U26.1
unnamed: S16.3, U29.RES
unnamed: C58.+, C63.1, R56.2, S17.3, S17.6, U26.2, U26.4
unnamed: J16.SHLD1, J16.SHLD2, J16.SHLD3, J16.SHLD4, SHLD5.2
unnamed: S17.2, S17.5, S18.2, S18.5
unnamed: S18.1, S18.4
unnamed: D7.A, R61.1
unnamed: C77.1, R65.2, R66.1, U31.1
unnamed: S19.3, U34.RES
unnamed: C69.+, C74.1, R66.2, S20.3, S20.6, U31.2, U31.4
unnamed: J19.SHLD1, J19.SHLD2, J19.SHLD3, J19.SHLD4, SHLD6.2
unnamed: S20.2, S20.5, S21.2, S21.5
unnamed: S21.1, S21.4
unnamed: D8.A, R71.1
unnamed: C88.1, R75.2, R76.1, U36.1
unnamed: S22.3, U39.RES
unnamed: C80.+, C85.1, R76.2, S23.3, S23.6, U36.2, U36.4
unnamed: J22.SHLD1, J22.SHLD2, J22.SHLD3, J22.SHLD4, SHLD7.2
unnamed: S23.2, S23.5, S24.2, S24.5
unnamed: S24.1, S24.4
PICO: U1.D11, U3.7
PICO1: U7.7, U9.D11
PICO2: U12.7, U14.D11
PICO3: U17.7, U19.D11
PICO4: U22.7, U24.D11
PICO5: U27.7, U29.D11
PICO6: U32.7, U34.D11
PICO7: U37.7, U39.D11
PICO-IN: U3.6, U5.16
PICO-IN1: U7.6, U10.16
PICO-IN2: U12.6, U15.16
PICO-IN3: U17.6, U20.16
PICO-IN4: U22.6, U25.16
PICO-IN5: U27.6, U30.16
PICO-IN6: U32.6, U35.16
PICO-IN7: U37.6, U40.16
POCI: U1.D12, U5.15
POCI1: U9.D12, U10.15
POCI2: U14.D12, U15.15
POCI3: U19.D12, U20.15
POCI4: U24.D12, U25.15
POCI5: U29.D12, U30.15
POCI6: U34.D12, U35.15
POCI7: U39.D12, U40.15
RESET: R4.1, U1.D7, U3.9
RESET1: R19.1, U7.9, U9.D7
RESET2: R29.1, U12.9, U14.D7
RESET3: R39.1, U17.9, U19.D7
RESET4: R49.1, U22.9, U24.D7
RESET5: R59.1, U27.9, U29.D7
RESET6: R69.1, U32.9, U34.D7
RESET7: R79.1, U37.9, U39.D7
RESET-IN: U3.10, U5.12
RESET-IN1: U7.10, U10.12
RESET-IN2: U12.10, U15.12
RESET-IN3: U17.10, U20.12
RESET-IN4: U22.10, U25.12
RESET-IN5: U27.10, U30.12
RESET-IN6: U32.10, U35.12
RESET-IN7: U37.10, U40.12
SCK: U1.D13, U3.3
SCK1: U7.3, U9.D13
SCK2: U12.3, U14.D13
SCK3: U17.3, U19.D13
SCK4: U22.3, U24.D13
SCK5: U27.3, U29.D13
SCK6: U32.3, U34.D13
SCK7: U37.3, U39.D13
SCK-IN: U3.2, U5.13
SCK-IN1: U7.2, U10.13
SCK-IN2: U12.2, U15.13
SCK-IN3: U17.2, U20.13
SCK-IN4: U22.2, U25.13
SCK-IN5: U27.2, U30.13
SCK-IN6: U32.2, U35.13
SCK-IN7: U37.2, U40.13
VBCOMP: C3.1, U5.22
VBCOMP1: C18.1, U10.22
VBCOMP2: C29.1, U15.22
VBCOMP3: C40.1, U20.22
VBCOMP4: C51.1, U25.22
VBCOMP5: C62.1, U30.22
VBCOMP6: C73.1, U35.22
VBCOMP7: C84.1, U40.22
VBUS: F1.1, J1.VBUS1, J1.VBUS2
VBUS1: F2.1, J4.VBUS1, J4.VBUS2
VBUS2: F3.1, J7.VBUS1, J7.VBUS2
VBUS3: F4.1, J10.VBUS1, J10.VBUS2
VBUS4: F5.1, J13.VBUS1, J13.VBUS2
VBUS5: F6.1, J16.VBUS1, J16.VBUS2
VBUS6: F7.1, J19.VBUS1, J19.VBUS2
VBUS7: F8.1, J22.VBUS1, J22.VBUS2
VDD: F1.2, R9.2, R10.2, S5.3, S5.6, U6.1, U6.3
VDD1: F2.2, R17.2, R18.2, S6.3, S6.6, U8.1, U8.3
VDD2: F3.2, R27.2, R28.2, S9.3, S9.6, U13.1, U13.3
VDD3: F4.2, R37.2, R38.2, S12.3, S12.6, U18.1, U18.3
VDD4: F5.2, R47.2, R48.2, S15.3, S15.6, U23.1, U23.3
VDD5: F6.2, R57.2, R58.2, S18.3, S18.6, U28.1, U28.3
VDD6: F7.2, R67.2, R68.2, S21.3, S21.6, U33.1, U33.3
VDD7: F8.2, R77.2, R78.2, S24.3, S24.6, U38.1, U38.3
VIN: C1.1, C6.+, U1.VIN, U2.3
VIN1: C13.+, C20.1, U4.3, U9.VIN
VIN2: C24.+, C31.1, U11.3, U14.VIN
VIN3: C35.+, C42.1, U16.3, U19.VIN
VIN4: C46.+, C53.1, U21.3, U24.VIN
VIN5: C57.+, C64.1, U26.3, U29.VIN
VIN6: C68.+, C75.1, U31.3, U34.VIN
VIN7: C79.+, C86.1, U36.3, U39.VIN
XI: C10.1, U5.24, Y1.P3
XI1: C12.1, U10.24, Y2.P3
XI2: C23.1, U15.24, Y3.P3
XI3: C34.1, U20.24, Y4.P3
XI4: C45.1, U25.24, Y5.P3
XI5: C56.1, U30.24, Y6.P3
XI6: C67.1, U35.24, Y7.P3
XI7: C78.1, U40.24, Y8.P3
XO: C9.1, U5.25, Y1.P1
XO1: C16.1, U10.25, Y2.P1
XO2: C27.1, U15.25, Y3.P1
XO3: C38.1, U20.25, Y4.P1
XO4: C49.1, U25.25, Y5.P1
XO5: C60.1, U30.25, Y6.P1
XO6: C71.1, U35.25, Y7.P1
XO7: C82.1, U40.25, Y8.P1

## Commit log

2022-09-07 Created schematic and project folders
    Created initial folder structure with schematic (frame, name, date, and version number have been added)
    [USB-C_Host_Shield.sch]
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2022-09-08 Updates to schematic, added datasheets
    Continued work on the schematic, and added the 3 datasheets for the 3 used IC's on the board for power and data processing.
    [USB-C_Host_Shield.sch]
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2022-09-09 Worked on schematic
    Updated SFE library with new branch for the MAX3421 component then added it to this project. Continued with other parts of schematic and cleaning up for easier reading/documentation
    [USB-C_Host_Shield.sch]
2022-09-12 Updates to schematic, added documents
    Continued work on schematic, added programming guide to documents folder
    [USB-C_Host_Shield.sch]
2022-09-13 Updated schematic
    Continued work on schematic - shelving project for a little to define requirements a little more clearly
    [USB-C_Host_Shield.sch]
2022-09-20 Continued work on Layout
    Verify again 9/21 morning, but this should be nearly ready for layout
    [USB-C_Host_Shield.sch]
2022-09-21 Verified schematic and created layout
    Created layout document after verifying all schematic sections with datasheets.
    [USB-C_Host_Shield.brd, USB-C_Host_Shield.sch]
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2022-09-22 Continued with Layout
    Adjusted resistors and components to all be 0603 size (besides caps with dielectrics). Placed components in sections so all capacitors and other components are in the right areas.
    [USB-C_Host_Shield.brd, USB-C_Host_Shield.sch]
2022-09-23 Updated for Diff Pair Routing
    Updated the layer stackup and net classes for differential pair routing. Changed in both schematic and layout. Routed sensitive signals
    [USB-C_Host_Shield.brd, USB-C_Host_Shield.sch]
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2022-09-26 Continued Layout
    Continued with layout, added GND polygons - need to finish airwires and creating keepout layers
    [USB-C_Host_Shield.brd, USB-C_Host_Shield.sch]
2022-09-28 Approved and worked through errors
    Worked through and approved many ERC and DRC Errors. Ready for design review.
    [USB-C_Host_Shield.brd, USB-C_Host_Shield.sch]
2022-09-28 Added aesthetics to board
    Adjusted rule in schematic to be more accurate to layout
    [USB-C_Host_Shield.brd]
2022-09-28 Added version number to copper on back
    Added V10 to back side for version number
    [USB-C_Host_Shield.brd]
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2022-09-28 Adjusted to JLC DRC
    Adjusted layout and spacing to be in check with the rules of minimum standards for JLCPCB for ordering.
    [USB-C_Host_Shield.brd]
2022-09-28 Adjusted DRC to allow VIN route
    Now able to route VIN because of the drill hits.
    [USB-C_Host_Shield.brd]
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2022-09-29 Adjusted design from comments
    Added switch in schematic for swap between 5V and VIN from Arduino, added more GND vias and adjusted traces for GND pour, changed schematic tags to flags rather than text, adjusted version number on the back of the board
    [USB-C_Host_Shield.brd, USB-C_Host_Shield.sch]
2022-09-29 Adjusted for design review
    Many changes for design have been completed - NOT READY FOR ORDER. See "USB-C PT2" design review document for further information on what needs to be completed.
    [USB-C_Host_Shield.brd, USB-C_Host_Shield.sch]
2022-10-03 Updates from design review
    Adjusted text in schematic to vector font, added pullup resistors to CC1 and CC2, changed power selection and power off section, added lines to silk screen GPIO pins
    [USB-C_Host_Shield.brd, USB-C_Host_Shield.sch]
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2022-10-05 Adjusted schematic with new changes for layout
    Changed the main power schema for the USB-C port
    [USB-C_Host_Shield.brd, USB-C_Host_Shield.sch]
2022-10-05 Completed action items
    Finished routing after adjusting design to comply with ERC and DRC.
    [USB-C_Host_Shield.brd, USB-C_Host_Shield.sch]
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2022-10-05 Added more GND vias and adjusted traces
    Continued adding GNDing vias with adjusted traces for more polygon connection
    [USB-C_Host_Shield.brd]
2022-10-05 GND vias and connection
    Adjusted for better connection and removed wire stubs
    [USB-C_Host_Shield.brd]
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2022-10-06 Further changes for design review made
    Working through SF Board Checklist now
    [USB-C_Host_Shield.brd, USB-C_Host_Shield.sch]
2022-10-06 Updates for design review notes
    Made more updates according to design review notes. Updated prod_id for the MAX3421
    [USB-C_Host_Shield.brd, USB-C_Host_Shield.sch]
2022-10-10 Finalized schematic
    Added new switch instead of trace jumper for power switch between VIN and 5V
    [USB-C_Host_Shield.brd, USB-C_Host_Shield.sch]
2022-10-10 Updated layout
    Completed layout changes from adding new switch and adjusting the silk screen to be buzzard labels
    [USB-C_Host_Shield.brd]
2022-10-10 Added product ID to R9 and R10
    Created new part in Sparkle for this 56k 0603 resistor that is already input. The new ID, RES-17211, was added to the part and going to be add to the SparkFun parts library after project is verified 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
    [USB-C_Host_Shield.brd, USB-C_Host_Shield.sch]
2022-10-10 Updated board for design review
    Updated for design review notes - primarily updating the Arduino shield with buzzard labels, adjusting components to have description, adjusting VDD to have the input after the main power switch, include the original designer, and adjusting label location for the power switches.
    [USB-C_Host_Shield.brd, USB-C_Host_Shield.sch]
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2022-10-11 Update measurements
    Remove measurements from Documents layer
    Add board dimensions to Measurements layer
    [USB-C_Host_Shield.brd]
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2022-11-07 VERSION NUMBER CHANGE
    This commit is to show this is the first change for the boards for their move to Reds after testing
    [USB-C_Host_Shield.brd]
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2022-11-16 Updates from testing
    Removed the schottky diode that was limiting the current, and replaced the fuse from the 550mA to the 750mA
    [USB-C_Host_Shield.brd, USB-C_Host_Shield.sch]
2022-11-28 Updated layout with correct cap value
    [USB-C_Host_Shield.brd, USB-C_Host_Shield.sch]
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2023-01-25 Changed R4 and R5 resistors
    Changed the value of R4 and R5 from 2.2k to 10k for fixing the LED power off issue from testing. Changed the schematic, board, and panel files for consistency across the project.
    [USB-C_Host_Shield-Panel.brd, USB-C_Host_Shield.brd, USB-C_Host_Shield.sch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]
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2024-08-06 Update LICENSE.md
    Removed unnecessary carriage returns
    Fixed Typo
    Added Markdown formatting to make it more readable on GitHub

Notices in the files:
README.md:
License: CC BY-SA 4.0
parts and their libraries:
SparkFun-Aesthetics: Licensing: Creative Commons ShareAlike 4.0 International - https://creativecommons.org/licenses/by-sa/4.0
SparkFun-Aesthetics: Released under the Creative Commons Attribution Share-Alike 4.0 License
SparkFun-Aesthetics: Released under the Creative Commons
